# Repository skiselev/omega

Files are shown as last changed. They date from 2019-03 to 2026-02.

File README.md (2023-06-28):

# Omega
Omega Home Computer

[Lea este documento en español](README_es.md)

## Introduction
This project is an open source implementation of an MSX2 compatible computer. The project is built using a combination of 1980's era components - Z80 CPU, V9958 VDP, AY-3-8910/YM2149F PSG, 8255 PPI, 7400-series logic, and some newer components, such as 512 KiB SRAM and 512 KiB Flash ROM and a few simple programmable logic devices (ATF16V8B SPLDs).

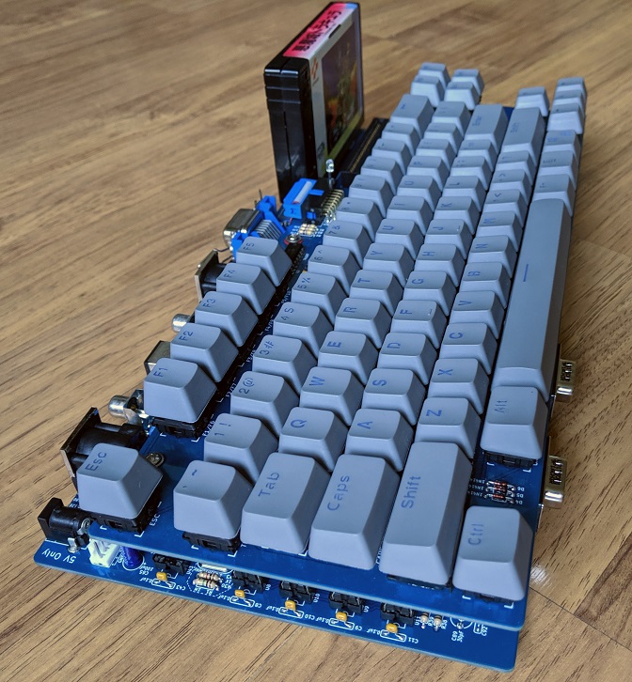
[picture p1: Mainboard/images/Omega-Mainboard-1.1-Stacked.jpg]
Omega System - Keyboard stacked on Main Board


## Status
* The project is completed, tested and works properly
* It is recommended to use the latest revision of the PCBs

## Documentation

[Keyboard](Keyboard.md)

[Main Board](Mainboard.md)

[Enclosure](Enclosure.md)

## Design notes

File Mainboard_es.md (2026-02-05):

# Omega Placa Base
Placa Base para el Omega Home Computer

[Read this document in English](Mainboard.md)

## Tabla de Contenido
* [Introducción](#introducción)
* [Especificaciones](#especificaciones)
* [Documentación del Hardware](#documentación-del-hardware)
  * [Esquema y diseño de la PCB](#esquema-y-diseño-de-la-pcb)
  * [Conectores](#conectores)
  * [Jumpers](#jumpers)
  * [Lista de componentes](#lista-de-componentes)
  * [Puertos de Entrada y Salida](#puertos-de-entrada-y-salida)
  * [Mapa de Slots](#mapa-de-slots)
* [Documentación del Firmware](#documentación-del-firmware)
  * [BIOS](#bios)
  * [Esquema de fusibles SPLD](#esquema-de-fusibles-spld)
* [Notas de la versión](#notas-de-la-versión)
  * [Cambios](#cambios)
  * [Problemas conocidos](#problemas-conocidos)

## Introducción
La Placa Base tiene implementada la funcionalidad del estándar MSX2*, tal como se describe en la siguiente sección de  [Especificaciones](#especificaciones). La Placa Base está diseñada para ser apilada bajo la placa del teclado para crear la típica forma de "Ordenador teclado" de los ordenadores domésticos de los 80.
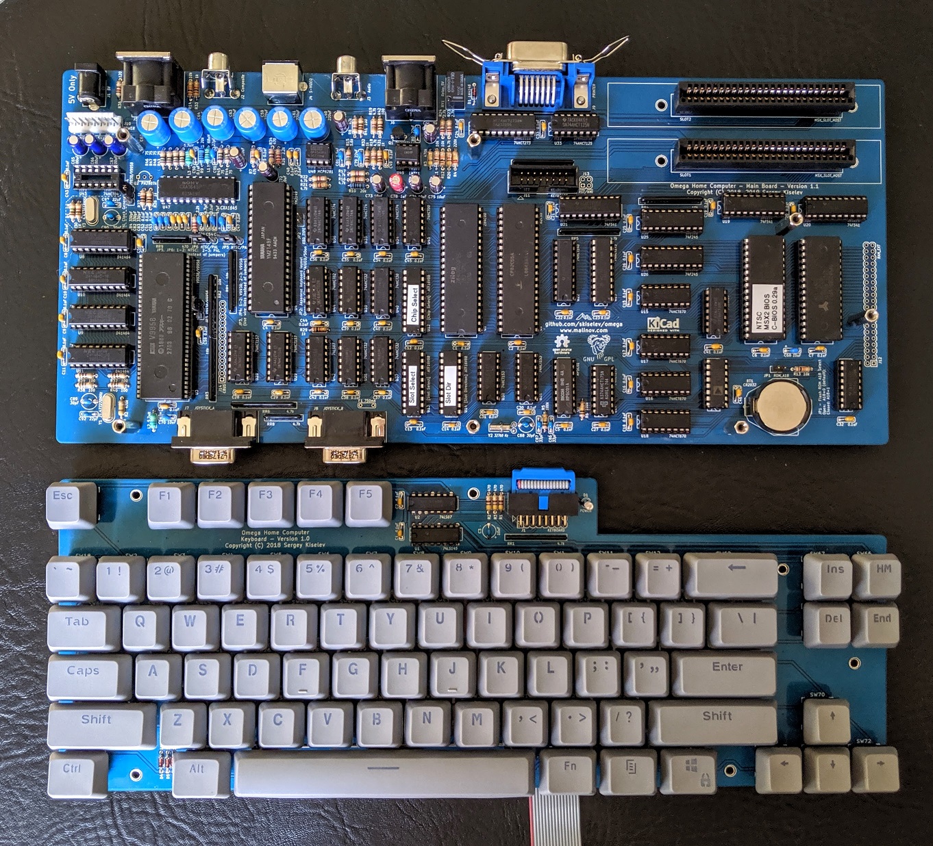
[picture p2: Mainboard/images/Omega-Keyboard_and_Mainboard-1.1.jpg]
Omega Mainboard connected to Keyboard
 

## Especificaciones
* Procesador: CPU Zilog Z80 (version CMOS - Z84C00) a 3.58 Mhz de reloj
* Memoria:
  * RAM: 512 KiB SRAM, ampliable a 4 MiB usando una placa hija opcional. Paginador de memoria compatible con MSX*. La RAM está mapeada en el slot 3-2
  * ROM: Flash ROM de 256 KiB o 512 KiB. La ROM está mapeada al slot 0 y los sub slots 3-0, 3-1 y 3-3.
* Video: VDP Yamaha V9958 o Yamaha V9938 
  * 128 KiB Video RAM
  * Salidas de video compuesto, S-Video, y RGB
* Audio: PSG Yamaha YM2149 o el AY-3-8910 de General Instruments.
* Dos slots para cartucho compatibles con MSX* 
* Teclado, Joysticks, e Interfaces para la Impresora y el reproductor de Cassette
* RTC: Ricoh RP5C01
* Supervisor del Microprocesador:
  * Generación de Reset
  * Battería de respaldo RTC
* BIOS: [C-BIOS](http://cbios.sourceforge.net/). Compatible con BIOS de ordenadores originales MSX2* con organización de slots y especificaciones de hardware similares como por ejemplo [Sanyo* PHC-23J](https://www.msx.org/wiki/Sanyo_PHC-23J)

## Documentación del Hardware

### Esquema y diseño de la PCB

[Esquematico - Version 1.5](Mainboard/KiCad/Omega-Mainboard-Schematic-1.5.pdf)

[Diseño de la PCB - Version 1.5](Mainboard/KiCad/Omega-Mainboard-Board-1.5.pdf)

### Conectores

#### J1 - Power (5V)
Conecta una fuente de alimentación regulada a +5V a este conector.

Nota: Los componentes de la placa usan solo voltajes de 5V. Algunos cartuchos pueden necesitar 12V/-12V adicionales. El conector J10 debe usarse en este caso

Pin | Descripción     
--- | ---------------
Pin (contacto interno) | Power: 5V (terminal positivo)
Tambor / Pantalla      |	Power: GND (terminal negativo)

#### J2 - Video Compuesto

Pin | Descripción     
--- | ---------------
Pin (contacto interno)| Salida: Video Compuesto
Anillo / Pantalla     |	Power: GND

#### J3 - Audio

Pin | Descripción     
--- | ---------------
Tip (contacto interno)| Salida: Audio (nivel de línea)
Anillo / Pantalla     |	Power: GND

#### J4 - S-Video

Pin | Descripción     
--- | ---------------
1, 2 | Power: GND
3    |	Salida: Luminancia (intensidad)
4    | Salida: Chrominancia (color)

#### J5 - RGB Conector
Pin | Descripción     
--- | ---------------
1   | Power: GND
2   |	Salida: Audio (nivel de línea)
3   |	Salida: AV (4.55V)
4   |	Salida: Video Compuesto
5   |	Salida: YS (3 V)
6   |	Salida: Rojo
7   | Salida: Verde
8   | Salida: Azul

#### J6 - Cassette Conector
Pin | Descripción     
--- | ---------------
1, 2, 3, 8   | Power: GND
4   |	Salida: Salida de audio hacia el grabador de cassette (nivel de microfono)
5   |	Entrada: Entrada de audio desde el grabador de cassette (nivel de línea)
6   |	Salida: Relé - Control de Motor
7   | Salida: Relé - Control de Motor

#### J7, J8 - Conectores de Joystick
Pin | Descripción     
--- | ---------------
1   | Entrada: Avanzar (norte / arriba)
2   | Entrada: Retroceder (sur / abajo)
3   | Entrada: Izquierda (oeste)
4   | Entrada: Derecha (este)
5   | Power: 5V
6   | Entrada: Botón 1
7   | Entrada: Botón 2
8   | Salida: Selección de Joystick
9   | Power: GND (tierra)

#### J9 - Conector de Impresora
Pin | Descripción     
--- | ---------------
1   | Salida: /STROBE (pulso)
2   | Salida: D0
3   | Salida: D1
4   | Salida: D2
5   | Salida: D3
6   | Salida: D4
7   | Salida: D5
8   | Salida: D6
9   | Salida: D7
10  | No conectado
11  | Entrada: BUSY (ocupado)
12  | No conectado
13  | No conectado
14  | Power: GND (tierra)

#### J10 - Power (5V, 12V, -12V)
Conecta una fuente de alimentación regulada 5V/12V/-12V a este conector.

Pin | Descripción     
--- | ---------------
1, 2, 3 | Power: GND
4, 5, 6 |	Power: 5V
7   |	Power: 12V
8   |	Power: -12V

#### J11 - Interfaz de Teclado 
Pin | Descripción     | Pin | Descripción
--- | --------------- | --- | ----------------
1   | Entrada: Columna 0 | 2   | Power: 5V
3   |	Entrada: Columna 1 | 4   | Salida: fila A
5   |	Entrada: Columna 2 | 6   | Salida: fila B
7   |	Entrada: Columna 3 | 8   | Salida: fila C
9   |	Entrada: Columna 4 | 10  | Salida: fila D
11  |	Entrada: Columna 5 | 12  | Salida: Bloq May LED
13  | Entrada: Columna 6 | 14  | Salida: Kana/Code LED
15  | Entrada: Columna 7 | 16  | Power: GND

#### J12 - Extensor SRAM
Pin | Descripción      | Pin | Descripción
--- | ---------------- | --- | ----------------
1   | Power: 5V        | 2   | Power: 5V
3   |	Salida: /RAM2_CS | 4   | Salida: /RAM1_CS
5   |	Salida: /RAM4_CS | 6   | Salida: /RAM3_CS
7   |	Salida: /RAM6_CS | 8   | Salida: /RAM5_CS
9   |	Salida: RAM_A18  | 10  | Salida: /RAM7_CS
11  |	Salida: RAM_A16  | 12  | Salida: RAM_A15 
13  | Salida: RAM_A14  | 14  | Salida: RAM_A17 
15  | Salida: A12      | 16  | Salida: /WR
17  | Salida: A7       | 18  | Salida: A13
19  | Salida: A6       | 20  | Salida: A8
21  | Salida: A5       | 22  | Salida: A9
23  | Salida: A4       | 24  | Salida: A11
25  | Salida: A3       | 26  | Salida: /RD
27  | Salida: A2       | 28  | Salida: A10
29  | Salida: A1       | 30  | Bi-direccional: MD7
31  | Salida: A0       | 32  | Bi-direccional: MD6
33  | Bi-direccional: MD0 | 34  | Bi-direccional: MD5
35  | Bi-direccional: MD1 | 36  | Bi-direccional: MD4
37  | Bi-direccional: MD2 | 38  | Bi-direccional: MD3
39  | Power: GND       | 40  | Power: GND

#### J13 - Conector /RST and /NMI
Pin | Descripción     | Pin | Descripción
--- | --------------  | --- | -----------
1   | In/Out: /RESET  | 2   | Power: GND
3   | Entrada: /NMI   | 4   | Power: GND

#### J14 - Bus de color VDP 
Pin | Descripción
--- | -----------
1   | Power: 5V
2   | Salida: /DHCLK
3   | Salida: /DLCLK
4   | Salida: CBDR
5   | In/Out: CB7
6   | In/Out: CB6
7   | In/Out: CB5
8   | In/Out: CB4
9   | In/Out: CB3
10  | In/Out: CB2
11  | In/Out: CB1
12  | In/Out: CB0
13  | Power: GND

### Jumpers

#### JP1 - ROM_A18
JP1 selecciona la seccion de 256 KiB (mitad inferior o mitad superiro) de la memoria Flash ROM que se mapea como ROM del sistema o slot.

Jumper Position	| Descripción
--------------- | -----------
Abierto*        | selecciona las direcciones 0x00000 - 0x3FFFF del chip ROM
Cerrado         | selecciona las direcciones 0x40000 - 0x7FFFF del chip ROM

#### JP2 - KBD_TYPE
JP2 selecciona la configuración de teclado japonés

Jumper Position | Descripción
--------------- | -----------
Abierto*        | configuración JIS
Cerrado         | configuración ANSI/AIUEO/50on

#### JP3, JP4 - V9938/V9958
JP3 y JP4 seleccionan el tipo de VDP a usar. JP3 conecta el Pin 21 del VDP, bien con una resistencia de 470 ohm (pull-up) (V9938, Salida de video compuesto deshabilitada), o bien a 5V (V9958, alimentación de DAC). JP4 selecciona si la salida CSYNC del VDP va directamente al codificador RGB (V9958) o a un circuito convertidor de nivel (V9938).

*Aviso: Un ajuste erroneo del JP3 dañará el VDP*

Posición del Jumper | Descripción
------------------- | -----------
1-2                 | V9938 VDP
2-3                 | V9958 VDP

#### JP5, JP6 - NTSC/PAL
Los Jumpers JP5 y JP6 seleccionan el sistema codificacior de color para la salida de Video. Para ser más específicos, el JP5 configura el codificador RGB y el JP6 selecciona la frecuencia sub-portadora de color.

*Nota: Algunos componentes se usan solamente para generar la frecuencia sub-portadora del sistema PAL y pueden ser omitidos si se usa el codificador NTSC. Mira la Lista de componentes para más información*

Posición del Jumper| Descripción
------------------ | -----------
1-2                | NTSC
2-3                | PAL

### Lista de Componentes

[Proyecto de Placa Base para Omega en Mouser.com](https://www.mouser.com/ProjectManager/ProjectDetail.aspx?AccessID=11fd34d22c) - Puedes ver y encargar todos los componentes exceptuando la PCB, El Yamaha VDP V9958, el Ricoh RTC RP5C01, La DRAM NEC D41464, el Codificador RGB Sony CXA1645P y la pila CR2032.

Component type     | Reference | Description                                 | Quantity | Possible sources and notes
------------------ | --------- | ------------------------------------------- | -------- | --------------------------
PCB                |           | PCB Omega Placa Base - Version 1.1          | 1        | dirigirse a [RetroBrew Computers Board Inventory](https://retrobrewcomputers.org/doku.php?id=boardinventory) para instrucciones de pedido, o pedir al fabricante PCB de tu elección usando los Gerber proveidos o los ficheros de KiCad.
Circuito Integrado | U1        | Z80 CPU, CMOS, 40 pin DIP - Z84C00xxPEG     | 1        | Mouser [692-Z84C0010PEG](https://www.mouser.com/ProductDetail/692-Z84C0010PEG)
Circuito Integrado | U2        | 82C55 PPI, CMOS, 40 pin DIP - CP82C55AZ     | 1        | Mouser [968-CP82C55A-5Z](https://www.mouser.com/ProductDetail/968-CP82C55A-5Z)
Circuito Integrado | U3        | V9958 VDP, 64 pin DIP                       | 1        | eBay. Nota: V9938 VDP puede ser utilizada en su lugar
Circuito Integrado | U4        | YM2149 PSG, 40 pin DIP or AY-3-8910         | 1        | eBay
Circuito Integrado | U5        | RP5C01 RTC, 18 pin DIP                      | 1        | eBay
Circuito Integrado | U6        | 512 KiB Flash ROM, 32 pin DIP - SST39SF040  | 1        | Mouser [804-39SF0407CPHE](https://www.mouser.com/ProductDetail/804-39SF0407CPHE)
Circuito Integrado | U7        | 512 KiB SRAM, 32 pin DIP - AS6C4008         | 1        | Mouser [913-AS6C4008-55PCN](https://www.mouser.com/ProductDetail/913-AS6C4008-55PCN)
Circuito Integrado | U8 - U11  | D41464, 64K x 4 DRAM, 18 pin DIP            | 4        | eBay
Circuito Integrado | U12 - U14 | Simple Programmable Logic Device - ATF16V8B | 3        | Mouser [556-AF16V8B15PU](https://www.mouser.com/ProductDetail/556-AF16V8B15PU)
Circuito Integrado | U15 - U18 | 4-by-4 Register File - 74HC670, 16 pin DIP  | 4        | Mouser [595-CD74HC670E](https://www.mouser.com/ProductDetail/595-CD74HC670E)
Circuito Integrado | U19 - U21 | 74F541, 20 pin DIP                          | 3        | Mouser [595-SN74F541N](https://www.mouser.com/ProductDetail/595-SN74F541N)
Circuito Integrado | U22       | 74HCT540, 20 pin DIP                        | 1        | Mouser [595-SN74HCT540N](https://www.mouser.com/ProductDetail/595-SN74HCT540N)
Circuito Integrado | U23, U24  | 74HCT273, 20 pin DIP                        | 2        | Mouser [595-SN74HCT273N](https://www.mouser.com/ProductDetail/595-SN74HCT273N). Nota U24 es opcional - soporte a puerto impresora.
Circuito Integrado | U25, U26  | 74F245, 20 pin DIP                          | 2        | Mouser [595-SN74F245N](https://www.mouser.com/ProductDetail/595-SN74F245N)
Circuito Integrado | U27       | 74HCT175, 16 pin DIP                        | 1        | Mouser [595-CD74HCT175E](https://www.mouser.com/ProductDetail/595-CD74HCT175E)
Circuito Integrado | U28, U29  | 74HCT157, 16 pin DIP                        | 2        | Mouser [595-SN74HCT157N](https://www.mouser.com/ProductDetail/595-SN74HCT157N)
Circuito Integrado | U30, U31  | 74HCT153, 16 pin DIP                        | 2        | Mouser [595-CD74HCT153E](https://www.mouser.com/ProductDetail/595-CD74HCT153E)
Circuito Integrado | U32       | 74AHCT138, 16 pin DIP                       | 1        | Mouser [595-SN74AHCT138N](https://www.mouser.com/ProductDetail/595-SN74AHCT138N)
Circuito Integrado | U33       | 74AHCT125, 14 pin DIP                       | 1        | Mouser [595-SN74AHCT125N](https://www.mouser.com/ProductDetail/595-SN74AHCT125N). Nota U33 es opcional - soporte a puerto impresora.
Circuito Integrado | U34 - U36 | Dual Flip Flop - 74HCT74, 14 pin DIP        | 3        | Mouser [595-SN74HCT74N](https://www.mouser.com/ProductDetail/595-SN74HCT74N)
Circuito Integrado | U37 - U39 | 74AHCT32, 14 pin DIP                        | 3        | Mouser [595-SN74AHCT32N](https://www.mouser.com/ProductDetail/595-SN74AHCT32N)
Circuito Integrado | U40, U41  | 74HCT30, 14 pin DIP                         | 2        | Mouser [595-CD74HCT30E](https://www.mouser.com/ProductDetail/595-CD74HCT30E)
Circuito Integrado | U42       | 74LS07, 14 pin DIP                          | 1        | Mouser [595-SN74LS07N](https://www.mouser.com/ProductDetail/595-SN74LS07N)
Circuito Integrado | U43       | 74HCT04, 14 pin DIP                         | 1        | Mouser [595-SN74HCT04N](https://www.mouser.com/ProductDetail/595-SN74HCT04N)
Circuito Integrado | U44       | 74AHCT02, 14 pin DIP                        | 1        | Mouser [595-SN74AHCT02N](https://www.mouser.com/ProductDetail/595-SN74AHCT02N)
Circuito Integrado | U45       | 74HCT00, 14 pin DIP                         | 1        | Mouser [595-SN74HCT00N](https://www.mouser.com/ProductDetail/595-SN74HCT00N)
Circuito Integrado | U46       | Microprocessor Supervisory Circuit - ADM691A | 1        | Mouser [584-ADM691AANZ](https://www.mouser.com/ProductDetail/584-ADM691AANZ); Alternativas válidas: MAX691, LTC691, ADM691
Circuito Integrado | U47       | Sony CXA1645P RGB Encoder, 24 pin DIP-400   | 1        | eBay
Circuito Integrado | U48       | MCP6281-E/P Operational Amplifier, 8 pin DIP | 1       | Mouser [579-MCP6281-E-P](https://www.mouser.com/ProductDetail/579-MCP6281-E-P)
Circuito Integrado | U49       | LM311N, Voltage Comparator, 8 pin DIP       | 1        | Mouser [926-LM311N-NOPB](https://www.mouser.com/ProductDetail/926-LM311N-NOPB). Nota U49 es opcional - soporte grabador cassette.
Condensador        | C1 - C58  | 0.1 uF, MLCC, 5 mm Pitch                    | 58       | Mouser [594-K104K15X7RF53H5](https://www.mouser.com/ProductDetail/594-K104K15X7RF53H5)
Condensador        | C59 - C64 | 220 uF, Electrolitico                       | 6        | Mouser [647-UBW1E221MPD](https://www.mouser.com/ProductDetail/647-UBW1E221MPD). Nota C62 - C64 opcional - soporte salida RGB
Condensador        | C65 - C67 | 100 uF, 16V, Polimero organico de aluminio  | 3        | Mouser [80-A750EK107M1CAAE18](https://www.mouser.com/ProductDetail/80-A750EK107M1CAAE18)
Condensador        | C68 - C70 | 10 uF, MLCC, 5 mm Pitch                     | 3        | Mouser [810-FG28X5R1E106MR00](https://www.mouser.com/ProductDetail/810-FG28X5R1E106MR00). Nota C71 opcional - soporte grabador cassette.
Condensador        | C71 - C77 | 10 uF, Electrolytic                         | 7        | Mouser [667-EEU-FR1H100](https://www.mouser.com/ProductDetail/667-EEU-FR1H100). Nota C71 opcional - soporte grabador cassette.
Condensador        | C78       | 1 uF, Electrolytic                          | 1        | Mouser [710-860020672005](https://www.mouser.com/ProductDetail/710-860020672005). Nota C78 opcional - soporte grabador cassette.
Condensador        | C79, C80  | 22 nF, MLCC, 5 mm Pitch                     | 2        | Mouser [810-FG28X7R1H223KNT0](https://www.mouser.com/ProductDetail/810-FG28X7R1H223KNT0). Nota C79, C80 opcional - soporte grabador cassette.
Condensador        | C81       | 1.5 nF, MLCC, 5 mm Pitch                    | 1        | Mouser [810-FG28C0G1H152JNT0](https://www.mouser.com/ProductDetail/810-FG28C0G1H152JNT0)
Condensador        | C82 - C84 | 330 pF, MLCC, 5 mm Pitch                    | 3        | Mouser [810-FG28C0G1H331JNT0](https://www.mouser.com/ProductDetail/810-FG28C0G1H331JNT0)
Condensador        | C85       | 47 pF, MLCC, 5 mm Pitch                     | 1        | Mouser [810-FG28C0G1H470JNT0](https://www.mouser.com/ProductDetail/810-FG28C0G1H470JNT0)
Condensador        | C86, C87  | 33 pF, MLCC, 5 mm Pitch                     | 2        | Mouser [810-FG28C0G1H330JNT0](https://www.mouser.com/ProductDetail/810-FG28C0G1H330JNT0)
Condensador        | C88 - C90 | 30 pF, Trim Capactiors, 5 mm Pitch          | 3        | DigiKey [2447-GKG30015-ND](https://www.digikey.es/es/products/detail/ew-electronics/GKG30015/11689271). Nota: Puede ser reemplazado por Mouser [810-FG28C0G2A270JNT0](https://www.mouser.com/ProductDetail/810-FG28C0G2A270JNT0) si no es necesario ajustar la frecuencia portadora de color.
Condensador        | C91       | 27 pF, MLCC, 5 mm Pitch                     | 1        | Mouser [810-FG28C0G2A270JNT0](https://www.mouser.com/ProductDetail/810-FG28C0G2A270JNT0). Nota C91 debe ser de 18 pF para soporte PAL.
Condensador        | C92, C93  | 22 pF, MLCC, 5 mm Pitch                     | 2        | Mouser [810-FG28C0G1H220JNT0](https://www.mouser.com/ProductDetail/810-FG28C0G1H220JNT0)
Condensador        | C94       | 4.7 pF, MLCC, 5 mm Pitch                    | 1        | Mouser [810-FG28C0G1H4R7CNT0](https://www.mouser.com/ProductDetail/810-FG28C0G1H4R7CNT0)
Matriz Resistencias| RR1 - RR4 | 10 kohm, en bus, 10 pin SIP                 | 4        | Mouser [652-4610X-1LF-10K](https://www.mouser.com/ProductDetail/652-4610X-1LF-10K) o Mouser [652-4610X-AP1-103LF](https://www.mouser.com/ProductDetail/652-4610X-AP1-103LF)
Matriz Resistencias| RR5 - RR7  | 4.7 kohm, en bus, 10 pin SIP               | 3        | Mouser [652-4610X-1LF-4.7K](https://www.mouser.com/ProductDetail/652-4610X-1LF-4.7K) o Mouser [652-4610X-AP1-472LF](https://www.mouser.com/ProductDetail/652-4610X-AP1-472LF)
Matriz Resistencias| RR8       | 4.7 kohm, en bus, 6 pin SIP                 | 1        | Mouser [652-4606X-1LF-4.7K](https://www.mouser.com/ProductDetail/652-4606X-1LF-4.7K) o Mouser [652-4606X-AP1-472LF](https://www.mouser.com/ProductDetail/652-4606X-AP1-472LF)
Matriz Resistencias| RR9       | 470 ohm, en bus, 6 pin SIP                  | 1        | Mouser [652-4606X-1LF-470](https://www.mouser.com/ProductDetail/652-4606X-1LF-470) o Mouser [652-4606X-AP1-471LF](https://www.mouser.com/ProductDetail/652-4606X-AP1-471LF)
Resistencia        | R1        | 1 Mohm, axial                               | 1        | Mouser [603-MFR-25FBF52-1M](https://www.mouser.com/ProductDetail/603-MFR-25FBF52-1M). Nota R1 is opcional - soporte PAL.
Resistencia        | R2, R3    | 470 kohm, axial                             | 2        | Mouser [603-MFR-25FBF52-470K](https://www.mouser.com/ProductDetail/603-MFR-25FBF52-470K)
Resistencia        | R4        | 220 kohm, axial                             | 1        | Mouser [603-MFR-25FBF52-220K](https://www.mouser.com/ProductDetail/603-MFR-25FBF52-220K)
Resistencia        | R5, R6    | 100 kohm, axial                             | 2        | Mouser [603-MFR-25FBF52-100K](https://www.mouser.com/ProductDetail/603-MFR-25FBF52-100K)
Resistencia        | R7, R8    | 47 kohm, axial                              | 2        | Mouser [603-MFR-25FBF52-47K](https://www.mouser.com/ProductDetail/603-MFR-25FBF52-47K)
Resistencia        | R9, R10   | 20 kohm, 1% tolerancia, axial               | 2        | Mouser [603-MFR-25FBF52-20K](https://www.mouser.com/ProductDetail/603-MFR-25FBF52-20K). Nota R9 debe ser 16 kohm, 1% para soporte PAL.
Resistencia        | R11 - R14 | 10 kohm, axial                              | 4        | Mouser [603-MFR-25FBF52-10K](https://www.mouser.com/ProductDetail/603-MFR-25FBF52-10K). Nota R11, R12 son opcionales - soporte grabador cassette.  Nota R14 es opcional - soporte salida RGB.
Resistencia        | R15       | 5.6 kohm, axial                             | 1        | Mouser [603-MFR-25FBF52-5K6](https://www.mouser.com/ProductDetail/603-MFR-25FBF52-5K6)
Resistencia        | R16 - R22 | 4.7 kohm, axial                             | 7        | Mouser [603-MFR-25FBF52-4K7](https://www.mouser.com/ProductDetail/603-MFR-25FBF52-4K7). Note R18 - R20 son opcionales - soporte grabador cassette.
Resistencia        | R23, R24  | 2.7 kohm, axial                             | 2        | Mouser [603-MFR-25FBF52-2K7](https://www.mouser.com/ProductDetail/603-MFR-25FBF52-2K7). Note R23, R24 son opcionales - soporte grabador cassette.
Resistencia        | R25, R26  | 2.2 kohm, axial                             | 2        | Mouser [603-MFR-25FBF52-2K2](https://www.mouser.com/ProductDetail/603-MFR-25FBF52-2K2)
Resistencia        | R27 - R33 | 1 kohm, axial                               | 7        | Mouser [603-MFR-25FBF52-1K](https://www.mouser.com/ProductDetail/603-MFR-25FBF52-1K). Nota R31, R32 son opcionales - soporte grabador cassette. Nota R33 es opcional - soporte salida RGB.
Resistencia        | R34       | 470 ohm, axial                              | 1        | Mouser [603-MFR-25FBF52-470R](https://www.mouser.com/ProductDetail/603-MFR-25FBF52-470R) 
Resistencia        | R35       | 180 ohm, axial                              | 1        | Mouser [603-MFR-25FBF52-180R](https://www.mouser.com/ProductDetail/603-MFR-25FBF52-180R). Nota R35 es opcional - soporte salida RGB.
Resistencia        | R36       | 120 ohm, axial                              | 1        | Mouser [603-MFR-25FBF52-120R](https://www.mouser.com/ProductDetail/603-MFR-25FBF52-120R). Nota R36 es opcional - soporte salida RGB.
Resistencia        | R37 - R42 | 100 ohm, axial                              | 6        | Mouser [603-MFR-25FBF52-100R](https://www.mouser.com/ProductDetail/603-MFR-25FBF52-100R). Nota R42 es opcional - soporte grabador cassette.
Resistencia        | R43 - R48 | 75 ohm, axial                               | 6        | Mouser [603-MFR-25FBF52-75R](https://www.mouser.com/ProductDetail/603-MFR-25FBF52-75R). Nota R46 - R48 opcional - soporte salida RGB.
Rele               | RY1       | 5V SPDT rele                                | 1        | Mouser [653-G5V-1-DC5](https://www.mouser.com/ProductDetail/653-G5V-1-DC5) o Mouser [653-G5V-1-T90-DC5](https://www.mouser.com/ProductDetail/653-G5V-1-T90-DC5)
Inductor           | L1        | 68 uH, axial                                | 1        | Mouser [542-78F680-RC](https://www.mouser.com/ProductDetail/542-78F680-RC)
Inductor           | L2, L3    | 5.7 uH, axial                               | 2        | Mouser [542-78F5R6J-RC](https://www.mouser.com/ProductDetail/542-78F5R6J-RC)
Diodo              | D1        | 1N4148                                      | 1        | Mouser [512-1N4148TR](https://www.mouser.com/ProductDetail/512-1N4148TR). Nota D1 es opcional - soporte grabador cassette.
Transistor         | Q1, Q2    | PN2907A                                     | 2        | Mouser [512-PN2907ATF](https://www.mouser.com/ProductDetail/512-PN2907ATF). Nota Q1 es opcional - soporte grabador cassette.
Cristal            | Y1        | 21.477270 MHz                               | 1        | Mouser [695-HC49US-214-U](https://www.mouser.com/ProductDetail/695-HC49US-214-U)
Cristal            | Y2        | 32768 Hz                                    | 1        | Mouser [815-AB38T-32.768KHZ](https://www.mouser.com/ProductDetail/815-AB38T-32.768KHZ)
Cristal            | Y3        | 4.433618 MHz                                | 1        | Mouser [520-HCU443-20X](https://www.mouser.com/ProductDetail/520-HCU443-20X). Nota Y3 es opcional - soporte PAL.
Fusible            | F1        | 750 mA, radial, 5 mm pitch                  | 1        | Mouser [650-RUSBF075-2](https://www.mouser.com/ProductDetail/650-RUSBF075-2)
Conector           | J1        | DC Power Jack, 2mm                          | 1        | Mouser [806-KLDX-0202-A](https://www.mouser.com/ProductDetail/806-KLDX-0202-A)
Conector           | J2        | conector RCA Phono, Amarillo                | 1        | Mouser [490-RCJ-014](https://www.mouser.com/ProductDetail/490-RCJ-014)
Conector           | J2        | conector RCA Phono, Blanco                  | 1        | Mouser [490-RCJ-013](https://www.mouser.com/ProductDetail/490-RCJ-013)
Conector           | J4        | Mini DIN 4-pos, angulo recto, montaje PCB   | 1        | Mouser [490-MD-40SM](https://www.mouser.com/ProductDetail/490-MD-40SM)
Conector           | J5, J6    | DIN 8-pos, angulo recto, montaje PCB        | 2        | Mouser [490-SDF-80J](https://www.mouser.com/ProductDetail/490-SDF-80J). Nota J5 es opcional - soporte RGB; J6 es opcional - soporte grabador cassette.
Conector           | J7, J8    | Sub-D DE9M, angulo recto, montaje PCB       | 2        | Mouser [523-L717SDE09P1ACH3R](https://www.mouser.com/ProductDetail/523-L717SDE09P1ACH3R)
Conector           | J9        | Micro Ribbon 14-pos, hembra, ang. recto, montaje PCB | 1        | Mouser [636-112-014-213R001](https://www.mouser.com/ProductDetail/636-112-014-213R001). Nota J9 es opcional - soporte puerto impresora.
Conector           | J10       | 8 pin conector bloqueo anclaje              | 1        | Mouser [571-6404568](https://www.mouser.com/ProductDetail/571-6404568)
Conector           | J11       | 2x8 pin header, shrouded                    | 1        | Mouser [710-61201621621](https://www.mouser.com/ProductDetail/710-61201621621)
Conector           | J12       | 2x20 pin zocalo                             | 1        | Mouser [517-929852-01-20-RB](https://www.mouser.com/ProductDetail/517-929852-01-20-RB)
Conector           | J13       | 2x2 pin header                              | 1        | Nota: Opcional /RESET y /NMI header
Conector           | J14       | 1x13 pin header                             | 1        | Note: Opcional conector Bus Color
Conector           | SLOT1, SLOT2 | conector 50 pin borde de tarjeta         | 2        | Mouser [571-5530843-5](https://www.mouser.com/ProductDetail/571-5530843-5)
Jumper             | JP1, JP2  | 2 pin header                                | 2        | Mouser [649-78229-102HLF](https://www.mouser.com/ProductDetail/649-78229-102HLF)
Jumper             | JP3 - JP6 | Wire link                                   | 4        | conexión por cable (puente)
Zocalo Bateria     | BT1       | Zocalo Bateria CR2032                       | 1        | Mouser [122-2420-GR](https://www.mouser.com/ProductDetail/122-2420-GR)
Bateria            | BT1       | CR2032 Batteria                             | 1        | Mouser [614-CR2032-200](https://www.mouser.com/ProductDetail/614-CR2032-200), [658-CR2032](https://www.mouser.com/ProductDetail/658-CR2032). Nota: No incluido en el projecto de Mouser Project debido a restricciones de envío.
Zocalo CI          | U1, U2, U4 | 40 pin DIP                                 | 3        | Mouser [517-4840-6000-CP](https://www.mouser.com/ProductDetail/517-4840-6000-CP)
Zocalo CI          | U3        | 64 pin DIP                                  | 1        | eBay
Zocalo CI          | U3        | 64 pin DIP (alternativa)                    | 1        | DigiKey [117-87-764-41-005101](https://www.digikey.es/es/products/detail/preci-dip/117-87-764-41-005101/3757318)
Zocalo CI          | U6, U7    | 32 pin DIP                                  | 2        | Mouser [517-4832-6000-CP](https://www.mouser.com/ProductDetail/517-4832-6000-CP)
Zocalo CI          | U47       | 24 pin DIP, 400 mil spacing                 | 1        | Mouser [517-4824-6000-CP](https://www.mouser.com/ProductDetail/517-4824-6000-CP) or [517-4824-3000-CP](https://www.mouser.com/ProductDetail/517-4824-3000-CP). Nota: Cortar el zocalo por la mitad. Si se usa un zócalo de tamaño 0.600", recortar el sobrante. Como alternativa soldar U47 (CXA1645P) sin zócalo.
Zocalo CI          | U47       | 24 pin DIP, 400 mil spacing (alternativa)   | 1        | DigiKey [110-93-424-41-001000](https://www.digikey.es/es/products/detail/mill-max-manufacturing-corp/110-93-424-41-001000/81797)
Zocalo CI          | U12 - U14, U19 - U26 | 20 pin DIP                       | 11       | Mouser [517-4820-3000-CP](https://www.mouser.com/ProductDetail/517-4820-3000-CP)
Zocalo CI          | U5, U8 - U11 | 18 pin DIP                               | 5        | Mouser [517-4818-3000-CP](https://www.mouser.com/ProductDetail/517-4818-3000-CP)
Zocalo CI          | U15 - U18, U27 - U32, U46 | 16 pin DIP                  | 11       | Mouser [517-4816-3000-CP](https://www.mouser.com/ProductDetail/517-4816-3000-CP)
Zocalo CI          | U33 - U45 | 14 pin DIP                                  | 13       | Mouser [517-4814-3000-CP](https://www.mouser.com/ProductDetail/517-4814-3000-CP)
Zocalo CI          | U48, U49  | 8 pin DIP                                   | 2        | Mouser [517-4808-3000-CP](https://www.mouser.com/ProductDetail/517-4808-3000-CP)

### Opciones de Configuración y Notas sobre la sustitución de Componentes

#### Soporte del Estándar de Video NTSC
La Placa Base del Omega puede ser configurada para funcionar tanto con el estándar de video NTSC (60 Hz) como con PAL (50 Hz). Para hacer funcionar el estándar NTSC la placa debe ser configurada como sigue: 

* No inserte los siguientes componentes (sólo son necesarios para la configuración PAL)
  * Oscilador de Cristal de Cuarzo: Y3
  * Condensadores: C43, C90, C93
  * Resistencias: R1, R30 
  * Circuito Integrado: U43
  * Nota: C43 y U43 también se usan para el convertidor de nivel CSYNC del VDP V9938. Deberan ser instalados en caso de utilizar este.
* Suelde un cable que una JP5 y JP6 en la posición 1-2 para fijar la configuración en NTSC estándar.

#### Soporte del Estándar de Video PAL
Para utilizar el estándar PAL la configuración debe ser como sigue:
* Inserte los siguientes componentes:
  * Oscilador de Cristal de Cuarzo: Y3
  * Condensadores: C43, C90, C93
  * Resistencias: R1, R30
  * Circuito Integrado: U43
* Reemplaze los siguientes componentes:
  * R9 use una resistencia de 16 kohm (en lugar de 20 kohm)
  * C91 use un condensador de 18 pF (en lugar de 27 pF)
* Suelde un cable que una JP5 y JP6 en la posición 2-3 para fijar la configuración en PAL estándar.

### Soporte para VDP V9958
La Placa Base del Omega puede ser configurada para funcionar tanto con el VDP V9958 (recomendado) como con el  V9938. Para hacerlo funcionar con el V9958 la configuración la siguiente: 
* No instale los siguientes componentes:
  * Transistor: Q2
  * Condensador: C43
  * Circuito Integrado: U43
  * Nota: C43 y U43 también se usan para el generador de reloj PAL (clock). Deberá instalarlo si pretende utilizar el estándar de video PAL.
* Suelde un cable que una JP3 y JP4 en la posición 2-3 para el VDP V9958.

### Soporte para VDP V9938
Para hacerlo funcionar con el VDP V9938 la configuración debe ser de la siguiente manera: 
* Inserte los siguientes componentes:
  * Transistor: Q2
  * Condensador: C43
  * Circuito Integrado: U43
* Suelde un cable que una JP3 y JP4 en la posición 1-2 para VDP V9958
* *Aviso: Una configuración erronea del JP3 dañará el VDP*
  
### Puertos de entrada y salida

* 0x90 - 0x91 (alias 0x92 - 0x93) - Puerto de Impresora
  * 0x90: Escritura: Pulso (Strobe) (Bit 0)
  * 0x90: Lectura: Ocupado (Busy) (Bit 1)
  * 0x91: Escritura: Dato
* 0x98 - 0x9B - V9938 Video Display Processor (VDP)
  * 0x98: Lectura/Escritura: Dato de VRAM
  * 0x99: Escritura: Selecctor de registro/Dirección VRAM
  * 0x99: Lectura: Registro de estado
  * 0x9A: Acceso paleta
  * 0x9B: Registro de Acceso Indirecto
* 0xA0 - 0xA2 - YM2149 Generador de sonido programable (PSG)
  * 0xA0: Escritura: Selector de registro
  * 0xA1: Escritura: Valor del registro (dato)
  * 0xA2: Lectura: Valor del registro (dato)
* 0xA8 - 0xAB - 8255 Interfaz parallelo programable (PPI)
  * 0xA8: i8255: Puerto A - Registro de selección de slot primario
  * 0xA9: i8255: Puerto B - Registro de entrada, fila de la matriz de teclado
  * 0xAA: i8255: Puerto C - Registro de salida, columna de la matriz de teclado e interfaz de cassette
  * 0xAB: i8255: Registro de commandos
* 0xB4 - 0xB5 (alias 0xB6 - 0xB7) - RP5C01 Reloj en tiempo real (RTC)
  * 0xB4: RTC: Escritura: Selector de registro
  * 0xB5: RTC: Lectura/Escritura: dato de RTC
* 0xFC - 0xFF - Selector de pagina de memoria
  * 0xFC: Lectura/Escritura: Pagina 0
  * 0xFD: Lectura/Escritura: Pagina 1
  * 0xFE: Lectura/Escritura: Pagina 2
  * 0xFF: Lectura/Escritura: Pagina 3
* 0xFFFF (Memory I/O, slot 3) - Registro selector de sub slot

### Mapa de Slots
* Slot 0
  * 0x0000 - 0x7FFF (32 KiB): ROM principal, mapeada a la ROM 0x00000 - 0x07FFF
  * 0x8000 - 0xBFFF (16 KiB): ROM Logo, mapeada a la ROM 0x08000 - 0x0BFFF
  * 0xC000 - 0xFFFF (16 KiB): Sin uso
* Slot 1: Slot de cartucho 1
* Slot 2: Slot de cartucho 2
* Slot 3: Slot expandido
* Slot 3, Sub slot 0
  * 0x0000 - 0x3FFF (16 KiB): Sub ROM, mapeado a la ROM 0x10000 - 0x13FFF
* Slot 3, Sub slot 1
  * 0x0000 - 0xFFFF (64 KiB): ROM de usuario #1, mapeada a la ROM 0x20000 - 0x2FFFF
* Slot 3, Sub slot 2
  * 0x0000 - 0xFFFF (64 KiB): RAM principal (mapeador de memoria)
* Slot 3, Sub slot 3
  * 0x0000 - 0xFFFF (64 KiB): ROM de usuario #2, mapeada a la ROM 0x30000 - 0x3FFFF

## Documentación del Firmware

### BIOS

El Omega funciona con [C-BIOS](https://sourceforge.net/projects/cbios/) - una BIOS open source para ordenadores MSX.
También puede funcionar con BIOS MSX2* originales de ordenadores con organización de slot y especificaciones hardware similares como por ejemplo el [Sanyo* PHC-23J](https://www.msx.org/wiki/Sanyo_PHC-23J) y el [Philips* NMS 8250](https://www.msx.org/wiki/Philips_NMS_8250). 

### Esquema de fusibles SPLD
El Omega usa tres SPLDs ATF16V8/GAL16V8 (U12 - U14) para decodificación de direcciones y otras lógicas varias. Los esquemas de fusibles SPLD (ficheros JED) están disponibles en la carpeta [Mainboard/SPLD](Mainboard/SPLD) de este repositorio. Los SPLDs son implementados usando tecnología Flash/EEPROM y pueden ser programados con los programadores de EEPROM disponibles habitualmente tales como el MiniPro TL866.
Los ficheros con el código fuente (PLD) también están disponibles en la carpeta mencionada anteriormente. Si fuese necesario pueden ser modificados para, por ejemplo, cambiar el mapeo de slots. Usa [GALasm](https://github.com/daveho/GALasm) para compilar los ficheros PLD y obtner sus esquemas de fusibles JED.

## Notas de la versión

### Cambios
* Versión 1.2
  * Solucionados los problemas conocidos de la versión 1.1
* Versión 1.1
  * Solucionados los problemas conocidos de la versión 1.0
  * Uso de conectores DIN-8 con patillaje estándar del MSX/MSX2 para salida RGB y el interfaz de Cassette
  * Movidas las resistencias pull-ups del teclado hacía la Placa Base.
  * Añadidos filtros LC para el codificador RGB y VDP
  * Añadido conector para RESET / NMI
  * Conectados a GND los pines 44 y 46 de los slots
  * Añadido un fusible para los puertos de joystick
  * Soporte para V9938/V9958: Añadido un conmutador (JP4) para seleccionar entre: el elevador de nivel en CSYNC a TTL (para V9938) o conectar directamente CSYNC (para V9958)
  * Añadido un conector de cabecera para Bus de Color
  * Uso del supervisor de microprocesador ADM691A

* Version 1.0
  * Versión inicial 

## Problemas conocidos
* Version 1.1
  * Serigrafía superior: R30 debería ser 1k (minúsculas 'k')
  * Serigrafía superior: L2 y L3 deberían ser 5.6uH

* Version 1.0
  * Serigrafía superior: Referencias R8 y R36 están intercambiadas. Los valores están correctamente indicados en la serigrafía.
  * Serigrafía superior: Los valores de C48 y C82 están intercambiados. C48 debería ser 0.1 uF, y C82 debería ser 1.5nF.
  * Serigrafía superior: La línea de puntos que define el generador de reloj PAL debería incluir también U43 y C43.
  * Serigrafía superior: "M" logo and the project URL are missing.
  * Esquemático: El patillaje para el integrado 74AHCT32 IC (U37 - U39) está incorrecto.
  * Esquemático: Las señales /RD y /WR en el sub-slot de selección de registros están intercambiadas (U38C, U32D).
  * PCB: Conector de teclado (J11) interfiere  con el pestillo del puerto de impresora (U24). Usar un conector de cabecera recto en lugar de uno en ángulo recto.
  * Esquemático: Se requiere un pull-up en /INT Salida (pin 25) del V9938 VDP,porque es una salida colector abierto.
  * PCB: Los slots para cartucho tienen que ser rotados 180 grados. El Pin 1 del slot de cartuchos debe estar en la posición de arriba a la izquierda.
  * Esquemático: El C.I. CXA1645 necesita nivel TTL para SYNCIN, mientras que el V9938 suministra 2.4 V - 4.8 V al CSYNC. Un elevador de nivel es necesario.
  * Esquemático: PSG el divisor de reloj 74HCT74 U35A Salida /Q (pin 6) debe ser conectado con la entrada D (pin 2), y la señal CLK debe ser conectada a la entrada CLK (pin 3).
  * Esquemático: la entrada + (pin 3) de un op amp de filtro paso bajo para audio se debe conectar a VCC/2.
  * Esquemático: /VDP_WAIT tiene dos conexiones pull-up en RR2 y en RR5. Sólo debería estar conectado a RR2.
  * Esquemático: El SW1 deberia estar conectado a GND, El SW2 debería dejar no conectado.
  * Esquemático: "Izquierda" y "derecha" en los Joystick están invertidas.
  * Esquemático: El V9938 requiere una tolerancia en su alimentación del 5%. Reemplazar ADM693 por ADM691

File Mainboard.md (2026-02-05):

# Omega Main Board
Main Board for Omega Home Computer

[Lea este documento en español](Mainboard_es.md)

## Table of Content
* [Introduction](#introduction)
* [Specifications](#specifications)
* [Hardware Documentation](#hardware-documentation)
  * [Schematic and PCB Layout](#schematic-and-pcb-layout)
  * [Connectors](#connectors)
  * [Jumpers](#jumpers)
  * [Bill of Materials](#bill-of-materials)
  * [Input / Output Ports](#input--output-ports)
  * [Slot Map](#slot-map)
* [Firmware Documentation](#firmware-documentation)
  * [BIOS](#bios)
  * [SPLD Fuse Maps](#spld-fuse-maps)
* [Release Notes](#release-notes)
  * [Changes](#changes)
  * [Known Issues](#known-issues)

## Introduction
The main board implements standard MSX2* functionality, as described in the [Specifications](#specifications) section below. The main board is designed to be stacked under the keyboard PCB, thus creating a "keyboard computer" form factor typical for 1980's home computers.
Omega Mainboard connected to Keyboard

## Specifications
* Processor: Zilog Z80 CPU (CMOS version - Z84C00) running at 3.58 MHz
* Memory:
  * RAM: 512 KiB SRAM, expandable to 4 MiB using an optional daugherboard. MSX* compatible memory pager. The RAM is mapped to slot 3-2
  * ROM: 256 KiB or 512 KiB Flash ROM. The ROM is mapped to the slot 0 and sub slots 3-0, 3-1, and 3-3
* Video: Yamaha V9958 or Yamaha V9938 VDP
  * 128 KiB Video RAM
  * Composite, S-Video, and RGB video outputs
* Audio: Yamaha YM2149 or General Instrument AY-3-8910 PSG
* Two MSX* compatible cartridge slots
* Keyboard, joysticks, printer and cassette recorder interfaces
* RTC: Ricoh RP5C01
* Microprocessor Supervisor:
  * Reset generation
  * RTC battery backup
* BIOS: [C-BIOS](http://cbios.sourceforge.net/). Compatible with BIOSes from the original MSX2* computers with a similar slot organization and hardware specifications, for example [Sanyo* PHC-23J](https://www.msx.org/wiki/Sanyo_PHC-23J)

## Hardware Documentation

### Schematic and PCB Layout

[Schematic - Version 1.5](Mainboard/KiCad/Omega-Mainboard-Schematic-1.5.pdf)

[PCB Layout - Version 1.5](Mainboard/KiCad/Omega-Mainboard-Board-1.5.pdf)

### Connectors

#### J1 - Power (5V)
Connect regulated +5V power supply to this connector.

Note: On-board components use only 5V supply voltage. Some cartridges might also need 12V/-12V supply voltage. J10 connector should be used in this case.

Pin | Description     
--- | ---------------
Tip (the inner contact) | Power: 5V (positive terminal)
Barrel / Sleeve         |	Power: GND (negative terminal)

#### J2 - Composite Video

Pin | Description     
--- | ---------------
Tip (the inner contact) | Output: Composite Video
Ring / Sleeve         |	Power: GND

#### J3 - Audio

Pin | Description     
--- | ---------------
Tip (the inner contact) | Output: Audio (line level)
Ring / Sleeve         |	Power: GND

#### J4 - S-Video

Pin | Description     
--- | ---------------
1, 2 | Power: GND
3    |	Output: Luminance (intensity)
4    | Output: Chrominance (color)

#### J5 - RGB Connector
Pin | Description     
--- | ---------------
1   | Power: GND
2   |	Output: Audio (line level)
3   |	Output: AV (4.55V)
4   |	Output: Composite Video
5   |	Output: YS (3 V)
6   |	Output: Red
7   | Output: Green
8   | Output: Blue

#### J6 - Cassette Connector
Pin | Description     
--- | ---------------
1, 2, 3, 8   | Power: GND
4   |	Output: Sound output to cassette recorder (microphone level)
5   |	Input: Sound input from cassette recorder (line level)
6   |	Output: Relay - Motor control
7   | Output: Relay - Motor control

#### J7, J8 - Joystick Connectors
Pin | Description     
--- | ---------------
1   | Input: Forward (north / up)
2   | Input: Backward (south / down)
3   | Input: Left (west)
4   | Input: Right (east)
5   | Power: 5V
6   | Input: Trigger 1
7   | Input: Trigger 2
8   | Output: Joystick select
9   | Power: GND

#### J9 - Printer Connector
Pin | Description     
--- | ---------------
1   | Output: /STROBE
2   | Output: D0
3   | Output: D1
4   | Output: D2
5   | Output: D3
6   | Output: D4
7   | Output: D5
8   | Output: D6
9   | Output: D7
10  | No connection
11  | Input: Busy
12  | No connection
13  | No connection
14  | Power: GND

#### J10 - Power (5V, 12V, -12V)
Connect regulated 5V/12V/-12V power supply to this connector.

Pin | Description     
--- | ---------------
1, 2, 3 | Power: GND
4, 5, 6 |	Power: 5V
7   |	Power: 12V
8   |	Power: -12V

#### J11 - Keyboard Interface
Pin | Description     | Pin | Description
--- | --------------- | --- | ----------------
1   | Input: Column 0 | 2   | Power: 5V
3   |	Input: Column 1 | 4   | Output: Row A
5   |	Input: Column 2 | 6   | Output: Row B
7   |	Input: Column 3 | 8   | Output: Row C
9   |	Input: Column 4 | 10  | Output: Row D
11  |	Input: Column 5 | 12  | Output: Caps Lock LED
13  | Input: Column 6 | 14  | Output: Kana LED
15  | Input: Column 7 | 16  | Power: GND

#### J12 - SRAM Extension
Pin | Description      | Pin | Description
--- | ---------------- | --- | ----------------
1   | Power: 5V        | 2   | Power: 5V
3   |	Output: /RAM2_CS | 4   | Output: /RAM1_CS
5   |	Output: /RAM4_CS | 6   | Output: /RAM3_CS
7   |	Output: /RAM6_CS | 8   | Output: /RAM5_CS
9   |	Output: RAM_A18  | 10  | Output: /RAM7_CS
11  |	Output: RAM_A16  | 12  | Output: RAM_A15 
13  | Output: RAM_A14  | 14  | Output: RAM_A17 
15  | Output: A12      | 16  | Output: /WR
17  | Output: A7       | 18  | Output: A13
19  | Output: A6       | 20  | Output: A8
21  | Output: A5       | 22  | Output: A9
23  | Output: A4       | 24  | Output: A11
25  | Output: A3       | 26  | Output: /RD
27  | Output: A2       | 28  | Output: A10
29  | Output: A1       | 30  | Bi-directional: MD7
31  | Output: A0       | 32  | Bi-directional: MD6
33  | Bi-directional: MD0 | 34  | Bi-directional: MD5
35  | Bi-directional: MD1 | 36  | Bi-directional: MD4
37  | Bi-directional: MD2 | 38  | Bi-directional: MD3
39  | Power: GND       | 40  | Power: GND

#### J13 - /RST and /NMI Header
Pin | Description    | Pin | Description
--- | -------------- | --- | -----------
1   | In/Out: /RESET | 2   | Power: GND
3   | Input: /NMI    | 4   | Power: GND

#### J14 - VDP Color Bus
Pin | Description
--- | -----------
1   | Power: 5V
2   | Output: /DHCLK
3   | Output: /DLCLK
4   | Output: CBDR
5   | In/Out: CB7
6   | In/Out: CB6
7   | In/Out: CB5
8   | In/Out: CB4
9   | In/Out: CB3
10  | In/Out: CB2
11  | In/Out: CB1
12  | In/Out: CB0
13  | Power: GND

### Jumpers

#### JP1 - ROM_A18
JP1 selects whether bottom 256 KiB or top 256 KiB of 512 KiB Flash ROM are mapped to the system memory / slots.

Jumper Position	| Description
--------------- | -----------
Open*           | Use Flash ROM addresses 0x00000 - 0x3FFFF
Closed          | Use Flash ROM addresses 0x40000 - 0x7FFFF

#### JP2 - KBD_TYPE
JP2 selects the layout for Japanese keyboards

Jumper Position | Description
--------------- | -----------
Open*           | JIS layout
Closed          | ANSI/AIUEO/50on layout

#### JP3, JP4 - V9938/V9958
JP3 and JP4 select VDP type used. JP3 connects VDP pin 21 either to 470 ohm pull-up (V9938, unused composite video output), or to 5V power supply (V9958, DAC power supply). JP4 selects whether VDP CSYNC output goes directly to RGB encoder (V9958) or to a level shifer circuit (V9938).

*Warning: Incorrect setting of JP3 will damage VDP*

Jumper Position | Description
--------------- | -----------
1-2             | V9938 VDP
2-3             | V9958 VDP

#### JP5, JP6 - NTSC/PAL
JP5 and JP6 selects the color encoding system for the video output. More specifically, JP5 configures the RGB encoder and JP6 selects the color subcarrier frequency.

*Note: Some components used only for PAL color subcarrier frequency generation, and can be omitted if NTSC color encoding is used. Refer to Bill of Materials section for more information*

Jumper Position | Description
--------------- | -----------
1-2             | NTSC
2-3             | PAL

### Bill of Materials

[Omega Mainboard project on Mouser.com](https://www.mouser.com/ProjectManager/ProjectDetail.aspx?AccessID=11fd34d22c) - View and order all components except of the PCB, Yamaha V9958 VDP, Yamaha YM2149 PSG, Ricoh RP5C01 RTC, NEC D41464 DRAM, Sony CXA1645P RGB Encoder, and CR2032 battery.

Component type     | Reference | Description                                 | Quantity | Possible sources and notes
------------------ | --------- | ------------------------------------------- | -------- | --------------------------
PCB                |           | Omega Mainboard PCB - Version 1.1           | 1        | Refer to the [RetroBrew Computers Board Inventory](https://retrobrewcomputers.org/doku.php?id=boardinventory) page for ordering information, or order from a PCB manufacturer of your choice using provided Gerber or KiCad files
Integrated Circuit | U1        | Z80 CPU, CMOS, 40 pin DIP - Z84C00xxPEG     | 1        | Mouser [692-Z84C0010PEG](https://www.mouser.com/ProductDetail/692-Z84C0010PEG)
Integrated Circuit | U2        | 82C55 PPI, CMOS, 40 pin DIP - CP82C55AZ     | 1        | Mouser [968-CP82C55A-5Z](https://www.mouser.com/ProductDetail/968-CP82C55A-5Z)
Integrated Circuit | U3        | V9958 VDP, 64 pin DIP                       | 1        | eBay. Note: V9938 VDP can be used instead
Integrated Circuit | U4        | YM2149 PSG, 40 pin DIP or AY-3-8910         | 1        | eBay
Integrated Circuit | U5        | RP5C01 RTC, 18 pin DIP                      | 1        | eBay
Integrated Circuit | U6        | 512 KiB Flash ROM, 32 pin DIP - SST39SF040  | 1        | Mouser [804-39SF0407CPHE](https://www.mouser.com/ProductDetail/804-39SF0407CPHE)
Integrated Circuit | U7        | 512 KiB SRAM, 32 pin DIP - AS6C4008         | 1        | Mouser [913-AS6C4008-55PCN](https://www.mouser.com/ProductDetail/913-AS6C4008-55PCN)
Integrated Circuit | U8 - U11  | D41464, 64K x 4 DRAM, 18 pin DIP            | 4        | eBay
Integrated Circuit | U12 - U14 | Simple Programmable Logic Device - ATF16V8B | 3        | Mouser [556-AF16V8B15PU](https://www.mouser.com/ProductDetail/556-AF16V8B15PU)
Integrated Circuit | U15 - U18 | 4-by-4 Register File - 74HC670, 16 pin DIP  | 4        | Mouser [595-CD74HC670E](https://www.mouser.com/ProductDetail/595-CD74HC670E)
Integrated Circuit | U19 - U21 | 74F541, 20 pin DIP                          | 3        | Mouser [595-SN74F541N](https://www.mouser.com/ProductDetail/595-SN74F541N)
Integrated Circuit | U22       | 74HCT540, 20 pin DIP                        | 1        | Mouser [595-SN74HCT540N](https://www.mouser.com/ProductDetail/595-SN74HCT540N)
Integrated Circuit | U23, U24  | 74HCT273, 20 pin DIP                        | 2        | Mouser [595-SN74HCT273N](https://www.mouser.com/ProductDetail/595-SN74HCT273N). Note U24 is optional - printer port support.
Integrated Circuit | U25, U26  | 74F245, 20 pin DIP                          | 2        | Mouser [595-SN74F245N](https://www.mouser.com/ProductDetail/595-SN74F245N)
Integrated Circuit | U27       | 74HCT175, 16 pin DIP                        | 1        | Mouser [595-CD74HCT175E](https://www.mouser.com/ProductDetail/595-CD74HCT175E)
Integrated Circuit | U28, U29  | 74HCT157, 16 pin DIP                        | 2        | Mouser [595-SN74HCT157N](https://www.mouser.com/ProductDetail/595-SN74HCT157N)
Integrated Circuit | U30, U31  | 74HCT153, 16 pin DIP                        | 2        | Mouser [595-CD74HCT153E](https://www.mouser.com/ProductDetail/595-CD74HCT153E)
Integrated Circuit | U32       | 74AHCT138, 16 pin DIP                       | 1        | Mouser [595-SN74AHCT138N](https://www.mouser.com/ProductDetail/595-SN74AHCT138N)
Integrated Circuit | U33       | 74AHCT125, 14 pin DIP                       | 1        | Mouser [595-SN74AHCT125N](https://www.mouser.com/ProductDetail/595-SN74AHCT125N). Note U33 is optional - printer port support.
Integrated Circuit | U34 - U36 | Dual Flip Flop - 74HCT74, 14 pin DIP        | 3        | Mouser [595-SN74HCT74N](https://www.mouser.com/ProductDetail/595-SN74HCT74N)
Integrated Circuit | U37 - U39 | 74AHCT32, 14 pin DIP                        | 3        | Mouser [595-SN74AHCT32N](https://www.mouser.com/ProductDetail/595-SN74AHCT32N)
Integrated Circuit | U40, U41  | 74HCT30, 14 pin DIP                         | 2        | Mouser [595-CD74HCT30E](https://www.mouser.com/ProductDetail/595-CD74HCT30E)
Integrated Circuit | U42       | 74LS07, 14 pin DIP                          | 1        | Mouser [595-SN74LS07N](https://www.mouser.com/ProductDetail/595-SN74LS07N)
Integrated Circuit | U43       | 74HCT04, 14 pin DIP                         | 1        | Mouser [595-SN74HCT04N](https://www.mouser.com/ProductDetail/595-SN74HCT04N)
Integrated Circuit | U44       | 74AHCT02, 14 pin DIP                        | 1        | Mouser [595-SN74AHCT02N](https://www.mouser.com/ProductDetail/595-SN74AHCT02N)
Integrated Circuit | U45       | 74HCT00, 14 pin DIP                         | 1        | Mouser [595-SN74HCT00N](https://www.mouser.com/ProductDetail/595-SN74HCT00N)
Integrated Circuit | U46       | Microprocessor Supervisory Circuit - ADM691A | 1        | Mouser [584-ADM691AANZ](https://www.mouser.com/ProductDetail/584-ADM691AANZ); Possible alternatives: MAX691, LTC691, ADM691
Integrated Circuit | U47       | Sony CXA1645P RGB Encoder, 24 pin DIP-400   | 1        | eBay
Integrated Circuit | U48       | MCP6281-E/P Operational Amplifier, 8 pin DIP | 1       | Mouser [579-MCP6281-E-P](https://www.mouser.com/ProductDetail/579-MCP6281-E-P)
Integrated Circuit | U49       | LM311N, Voltage Comparator, 8 pin DIP       | 1        | Mouser [926-LM311N-NOPB](https://www.mouser.com/ProductDetail/926-LM311N-NOPB). Note U49 is optional - cassette recorder support.
Capacitor          | C1 - C58  | 0.1 uF, MLCC, 5 mm Pitch                    | 58       | Mouser [594-K104K15X7RF53H5](https://www.mouser.com/ProductDetail/594-K104K15X7RF53H5)
Capacitor          | C59 - C64 | 220 uF, Electrolytic                        | 6        | Mouser [647-UBW1E221MPD](https://www.mouser.com/ProductDetail/647-UBW1E221MPD). Note C62 - C64 optional - RGB output support
Capacitor          | C65 - C67 | 100 uF, 16V, Aluminum Organic Polymer       | 3        | Mouser [80-A750EK107M1CAAE18](https://www.mouser.com/ProductDetail/80-A750EK107M1CAAE18)
Capacitor          | C68 - C70 | 10 uF, MLCC, 5 mm Pitch                     | 3        | Mouser [810-FG28X5R1E106MR00](https://www.mouser.com/ProductDetail/810-FG28X5R1E106MR00). Note C71 optional - cassette recorder support.
Capacitor          | C71 - C77 | 10 uF, Electrolytic                         | 7        | Mouser [667-EEU-FR1H100](https://www.mouser.com/ProductDetail/667-EEU-FR1H100). Note C71 optional - cassette recorder support.
Capacitor          | C78       | 1 uF, Electrolytic                          | 1        | Mouser [710-860020672005](https://www.mouser.com/ProductDetail/710-860020672005). Note C78 optional - cassette recorder support.
Capacitor          | C79, C80  | 22 nF, MLCC, 5 mm Pitch                     | 2        | Mouser [810-FG28X7R1H223KNT0](https://www.mouser.com/ProductDetail/810-FG28X7R1H223KNT0). Note C79, C80 optional - cassette recorder support.
Capacitor          | C81       | 1.5 nF, MLCC, 5 mm Pitch                    | 1        | Mouser [810-FG28C0G1H152JNT0](https://www.mouser.com/ProductDetail/810-FG28C0G1H152JNT0)
Capacitor          | C82 - C84 | 330 pF, MLCC, 5 mm Pitch                    | 3        | Mouser [810-FG28C0G1H331JNT0](https://www.mouser.com/ProductDetail/810-FG28C0G1H331JNT0)
Capacitor          | C85       | 47 pF, MLCC, 5 mm Pitch                     | 1        | Mouser [810-FG28C0G1H470JNT0](https://www.mouser.com/ProductDetail/810-FG28C0G1H470JNT0)
Capacitor          | C86, C87  | 33 pF, MLCC, 5 mm Pitch                     | 2        | Mouser [810-FG28C0G1H330JNT0](https://www.mouser.com/ProductDetail/810-FG28C0G1H330JNT0)
Capacitor          | C88 - C90 | 30 pF, Trim Capactiors, 5 mm Pitch          | 3        | DigiKey [2447-GKG30015-ND](https://www.digikey.com/en/products/detail/ew-electronics/GKG30015/11689271). Note: Can be replaced with Mouser [810-FG28C0G2A270JNT0](https://www.mouser.com/ProductDetail/810-FG28C0G2A270JNT0) if color subcarrier frequency tunning is not required. 
Capacitor          | C91       | 27 pF, MLCC, 5 mm Pitch                     | 1        | Mouser [810-FG28C0G2A270JNT0](https://www.mouser.com/ProductDetail/810-FG28C0G2A270JNT0). Note C91 should be 18 pF for PAL support.
Capacitor          | C92, C93  | 22 pF, MLCC, 5 mm Pitch                     | 2        | Mouser [810-FG28C0G1H220JNT0](https://www.mouser.com/ProductDetail/810-FG28C0G1H220JNT0)
Capacitor          | C94       | 4.7 pF, MLCC, 5 mm Pitch                    | 1        | Mouser [810-FG28C0G1H4R7CNT0](https://www.mouser.com/ProductDetail/810-FG28C0G1H4R7CNT0)
Resistor Array     | RR1 - RR4 | 10 kohm, bussed, 10 pin SIP                 | 4        | Mouser [652-4610X-1LF-10K](https://www.mouser.com/ProductDetail/652-4610X-1LF-10K) or Mouser [652-4610X-AP1-103LF](https://www.mouser.com/ProductDetail/652-4610X-AP1-103LF)
Resistor Array     | RR5 - RR7 | 4.7 kohm, bussed, 10 pin SIP                | 3        | Mouser [652-4610X-1LF-4.7K](https://www.mouser.com/ProductDetail/652-4610X-1LF-4.7K) or Mouser [652-4610X-AP1-472LF](https://www.mouser.com/ProductDetail/652-4610X-AP1-472LF)
Resistor Array     | RR8, RR10 | 4.7 kohm, bussed, 6 pin SIP                 | 1 (2)    | Mouser [652-4606X-1LF-4.7K](https://www.mouser.com/ProductDetail/652-4606X-1LF-4.7K) or Mouser [652-4606X-AP1-472LF](https://www.mouser.com/ProductDetail/652-4606X-AP1-472LF). Note RR10 is optional - Memory pager size workaround.
Resistor Array     | RR9       | 470 ohm, bussed, 6 pin SIP                  | 1        | Mouser [652-4606X-1LF-470](https://www.mouser.com/ProductDetail/652-4606X-1LF-470) or Mouser [652-4606X-AP1-471LF](https://www.mouser.com/ProductDetail/652-4606X-AP1-471LF)
Resistor           | R1        | 1 Mohm, axial                               | 1        | Mouser [603-MFR-25FBF52-1M](https://www.mouser.com/ProductDetail/603-MFR-25FBF52-1M). Note R1 is optional - PAL support.
Resistor           | R2, R3    | 470 kohm, axial                             | 2        | Mouser [603-MFR-25FBF52-470K](https://www.mouser.com/ProductDetail/603-MFR-25FBF52-470K)
Resistor           | R4        | 220 kohm, axial                             | 1        | Mouser [603-MFR-25FBF52-220K](https://www.mouser.com/ProductDetail/603-MFR-25FBF52-220K)
Resistor           | R5, R6    | 100 kohm, axial                             | 2        | Mouser [603-MFR-25FBF52-100K](https://www.mouser.com/ProductDetail/603-MFR-25FBF52-100K)
Resistor           | R7, R8    | 47 kohm, axial                              | 2        | Mouser [603-MFR-25FBF52-47K](https://www.mouser.com/ProductDetail/603-MFR-25FBF52-47K)
Resistor           | R9, R10   | 20 kohm, 1% tolerance, axial                | 2        | Mouser [603-MFR-25FBF52-20K](https://www.mouser.com/ProductDetail/603-MFR-25FBF52-20K). Note R9 should be 16 kohm, 1% for PAL support.
Resistor           | R11 - R14 | 10 kohm, axial                              | 4        | Mouser [603-MFR-25FBF52-10K](https://www.mouser.com/ProductDetail/603-MFR-25FBF52-10K). Note R11, R12 are optional - cassette recorder support.  Note R14 is optional - RGB output support.
Resistor           | R15       | 5.6 kohm, axial                             | 1        | Mouser [603-MFR-25FBF52-5K6](https://www.mouser.com/ProductDetail/603-MFR-25FBF52-5K6)
Resistor           | R16 - R22 | 4.7 kohm, axial                             | 7        | Mouser [603-MFR-25FBF52-4K7](https://www.mouser.com/ProductDetail/603-MFR-25FBF52-4K7). Note R18 - R20 are optional - cassette recorder support.
Resistor           | R23, R24  | 2.7 kohm, axial                             | 2        | Mouser [603-MFR-25FBF52-2K7](https://www.mouser.com/ProductDetail/603-MFR-25FBF52-2K7). Note R23, R24 are optional - cassette recorder support.
Resistor           | R25, R26  | 2.2 kohm, axial                             | 2        | Mouser [603-MFR-25FBF52-2K2](https://www.mouser.com/ProductDetail/603-MFR-25FBF52-2K2)
Resistor           | R27 - R33 | 1 kohm, axial                               | 7        | Mouser [603-MFR-25FBF52-1K](https://www.mouser.com/ProductDetail/603-MFR-25FBF52-1K). Note R31, R32 are optional - cassette recorder support. Note R33 is optional - RGB output support.
Resistor           | R34       | 470 ohm, axial                              | 1        | Mouser [603-MFR-25FBF52-470R](https://www.mouser.com/ProductDetail/603-MFR-25FBF52-470R) 
Resistor           | R35       | 180 ohm, axial                              | 1        | Mouser [603-MFR-25FBF52-180R](https://www.mouser.com/ProductDetail/603-MFR-25FBF52-180R). Note R35 is optional - RGB output support.
Resistor           | R36       | 120 ohm, axial                              | 1        | Mouser [603-MFR-25FBF52-120R](https://www.mouser.com/ProductDetail/603-MFR-25FBF52-120R). Note R36 is optional - RGB output support.
Resistor           | R37 - R42 | 100 ohm, axial                              | 6        | Mouser [603-MFR-25FBF52-100R](https://www.mouser.com/ProductDetail/603-MFR-25FBF52-100R). Note R42 is optional - cassette recorder support.
Resistor           | R43 - R48 | 75 ohm, axial                               | 6        | Mouser [603-MFR-25FBF52-75R](https://www.mouser.com/ProductDetail/603-MFR-25FBF52-75R). Note R46 - R48 are optional - RGB output support.
Relay              | RY1       | 5V SPDT relay                               | 1        | Mouser [653-G5V-1-DC5](https://www.mouser.com/ProductDetail/653-G5V-1-DC5) or Mouser [653-G5V-1-T90-DC5](https://www.mouser.com/ProductDetail/653-G5V-1-T90-DC5)
Inductor           | L1        | 68 uH, axial                                | 1        | Mouser [542-78F680-RC](https://www.mouser.com/ProductDetail/542-78F680-RC)
Inductor           | L2, L3    | 5.6 uH, axial                               | 2        | Mouser [542-78F5R6J-RC](https://www.mouser.com/ProductDetail/542-78F5R6J-RC)
Diode              | D1        | 1N4148                                      | 1        | Mouser [512-1N4148TR](https://www.mouser.com/ProductDetail/512-1N4148TR). Note D1 is optional - cassette recorder support.
Transistor         | Q1, Q2    | PN2907A                                     | 2        | Mouser [512-PN2907ATF](https://www.mouser.com/ProductDetail/512-PN2907ATF). Note Q1 is optional - cassette recorder support; Q2 is required for V9938 VDP only
Crystal            | Y1        | 21.477270 MHz                               | 1        | Mouser [695-HC49US-214-U](https://www.mouser.com/ProductDetail/695-HC49US-214-U)
Crystal            | Y2        | 32768 Hz                                    | 1        | Mouser [815-AB38T-32.768KHZ](https://www.mouser.com/ProductDetail/815-AB38T-32.768KHZ)
Crystal            | Y3        | 4.433618 MHz                                | 1        | Mouser [520-HCU443-20X](https://www.mouser.com/ProductDetail/520-HCU443-20X). Note Y3 is optional - PAL support.
Polyfuse           | F1        | 750 mA, radial, 5 mm pitch                  | 1        | Mouser [650-RUSBF075-2](https://www.mouser.com/ProductDetail/650-RUSBF075-2)
Connector          | J1        | DC Power Jack, 2mm                          | 1        | Mouser [806-KLDX-0202-A](https://www.mouser.com/ProductDetail/806-KLDX-0202-A)
Connector          | J2        | RCA Phono connector, Yellow                 | 1        | Mouser [490-RCJ-014](https://www.mouser.com/ProductDetail/490-RCJ-014)
Connector          | J2        | RCA Phono connector, White                  | 1        | Mouser [490-RCJ-013](https://www.mouser.com/ProductDetail/490-RCJ-013)
Connector          | J4        | Mini DIN 4-pos, Right Angle, PCB mount      | 1        | Mouser [490-MD-40SM](https://www.mouser.com/ProductDetail/490-MD-40SM)
Connector          | J5, J6    | DIN 8-pos, Right Angle, PCB mount           | 2        | Mouser [490-SDF-80J](https://www.mouser.com/ProductDetail/490-SDF-80J). Note J5 is optional - RGB support; J6 is optional - cassette recorder support.
Connector          | J7, J8    | Sub-D DE9M, Right Angle, PCB mount          | 2        | Mouser [523-L717SDE09P1ACH3R](https://www.mouser.com/ProductDetail/523-L717SDE09P1ACH3R)
Connector          | J9        | Micro Ribbon 14-pos, Female, Right Angle, PCB mount | 1        | Mouser [636-112-014-213R001](https://www.mouser.com/ProductDetail/636-112-014-213R001). Note J9 is optional - printer port support.
Connector          | J10       | 8 pin friction lock connector               | 1        | Mouser [571-6404568](https://www.mouser.com/ProductDetail/571-6404568)
Connector          | J11       | 2x8 pin header, shrouded                    | 1        | Mouser [710-61201621621](https://www.mouser.com/ProductDetail/710-61201621621)
Connector          | J12       | 2x20 pin socket                             | 1        | Mouser [517-929852-01-20-RB](https://www.mouser.com/ProductDetail/517-929852-01-20-RB)
Connector          | J13       | 2x2 pin header                              | 1        | Note: Optional /RESET and /NMI header
Connector          | J14       | 1x13 pin header                             | 1        | Note: Optional Color Bus header
Connector          | SLOT1, SLOT2 | 50 pin card edge connector               | 2        | Mouser [571-5530843-5](https://www.mouser.com/ProductDetail/571-5530843-5)
Jumper             | JP1, JP2  | 2 pin header                                | 2        | Mouser [649-78229-102HLF](https://www.mouser.com/ProductDetail/649-78229-102HLF)
Jumper             | JP3 - JP6 | Wire link                                   | 4        | Wire link
Jumper             | JP7, JP8  | 2x3 pin header                              | 0 (2)    | Note JP7 and JP8 are optional - Memory pager size workaround.
Battery Holder     | BT1       | CR2032 Battery holder                       | 1        | Mouser [122-2420-GR](https://www.mouser.com/ProductDetail/122-2420-GR)
Battery            | BT1       | CR2032 Battery                              | 1        | Mouser [614-CR2032-200](https://www.mouser.com/ProductDetail/614-CR2032-200), [658-CR2032](https://www.mouser.com/ProductDetail/658-CR2032). Note: Not included in Mouser Project due to shipping restrictions.
IC Socket          | U1, U2, U4 | 40 pin DIP                                 | 3        | Mouser [517-4840-6000-CP](https://www.mouser.com/ProductDetail/517-4840-6000-CP)
IC Socket          | U3        | 64 pin DIP                                  | 1        | eBay
IC Socket          | U3        | 64 pin DIP (alternate)                      | 1        | DigiKey [117-87-764-41-005101](https://www.digikey.com/en/products/detail/preci-dip/117-87-764-41-005101/3757318)
IC Socket          | U3        | 64 pin DIP (pin strips, alternate)          | 4        | DigiKey [317-87-121-41-005101](https://www.digikey.com/en/products/detail/preci-dip/317-87-121-41-005101/3757383)
IC Socket          | U6, U7    | 32 pin DIP                                  | 2        | Mouser [517-4832-6000-CP](https://www.mouser.com/ProductDetail/517-4832-6000-CP)
IC Socket          | U47       | 24 pin DIP, 400 mil spacing                 | 1        | Mouser [517-4824-6000-CP](https://www.mouser.com/ProductDetail/517-4824-6000-CP) or [517-4824-3000-CP](https://www.mouser.com/ProductDetail/517-4824-3000-CP). Note: Cut the socket in the middle. If using a socket with 600 mil spacing, remove excess material. Alternatively, solder U47 (CXA1645P) without using a socket.
IC Socket          | U47       | 24 pin DIP, 400 mil spacing (alternate)     | 1        | DigiKey [110-93-424-41-001000](https://www.digikey.com/en/products/detail/mill-max-manufacturing-corp/110-93-424-41-001000/81797)
IC Socket          | U12 - U14, U19 - U26 | 20 pin DIP                       | 11       | Mouser [517-4820-3000-CP](https://www.mouser.com/ProductDetail/517-4820-3000-CP)
IC Socket          | U5, U8 - U11 | 18 pin DIP                               | 5        | Mouser [517-4818-3000-CP](https://www.mouser.com/ProductDetail/517-4818-3000-CP)
IC Socket          | U15 - U18, U27 - U32, U46 | 16 pin DIP                  | 11       | Mouser [517-4816-3000-CP](https://www.mouser.com/ProductDetail/517-4816-3000-CP)
IC Socket          | U33 - U45 | 14 pin DIP                                  | 13       | Mouser [517-4814-3000-CP](https://www.mouser.com/ProductDetail/517-4814-3000-CP)
IC Socket          | U48, U49  | 8 pin DIP                                   | 2        | Mouser [517-4808-3000-CP](https://www.mouser.com/ProductDetail/517-4808-3000-CP)

### Configuration Options and Component Replacement Notes

#### NTSC Video Standard Support
The Omega Main Board can be configured to support either NTSC (60 Hz) or PAL (50 Hz) video standard. To support NTSC standard the board should be configured as follows:
* Install a wire links JP5 and JP6 in 1-2 position for NTSC standard support
* **Do not install** the following components, they are required for PAL support only:
  * Crystal Oscillator: Y3
  * Capacitors: C90, C93
  * Resistors: R1, R30
* If using V9958 VDP also **do not install** the following components:
  * Capacitor: C43
  * Integrated Circuit: U43
* If using V9938 VDP **do install** the following components, they are used for V9938 VDP CSYNC level converter:
  * Capacitor: C43
  * Integrated Circuit: U43
  * Install a wire link instead of C93 to avoid floating inputs on U43

#### PAL Video Standard Support
To support PAL standard the board should be configured as follows:
* Install a wire links JP5 and JP6 in 2-3 position for PAL standard support
* Install the following components:
  * Crystal Oscillator: Y3
  * Capacitors: C43, C90, C93
  * Resistors: R1, R30
  * Integrated Circuits: U43
* Replace the following components:
  * R9 use 16 kohm resistor (instead of 20 kohm)
  * C91 use 18 pF capacitor (instead of 27 pF)

#### V9958 VDP Support
The Omega Main Board can be configured to support either V9958 VDP (recommended) or V9938 VDP. To support V9958 VDP the board should be configured as follows:
* Do not install the following components:
  * Transistor: Q2
  * Capacitor: C43
  * Integrated Circuit: U43
  * Note: C43 and U43 also used for PAL clock generation. They must be installed if PAL video standard support is desired
* Install a wire links JP3 and JP4 in 2-3 position for V9958 VDP

#### V9938 VDP Support
To support V9938 VDP the board should be configured as follows:
* Install the following components:
  * Transistor: Q2
  * Capacitor: C43
  * Integrated Circuit: U43
* Install a wire links JP3 and JP4 in 1-2 position for V9938 VDP.
* If using NTSC video standard install a wire link instead of C93 to avoid floating inputs on U43
* **Warning: Incorrect setting of JP3 will damage VDP**
  
### Input / Output Ports

* 0x90 - 0x91 (aliases 0x92 - 0x93) - Printer Port
  * 0x90: Write: Strobe (Bit 0)
  * 0x90: Read: Busy (Bit 1)
  * 0x91: Write: Data
* 0x98 - 0x9B - V9938 Video Display Processor (VDP)
  * 0x98: Read/Write: VRAM Data
  * 0x99: Write: Register Select / VRAM Address
  * 0x99: Read: Status Register
  * 0x9A: Palette access
  * 0x9B: Indirect register access
* 0xA0 - 0xA2 - YM2149 Programmable Sound Generator (PSG)
  * 0xA0: Write: Register Select
  * 0xA1: Write: Register Value
  * 0xA2: Read: Register Value
* 0xA8 - 0xAB - 8255 Programmable Parallel Interface (PPI)
  * 0xA8: i8255: Port A - Primary slot select register
  * 0xA9: i8255: Port B - Keyboard matrix row input register
  * 0xAA: i8255: Port C - Keyboard matrix column output and cassette interface output register
  * 0xAB: i8255: Command Register
* 0xB4 - 0xB5 (aliases 0xB6 - 0xB7) - RP5C01 Real Time Clock (RTC)
  * 0xB4: RTC: Write: Register select
  * 0xB5: RTC: Read/Write: RTC data
* 0xFC - 0xFF - Memory Page Select
  * 0xFC: Read/Write: Page 0
  * 0xFD: Read/Write: Page 1
  * 0xFE: Read/Write: Page 2
  * 0xFF: Read/Write: Page 3
* 0xFFFF (Memory I/O, slot 3) - Sub slot select register

### Slot Map
* Slot 0
  * 0x0000 - 0x7FFF (32 KiB): Main ROM, mapped to Flash ROM 0x00000 - 0x07FFF
  * 0x8000 - 0xBFFF (16 KiB): Logo ROM, mapped to Flash ROM 0x08000 - 0x0BFFF
  * 0xC000 - 0xFFFF (16 KiB): Unused
* Slot 1: Cartridge Slot 1
* Slot 2: Cartridge Slot 2
* Slot 3: Expanded slot
* Slot 3, Sub slot 0
  * 0x0000 - 0x3FFF (16 KiB): Sub ROM, mapped to Flash ROM 0x10000 - 0x13FFF
* Slot 3, Sub slot 1
  * 0x0000 - 0xFFFF (64 KiB): User ROM #1, mapped to Flash ROM 0x20000 - 0x2FFFF
* Slot 3, Sub slot 2
  * 0x0000 - 0xFFFF (64 KiB): Main RAM (memory mapper)
* Slot 3, Sub slot 3
  * 0x0000 - 0xFFFF (64 KiB): User ROM #2, mapped to Flash ROM 0x30000 - 0x3FFFF

## Firmware Documentation

### BIOS

Omega runs [C-BIOS](https://sourceforge.net/projects/cbios/) - an open source BIOS for MSX computers.
It can also run the original MSX2* BIOS from computers with a similar slot organization and hardware specifications, for example [Sanyo* PHC-23J](https://www.msx.org/wiki/Sanyo_PHC-23J) and [Philips* NMS 8250](https://www.msx.org/wiki/Philips_NMS_8250).

### SPLD Fuse Maps

Omega uses three ATF16V8/GAL16V8 SPLDs (U12 - U14) for address decode and various other logic. The SPLD fuse maps (JED files) are provided in [Mainboard/SPLD](Mainboard/SPLD) directory of this repository. The SPLDs are implemented using Flash/EEPROM technology and can be programmed by commonly available EPROM programmers, such as MiniPro TL866.
The source code (PLD) files are also provided in the directory mentioned above. If needed, they can be modified, for example to change the slot mapping. Use [GALasm](https://github.com/daveho/GALasm) to compile PLD files to JED fuse maps.

## Changes
* Version 1.5
  * Fix [issue #54](https://github.com/skiselev/omega/issues/56) where Joystick A Trigger 2 was swapped with Joystick B Trigger 1
* Version 1.4
  * Updates for a memory pager workaround:
    * Use 2-pin jumpers instead of 3-pin
    * Jumpers are connected by traces on the back side. To implement the workaround - cut the traces and install jumpers as needed
  * Note: This version uses the original CUI/TE DIN 8 connector footprint
* Version 1.3eu
  * Modifications implemented by Jordi Solis:
    * Workaround for memory pager issues - limit number of bits used by memory pager
    * Cutout on the back of the board to allow using right angle slot connectors
    * Use more common in the EU DIN 8 connector footprint
* Version 1.2
  * Fix the known issues of version 1.1
* Version 1.1
  * Fix the known issues of version 1.0
  * Use DIN-8 connectors with standard MSX/MSX2 pinout for RGB and Cassette interfaces
  * Move keyboard pull-ups to the motherboard
  * Add LC filters for VDP and RGB encoder
  * Add RESET / NMI header
  * Connect slots pins 44 and 46 to GND
  * Add polyfuse for joystick ports
  * V9938/V9958 support: Add a switch (JP4) to select between CSYNC to TTL level shifter for V9938 or connect CSYNC directly for V9958
  * Add Color Bus header
  * Use ADM691A mircoprocessor supervisor

* Version 1.0
  * Initial version

## Known Issues
* Version 1.4
  * Joystick A Trigger 2 is swapped with Joystick B Trigger 1. Workaround:
    * Disconnect (e.g., cut the traces) U4 pin 12 and U42 pin 13, and U4 pin 11 and U42 pin 11
    * Connect (e.g., solder wires) U4 pin 12 and U42 pin 11, and U4 pin 11 and U42 pin 13
* Version 1.2
  * Memory pager issues:
    * Some software that writes and reads back memory pager to determine the installed memory size does not work correctly. This is because Omega memory pager implements all 8 bits regardless of the installed memory size, so all 8 bit are read back.
    * Some software intentionally writes page numbers bigger than number of memory pages present in the system and expects the page number to "roll over". This doesn't happen on Omega becase it completely decodes all 8 bit of the page number
  * When using right angle slot connector, cartridge interferes with the back side of the board
* Version 1.1
  * Top silkscreen: R30 should be 1k (lower case 'k')
  * Top silkscreen: L2 and L3 should be 5.6uH

* Version 1.0
  * Top silkscreen: References R8 and R36 are swapped. The values are indicated correctly on the silkscreen.
  * Top silkscreen: The values of C48 and C82 are swapped. C48 should be 0.1 uF, and C82 should be 1.5nF.
  * Top silkscreen: Pal Clock Generator dotted line area should also include U43 and C43.
  * Top silkscreen: "M" logo and the project URL are missing.
  * Schematic: The pinout for 74AHCT32 IC (U37 - U39) is incorrect.
  * Schematic: The /RD and /WR signals in subslot register select (U38C, U32D) are swapped.
  * PCB: Keyboard connector (J11) interferes with printer port latch (U24). Use a straight pin header instead of a right angle one.
  * Schematic: A pull-up is needed on V9938 VDP /INT output (pin 25), as it is an open drain output.
  * PCB: MSX Cartrige Slots need to be rotated 180 degrees. Pin 1 of cartrige slot should be in top left position.
  * Schematic: CXA1645 needs TTL level SYNCIN, while V9938 provides 2.4 V - 4.8 V signal at CSYNC. A level shifter is needed.
  * Schematic: PSG clock divider 74HCT74 U35A /Q output (pin 6) should be connected to D input (pin 2), and CLK signal should be connected to CLK input (pin 3).
  * Schematic: Audio low pass filter op amp plus input (pin 3) should be connected to VCC/2.
  * Schematic: /VDP_WAIT has two pull-up connections to RR2 and to RR5. It should be connected only to RR2.
  * Schematic: SW1 should be connected to the ground, SW2 should be left not connected.
  * Schematic: Joystick "Left" and "Right" are reversed.
  * Schematic: V9939 requires 5% tolerance power supply. Replace ADM693 with ADM691

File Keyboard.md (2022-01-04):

# Omega Keyboard
Keyboard for the Omega Home Computer

[Lea este documento en español](Keyboard_es.md)

## Introduction
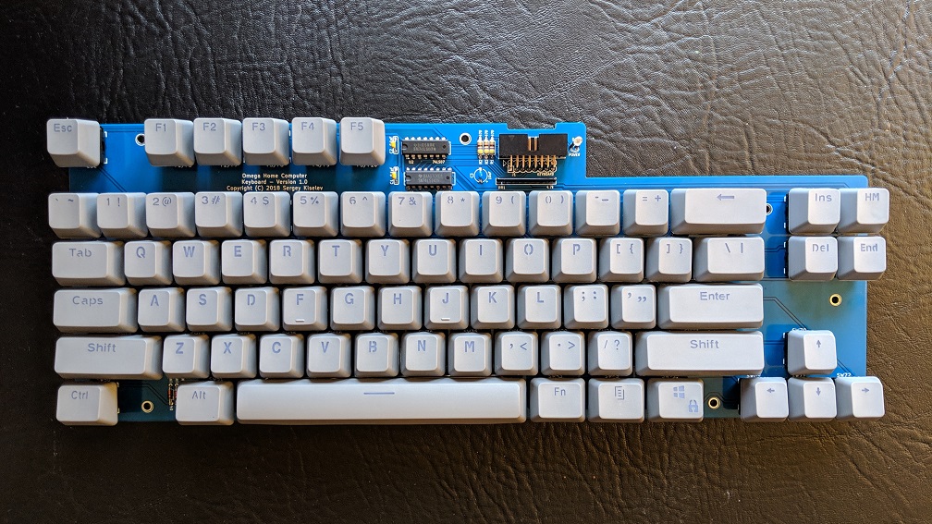
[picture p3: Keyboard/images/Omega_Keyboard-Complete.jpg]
Assembled Keyboard


## Hardware Documentation

### Schematic and PCB Layout

[Schematic - Version 1.1](Keyboard/KiCad/Omega-Keyboard-Schematic-1.1.pdf)

[PCB Layout - Version 1.1](Keyboard/KiCad/Omega-Keyboard-Board-1.1.pdf)

### Connectors

#### J1 - Keyboard Interface
Pin | Description      | Pin | Description
--- | ---------------- | --- | ----------------
1   | Output: Column 0 | 2   | Power: +5V
3   |	Output: Column 1 | 4   | Input: Row A
5   |	Output: Column 2 | 6   | Input: Row B
7   |	Output: Column 3 | 8   | Input: Row C
9   |	Output: Column 4 | 10  | Input: Row D
11  |	Output: Column 5 | 12  | Input: Caps Lock LED
13  | Output: Column 6 | 14  | Input: Kana LED
15  | Output: Column 7 | 16  | Power: GND

### Bill of Materials - Version 1.0

[Omega Keyboard project on Mouser.com](https://www.mouser.com/ProjectManager/ProjectDetail.aspx?AccessID=716135aec2) - View and order all components except of the keycaps set, and the PCB.

Component type     | Reference | Description                       | Quantity | Possible sources and notes
------------------ | --------- | --------------------------------- | -------- | --------------------------
PCB                |           | Omega Keyboard PCB - Version 1.0  | 1        | Refer to the [RetroBrew Computers Board Inventory](https://retrobrewcomputers.org/doku.php?id=boardinventory) page for ordering information, or order from a PCB manufacturer of your choice using provided Gerber or KiCad files
Integrated Circuit | U1        | 74LS145 Octal D-Type Latch        | 1        | Mouser [595-SN74LS145N](https://www.mouser.com/ProductDetail/595-SN74LS145N)
Integrated Circuit | U2        | 74LS07 Octal Bus Transceiver      | 1        | Mouser [595-SN74LS07N](https://www.mouser.com/ProductDetail/595-SN74LS07N)
LED                | D1        | 3 mm, green LED indicator         | 1        | Mouser [593-VAOL-3HDE4](https://www.mouser.com/ProductDetail/593-VAOL-3HDE4)
LED                | D2        | 3 mm, yellow LED indicator        | 1        | Mouser [593-VAOL-3HCE4](https://www.mouser.com/ProductDetail/593-VAOL-3HCE4)
LED                | D3        | 3 mm, red LED indicator           | 1        | Mouser [593-VAOL-3HAE4](https://www.mouser.com/ProductDetail/593-VAOL-3HAE4)
Diode              | D4-6      | 1N4148                            | 3        | Mouser [512-1N4148TR](https://www.mouser.com/ProductDetail/512-1N4148TR)
Keyboard Switch    | SW1-SW64, SW66-SW73 |  MX Cherry - Linear     | 72       | Mouser [540-MX1A-11NW](https://www.mouser.com/ProductDetail/540-MX1A-11NW)
Keyboard Switch    | SW65      |  MX Cherry - High Force Linear    | 1        | Mouser [540-MX1A-21NW](https://www.mouser.com/ProductDetail/540-MX1A-21NW)
Switch Leveling Kit | SW13, SW49, SW64, SW65, SW73 | Leveling kit for MX 1x2, 1x2.25, 1x2.75 | 5 | Mouser [540-G99-0742](https://www.mouser.com/ProductDetail/540-G99-0742)
Switch Leveling Kit | SW64 | Leveling kit for MX 1x8               | 1        | Mouser [540-G99-0226](https://www.mouser.com/ProductDetail/540-G99-0226) Note: Use one of 540-G99-0742 to build a through hole leveling kit for the spacebar
Keycaps            | SW1-SW73  | 104 Keycaps kit for Cherry MX Keyboard | 1   | Amazon, for example [this one](https://www.amazon.com/Aland-Doubleshot-Spacebar-Mechanical-Keyboard/dp/B07JVL16TD)
Connector          | J1 | 2x8 pin header, right angle, shrouded, 2.54 mm pitch | 1 | Mouser [710-61201621721](https://www.mouser.com/ProductDetail/710-61201621721) or use 2x8 pin female header to plug the keyboard directly to the mainboard using 15 mm standoffs between them: Mouser [200-ESQ10812LD](https://www.mouser.com/ProductDetail/200-ESQ10812LD)
Capacitor          | C1, C2    | 0.1 uF, MLCC, 5 mm lead spacing   | 2       | Mouser [594-K104K15X7RF53H5](https://www.mouser.com/ProductDetail/594-K104K15X7RF53H5)
Capacitor          | C3        | 10 uF, MLCC, 5 mm lead spacing    | 1       | Mouser [810-FG28X5R1E106MR00](https://www.mouser.com/ProductDetail/810-FG28X5R1E106MR00)
Resistor Array     | RN1       | 4.7 kohm, bussed, 6 pin SIP       | 1        | Mouser [264-4.7K-RC](https://www.mouser.com/ProductDetail/264-4.7K-RC)
Resistor           | R1 - R3    | 470 ohm, through hole            | 3        | Mouser [291-470-RC](https://www.mouser.com/ProductDetail/291-470-RC)

## Changes
* Version 1.1
  * Rename RR1 to RN1
  * Keep pull-ups only for buffered COLUMN outputs. Replace RN1 with 6-pin SIP resistor array
  * Update schematic to use newer KiCad libraries
  * Add project URL and logos to the silk screen
* Version 1.0
  * Initial version

## Known Issues
* Version 1.0
  * Pull-up resistors are not needed on the keyboard COLUMN outputs. They should be placed on the mainboard instead

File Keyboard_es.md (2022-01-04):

# Teclado del Omega
Teclado para el Ordenador Personal Omega

[Read this document in English](Keyboard.md)

## Introduccion
Assembled Keyboard

## Documentación del Hardware 

### Esquemático y Diseño de la PCB

[Schematic - Version 1.1](Keyboard/KiCad/Omega-Keyboard-Schematic-1.1.pdf)

[PCB Layout - Version 1.1](Keyboard/KiCad/Omega-Keyboard-Board-1.1.pdf)

### Conectores

#### J1 - Keyboard Interface
Pin | Description         | Pin | Descripción
--- | ------------------- | --- | ----------------
1   | Salida: Columna 0   | 2   | Power: +5V
3   | Salida: Columna 1   | 4   | Entrada: Fila A
5   | Salida: Columna 2   | 6   | Entrada: Fila B
7   | Salida: Columna 3   | 8   | Entrada: Fila C
9   | Salida: Columna 4   | 10  | Entrada: Fila D
11  | Salida: Columna 5   | 12  | Entrada: Caps Lock LED
13  | Salida: Columna 6   | 14  | Entrada: Kana LED
15  | Salida: Columna 7   | 16  | Power: GND

### Lista de Materiales - Versión 1.0

[Omega Keyboard project on Mouser.com](https://www.mouser.com/ProjectManager/ProjectDetail.aspx?AccessID=716135aec2) - View and order all components except of the keycaps set, and the PCB.

Component type     | Reference | Description                       | Quantity | Possible sources and notes
------------------ | --------- | --------------------------------- | -------- | --------------------------
PCB                |           | Omega Keyboard PCB - Version 1.0  | 1        | Refer to the [RetroBrew Computers Board Inventory](https://retrobrewcomputers.org/doku.php?id=boardinventory) page for ordering information, or order from a PCB manufacturer of your choice using provided Gerber or KiCad files
Integrated Circuit | U1        | 74LS145 Octal D-Type Latch        | 1        | Mouser [595-SN74LS145N](https://www.mouser.com/ProductDetail/595-SN74LS145N)
Integrated Circuit | U2        | 74LS07 Octal Bus Transceiver      | 1        | Mouser [595-SN74LS07N](https://www.mouser.com/ProductDetail/595-SN74LS07N)
LED                | D1        | 3 mm, green LED indicator         | 1        | Mouser [593-VAOL-3HDE4](https://www.mouser.com/ProductDetail/593-VAOL-3HDE4)
LED                | D2        | 3 mm, yellow LED indicator        | 1        | Mouser [593-VAOL-3HCE4](https://www.mouser.com/ProductDetail/593-VAOL-3HCE4)
LED                | D3        | 3 mm, red LED indicator           | 1        | Mouser [593-VAOL-3HAE4](https://www.mouser.com/ProductDetail/593-VAOL-3HAE4)
Diode              | D4-6      | 1N4148                            | 3        | Mouser [512-1N4148TR](https://www.mouser.com/ProductDetail/512-1N4148TR)
Keyboard Switch    | SW1-SW64, SW66-SW73 |  MX Cherry - Linear     | 72       | Mouser [540-MX1A-11NW](https://www.mouser.com/ProductDetail/540-MX1A-11NW)
Keyboard Switch    | SW65      |  MX Cherry - High Force Linear    | 1        | Mouser [540-MX1A-21NW](https://www.mouser.com/ProductDetail/540-MX1A-21NW)
Switch Leveling Kit | SW13, SW49, SW64, SW65, SW73 | Leveling kit for MX 1x2, 1x2.25, 1x2.75 | 5 | Mouser [540-G99-0742](https://www.mouser.com/ProductDetail/540-G99-0742)
Switch Leveling Kit | SW64 | Leveling kit for MX 1x8               | 1        | Mouser [540-G99-0226](https://www.mouser.com/ProductDetail/540-G99-0226) Note: Use one of 540-G99-0742 to build a through hole leveling kit for the spacebar
Keycaps            | SW1-SW73  | 104 Keycaps kit for Cherry MX Keyboard | 1   | Amazon, for example [this one](https://www.amazon.com/Aland-Doubleshot-Spacebar-Mechanical-Keyboard/dp/B07JVL16TD)
Connector          | J1 | 2x8 pin header, right angle, shrouded, 2.54 mm pitch | 1 | Mouser [710-61201621721](https://www.mouser.com/ProductDetail/710-61201621721)
Capacitor          | C1, C2    | 0.1 uF, MLCC, 5 mm lead spacing   | 2       | Mouser [594-K104K15X7RF53H5](https://www.mouser.com/ProductDetail/594-K104K15X7RF53H5)
Capacitor          | C3        | 10 uF, MLCC, 5 mm lead spacing    | 1       | Mouser [810-FG28X5R1E106MR00](https://www.mouser.com/ProductDetail/810-FG28X5R1E106MR00)
Resistor Array     | RN1       | 4.7 kohm, bussed, 6 pin SIP       | 1        | Mouser [264-4.7K-RC](https://www.mouser.com/ProductDetail/264-4.7K-RC)
Resistor           | R1 - R3    | 470 ohm, through hole            | 3        | Mouser [291-470-RC](https://www.mouser.com/ProductDetail/291-470-RC)

## Cambios
* Versión 1.1
  * Renombrar RR1 por RN1
  * Mantener las resistencias pull-ups sólo para las salidas buffer de COLUMNAS. Sustituir RN1 por un array de resistencias SIP de 6-pin
  * Actualizar el esquemático para usar librerías de KiCad más recientes
  * Añadir la URL del proyecto y los logos a la serigrafía
* Version 1.0
  * Versión Inicial

## Problemas Conocidos
* Version 1.0
  * Las resistencias Pull-up no son necesarias en las salidas COLUMNAS del teclado. En su lugar, debería ir en la Placa Base.

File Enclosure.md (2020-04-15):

# Omega Enclosure
Acrylic Enclosure for the Omega Home Computer

[Lea este documento en español](Enclosure_es.md)

## Introduction
This is a laser cut acrylic enclosure for the Omega Home Computer.
The design assumes that it will be laser cut from a 3 mm acrylic (or similar plastic) sheet.
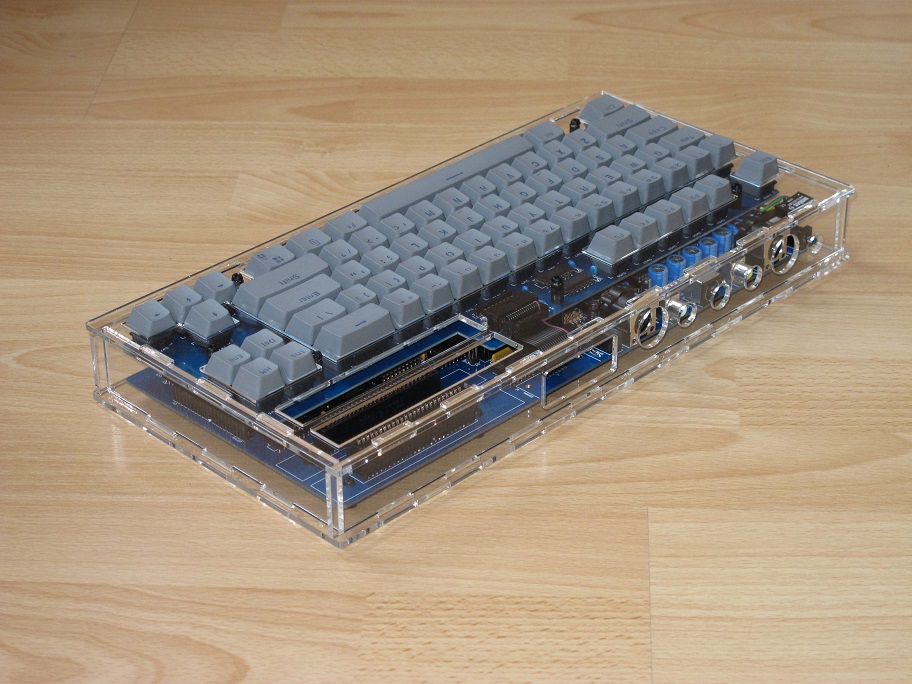
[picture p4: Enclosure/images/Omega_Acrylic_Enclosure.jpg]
Omega - Acrylic Enclosure


## Hardware Documentation

### Build Instructions

The enclosure is assembled in the following order:

1. Eleven M3 x 12 screws are placed through holes in the bottom panel
2. 3 mm washers are placed on these screws on the top side of the bottom panel
3. The main board PCB is placed on top of washers
4. Seven M3 x 15 mm standoffs are screwed on the top of the screws, excluding the holes next to the MSX cartridge slots
5. Four M3 hex nuts are used to secure the board next to the slots, optionally placing the slots guide 3D printed part
6. (Optional) Switch is connected to the header on the mainboard
7. The keyboard PCB is placed on top of standoffs. It is secured using one M3 hex nut under the space bar, and using six M3 x 10 mm standoffs elsewhere
8. Four side panels are placed through the cut outs in the bottom plate. (Optional) Switch is mounted on the back panel
9. The top panel is assembed on the standoffs using six M3 x 6 mm screws

### Bill of Materials - Version 1.0

Component type     | Reference | Description                       | Quantity | Possible sources and notes
------------------ | --------- | --------------------------------- | -------- | --------------------------
Standoff           |           | M3 x 10 mm, female, OD: 5 mm hex  | 6        | Mouser [534-24393](https://www.mouser.com/ProductDetail/534-24393)
Standoff           |           | M3 x 15 mm, male/female, OD: 5 mm hex  | 7   | Mouser [534-24315](https://www.mouser.com/ProductDetail/534-24315)
Screw              |           | M3 x 12 mm, Button Socket Cap     | 11       | Fastenal [MB2510012A20000](https://www.fastenal.com/products/details/MB2510012A20000)
Screw              |           | M3 x 6 mm, Button Socket Cap      | 6        | Fastenal [MB2510006A20000](https://www.fastenal.com/products/details/MB2510006A20000)
Nut                |           | M3 hex                            | 5        | Fastenal [MN2510000A20000](https://www.fastenal.com/products/details/MN2510000A20000)
Acrylic panel      |           | [Bottom plate](Enclosure/Omega-Eco1_User.dxf) | 1 | Laser cut from 3 mm acrylic
Acrylic panel      |           | [Top plate, side plates, washers](Enclosure/Omega-Eco2_User.dxf) | 1 | Laser cut from 3 mm acrylic
3D Printed Part    |           | [Slots guide](Enclosure/Omega-Slots_Guide.stl) | 1 | (Optional) 3D Print
Switch             |           | Toggle Switch                     | 1        | (Optional) Mouser [612-100-A1121](https://www.mouser.com/ProductDetail/612-100-A1121). This switch is mounted on the back panel, and it can be used to switch between two halves of the ROM, e.g. for switching between MSX2 BIOS and C-BIOS. Alternatively, a push button for a reset can be installed in that location.

## Release Notes

## Changes
* Version 1.0
  * Initial version

## Known Issues

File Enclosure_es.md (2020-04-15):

# Chasis del Omega
Caja de acrílico para el Omega Home Computer

[Read this document in English](Enclosure.md)

## Introducción
Esta es una caja de acrílico cortada con laser para el Omega Home Computer.
El diseño presupone que será cortado de una lámina de 3mm de acrílico (o plástico similar)
Omega - Acrylic Enclosure

## Documentación del Hardware

### Instrucciones de montaje

El chasis se ha de ensamblar en el siguiente orden:

1. Se insertan once tonrillos M3 x 12 en los agujeros del panel inferior (cara arriba)
2. Se colocan arandelas de 3 mm en dichos tornillos en la cara superior del panel inferior
3. Se inserta la placa base encima de las arandelas
4. Se enroscan siete separadores M3 x 15 mm por encima de esos tornillos, excluyendo los agujeros proximos a los slots de cartucho
5. Se usan cuatro tuercas M3 hexágonales para asegurar la placa en la zona de los slot, colocando opcionalmente las guias de slot impresas en 3D
6. (Opcional) Se conecta un interruptor al conector de pines en la placa base
7. Se coloca la placa del teclado encima de los separadores. Se asegura utilizando una tuerca M3 bajo la barra espaciadora, y seis separadores M3 x 10 mm en el resto
8. Se colocan cuatro paneles laterales a través de las ranuras en el panel inferior. (Opcional) Se monta el interruptor en el panel posterior
9. Se fija el panel superior sobre los separadores utilizando seis tornillos M3 x 6 mm

### Lista de componentes - Version 1.0

Tipo de componente | Referencia| Descripcion                       | Cantidad | Posible fuente y notas
------------------ | --------- | --------------------------------- | -------- | --------------------------
Separadores        |           | M3 x 10 mm, female, OD: 5 mm hex  | 6        | Mouser [534-24393](https://www.mouser.com/ProductDetail/534-24393)
Separadores        |           | M3 x 15 mm, male/female, OD: 5 mm hex  | 7   | Mouser [534-24315](https://www.mouser.com/ProductDetail/534-24315)
Tornillos          |           | M3 x 12 mm, Button Socket Cap     | 11       | Fastenal [MB2510012A20000](https://www.fastenal.com/products/details/MB2510012A20000)
Tornillos          |           | M3 x 6 mm, Button Socket Cap      | 6        | Fastenal [MB2510006A20000](https://www.fastenal.com/products/details/MB2510006A20000)
Tuercas            |           | M3 hex                            | 5        | Fastenal [MN2510000A20000](https://www.fastenal.com/products/details/MN2510000A20000)
Panel Acrílico     |           | [Panel inferior](Enclosure/Omega-Eco1_User.dxf) | 1 | corte laser de 3mm en acrilico
Panel Acrílico     |           | [Paneles superior, laterales, arandelas](Enclosure/Omega-Eco2_User.dxf) | 1 | corte laser de 3mm en acrilico
Pieza impresa 3D   |           | [Guia de slots](Enclosure/Omega-Slots_Guide.stl) | 1 | (Opcional) impreso en 3D
Interruptor        |           | Interruptor de palanca                | 1        | (Opcional) Mouser [612-100-A1121](https://www.mouser.com/ProductDetail/612-100-A1121). Se monta este interruptor en el panel posterior, que sirve para seleccionar la BIOS de entre los dos segmentos de la ROM, p.e. para cambiar entre BIOS MSX2 y C-BIOS. Opcionalmente, se puede montar un botón de reset en esa ubicación.

## Notas de la versión

### Cambios
* Version 1.0
  * Versión inicial

### Problemas conocidos

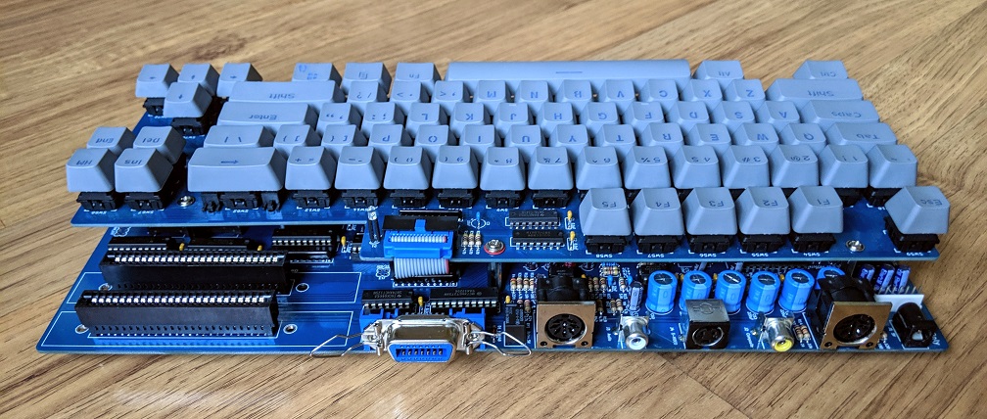
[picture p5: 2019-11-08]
Mainboard/images/Omega-Mainboard-1.1-Back.jpg

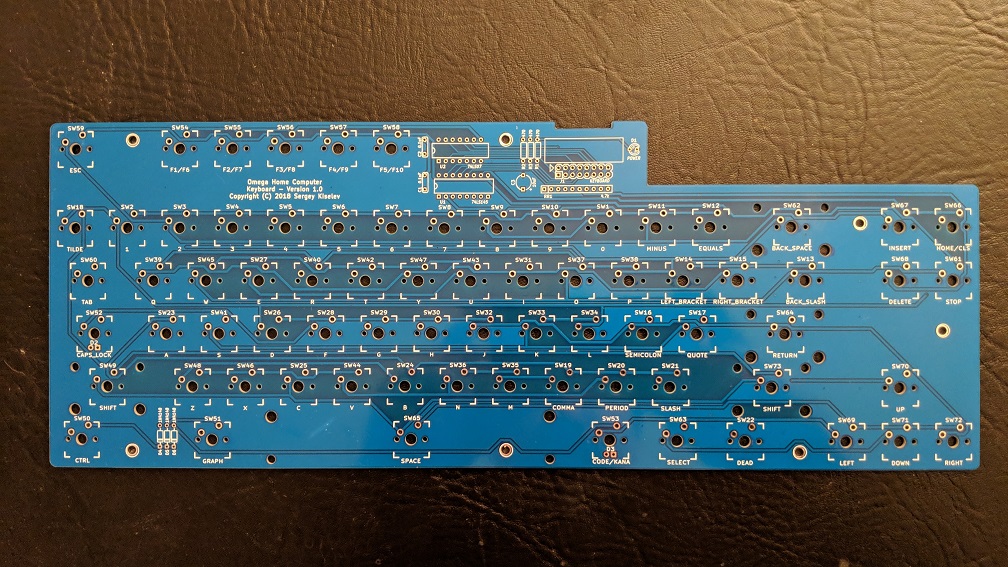
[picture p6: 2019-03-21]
Keyboard/images/Omega_Keyboard-PCB.jpg

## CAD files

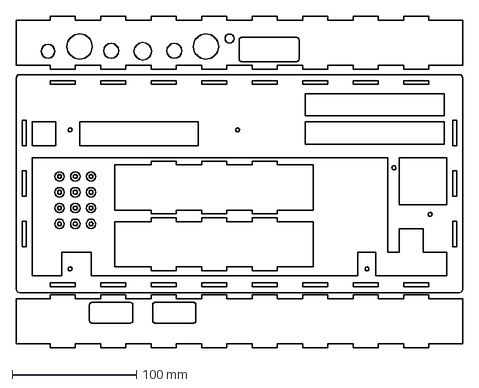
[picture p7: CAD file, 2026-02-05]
Enclosure/Omega-Eco2_User_5mm_Higher.dxf
358.8 x 266.8 mm

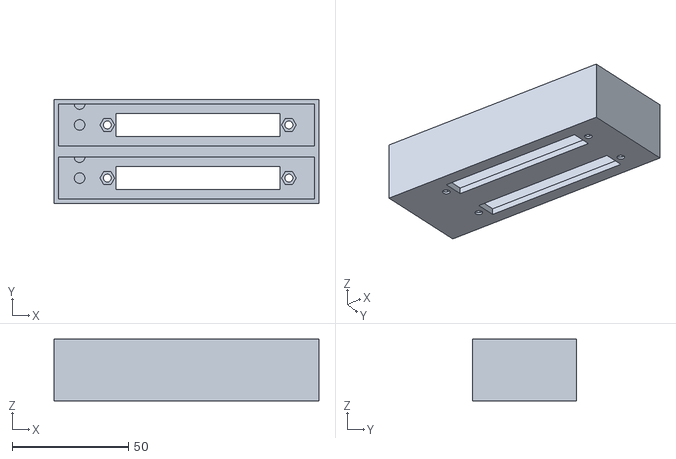
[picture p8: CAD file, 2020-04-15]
Enclosure/Omega-Slots_Guide.stl
114.0 x 44.9 x 26.6

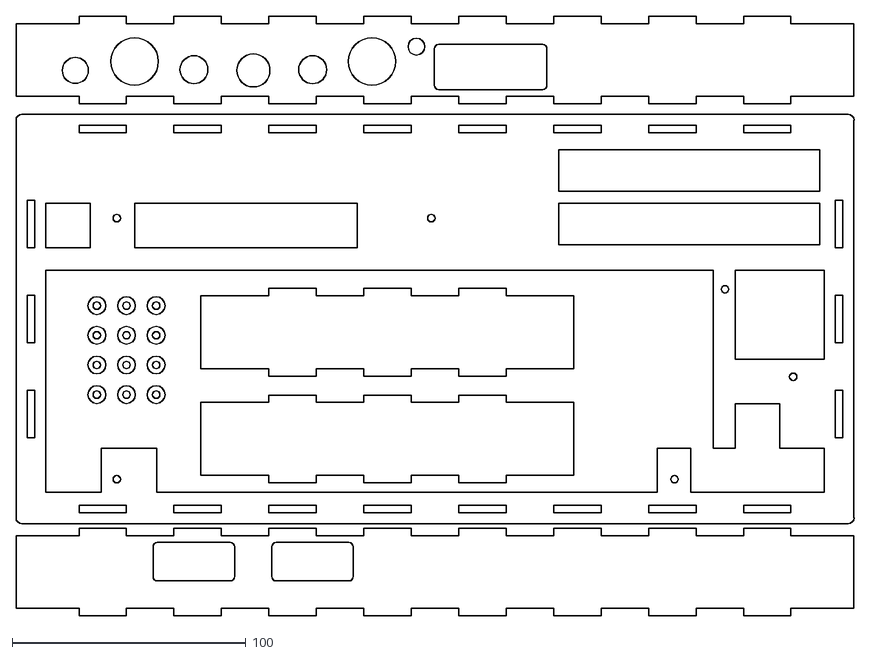
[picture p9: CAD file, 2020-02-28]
Enclosure/Omega-Eco2_User.dxf
358.8 x 256.8

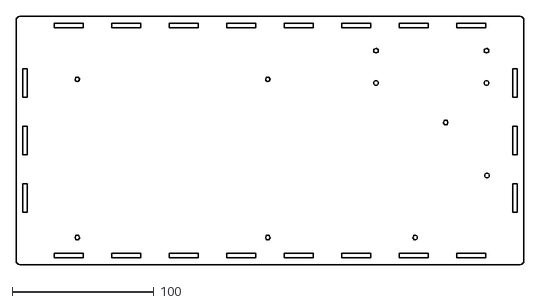
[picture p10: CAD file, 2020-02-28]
Enclosure/Omega-Eco1_User.dxf
358.8 x 175.3

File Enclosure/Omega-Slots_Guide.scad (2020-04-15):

$fn=32;
cartridge_length=109;
cartridge_width=17;
cartridge_spacing=22.86;
bottom_thickness=2.8;
nut_slot_depth=1.8;
connector_length=70.1;
connector_width=9.4;
connector_offset=5;
holes_distance=78.11;
holes_diameter=3.4; // 3 + 0.4
key_diameter=5-0.4; // 5 - 0.4
key_height=10; // 11 - 0.4
key_offset=46;
notch_diameter=5-0.4;
notch_height=10;
tolerance=0.5;
connector_tolerance=0.2;
thickness=2;
bounding_box_length=cartridge_length+tolerance*2+thickness*2;
bounding_box_width=cartridge_width+cartridge_spacing+tolerance*2+thickness*2;
bounding_box_height=15+1.6+10;
difference() {
    // outside shape
    cube([bounding_box_length,bounding_box_width,bounding_box_height]);
    union() {
        // lower slot - cartridge cutout
        translate([thickness,thickness,bottom_thickness]) {
            cube([cartridge_length+tolerance*2,cartridge_width+tolerance*2,bounding_box_height]);
        }
        // lower slot - connector cutout
        translate([thickness+tolerance+cartridge_length/2+5-connector_length/2-connector_tolerance,thickness+tolerance+cartridge_width/2-connector_width/2-connector_tolerance,0]) {
            cube([connector_length+connector_tolerance*2,connector_width+connector_tolerance*2,bottom_thickness]);
        }
        // lower slot - left hole
        translate([thickness+tolerance+cartridge_length/2+5-holes_distance/2,thickness+tolerance+cartridge_width/2,0]) {
            cylinder(d=holes_diameter,h=bottom_thickness);
            // nut slot
            translate([0,0,bottom_thickness-nut_slot_depth]) {
                cylinder(d=5.50*2/sqrt(3), $fn=6, h=nut_slot_depth);
            }
        }
        // lower slot - right hole
        translate([thickness+tolerance+cartridge_length/2+5+holes_distance/2,thickness+tolerance+cartridge_width/2,0]) {
            cylinder(d=holes_diameter,h=bottom_thickness);
            // nut slot
            translate([0,0,bottom_thickness-nut_slot_depth]) {
                cylinder(d=5.50*2/sqrt(3), $fn=6, h=nut_slot_depth);
            }
        }
        // upper slot - cartridge cutout
        translate([thickness,cartridge_spacing+thickness,bottom_thickness]) {
            cube([cartridge_length+tolerance*2,cartridge_width+tolerance*2,bounding_box_height]);
        }
        // upper slot - connector cutout
        translate([thickness+tolerance+cartridge_length/2+5-connector_length/2-connector_tolerance,cartridge_spacing+thickness+tolerance+cartridge_width/2-connector_width/2-connector_tolerance,0]) {
            cube([connector_length+connector_tolerance*2,connector_width+connector_tolerance*2,bottom_thickness]);
        }
        // upper slot - left hole
        translate([thickness+tolerance+cartridge_length/2+5-holes_distance/2,cartridge_spacing+thickness+tolerance+cartridge_width/2,0]) {
            cylinder(d=holes_diameter,h=bottom_thickness);
            // nut slot
            translate([0,0,bottom_thickness-nut_slot_depth]) {
                cylinder(d=5.50*2/sqrt(3), $fn=6, h=nut_slot_depth);
            }
        }
        // upper slot - right hole
        translate([thickness+tolerance+cartridge_length/2+5+holes_distance/2,cartridge_spacing+thickness+tolerance+cartridge_width/2,0]) {
            cylinder(d=holes_diameter,h=bottom_thickness);
            // nut slot
            translate([0,0,bottom_thickness-nut_slot_depth]) {
                cylinder(d=5.50*2/sqrt(3), $fn=6, h=nut_slot_depth);
            }
        }
    }
}
// lower slot - key cylinder
translate([thickness+tolerance+cartridge_length/2-key_offset,thickness+tolerance+cartridge_width/2,bottom_thickness]) {
    cylinder(d=key_diameter,h=key_height);
}
// upper slot - key cylinder
translate([thickness+tolerance+cartridge_length/2-key_offset,cartridge_spacing+thickness+tolerance+cartridge_width/2, bottom_thickness]) {
    cylinder(d=key_diameter,h=key_height);
}

// lower slot - key notch
translate([thickness+tolerance+cartridge_length/2-key_offset,thickness+tolerance*2+cartridge_width,bottom_thickness]) {
    difference() {
        cylinder(d=notch_diameter,h=notch_height);
        translate([-notch_diameter/2,0,0]) {
            cube([notch_diameter,notch_diameter/2,notch_height]);
        }
    }
}
// upper slot - key notch
translate([thickness+tolerance+cartridge_length/2-key_offset,cartridge_spacing+thickness+tolerance*2+cartridge_width,bottom_thickness]) {
    difference() {
        cylinder(d=notch_diameter,h=notch_height);
        translate([-notch_diameter/2,0,0]) {
            cube([notch_diameter,notch_diameter/2,notch_height]);
        }
    }
}

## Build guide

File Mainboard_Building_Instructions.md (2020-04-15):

# Omega Home Computer - Main Board Building Instructions

[Lea este documento en español](Mainboard_Building_Instructions_es.md)

## Prerequisites

### Tools, Equipment, and Supplies

* Soldering iron with a fine tip. Temperature controlled soldering station is recommended
* Needle nose pliers for forming components' leads
* Small side cutters for cutting components' leads
* Universal programmer capable of programming SST39F040 Flash ROM ICs and ATF16V8B SPLDs. For example, MiniPro TL866CS or MiniPro TL866A
* Multimeter with frequency measurement, an oscilloscope, or a logic analyzer can be beneficial for troubleshooting
* Desk lamp, magnifying glass
* Small flat and Philips screwdrivers
* Solder suitable for soldering electronics. For example: rosin core Sn63/Pb37, Sn60/Pb40, or a lead-free solder such as Sn96.5/Ag3.0/Cu0.5 (sometimes referred to as SAC305)
* Solder wick for removing excess of solder
* 99% Isopropyl Alcohol for removing the excess of flux after soldering
* Lint free wipes, used toothbrush, cotton swabs for cleaning the PCB before and after soldering

### Parts

#### Procuring Parts
The list of parts provided in the [Bill of Materials](Mainboard.md#bill-of-materials) section of the [Mainboard.md](Mainboard.md) file. It also provides the recommended sources for the parts.
Most of the parts are available from electronic components distributors such as [Mouser](https://www.mouser.com/ProjectManager/ProjectDetail.aspx?AccessID=11fd34d22c) and [Digi-Key](https://www.digikey.com).
Some older out of production parts are available on eBay and from Chinese electronic components recyclers and resellers.

The Omega PCBs are provided by the members of [RetroBrew Computers group](https://www.retrobrewcomputers.org/doku.php?id=boardinventory#omega_home_computer_project_sergey_kiselev).
Alternatively they can be ordered from a PCB manufacturing service using [Gerber](Mainboard/gerber) or [KiCad](Mainboard/KiCad) files provided in this GitHub repository.

#### Parts Replacement

* The recommended logic family is the Advanced High-Speed CMOS with TTL compatible inputs 74AHCT-series
  * The exception is the slot buffers and transceivers, where 74F-series should be used
  * Possible replacement for 74AHCT-series is High-Speed CMOS 74HCT-series logic
  * 74ALS, 74F, and 74LS series logic might work as well, but have not been tested
* The recommended CPU is the CMOS Z80 variant - Z84C00. Any frequency would work.
  * It might be possible to use NMOS Z80, but it has not been tested
* The recommended SPLD is Atmel ATF16V8B. It can be replaced with Lattice GAL16V8D or similar
  * Make sure that your programmer supports the SPLD type you're planning to use
* The recommended Flash ROM part is Microchip SST39SF040
  * Other 512 KiB or 256 KiB, 5V-only Flash ROM ICs can be used, for example SST39SF020A, AMD Am29F040B
* The recommended SRAM part is Alliance Memory AS6C4008-55PCN
  * Other 512 KiB, TTL compatible SRAM ICs should work, for example Hitachi HM628512, BSI BS62LV4006PC
* It is recommended to use ceramic multilayer capacitors with 5 mm lead pitch
  * It is possible to use 2.5 mm lead pitch or axial capacitors by forming their leads accordingly
  * Electrolytic or tantalum capacitors can be used for C18-C20 10 uF. Make sure to observe the polarity in this case

#### Optional Components

* To be completed

### Other Components Required to Build Functional Computer System

* [Omega Keyboard](Keyboard.md)
* Power supply - 5V regulated power supply with barrel type connector. Or 5V/+12V/-12V power supply if 12V/-12V are desired on the extension slots
* Firmware and software to install and run on the system
  * C-BIOS or MSX2 BIOS
  * MSX-DOS
  * Games

## Building the Omega Mainboard

### Build Sequence

1. Inspect the PCB for obvious defects, such as deep scratches or short-circuits between traces
2. Clean the PCB with an alcohol wipe
3. Solder the components, going from lower profile components to higher profile ones
  * Form the leads and solder the D1 diode. Pay attention to the diode's polarity (the black band on the diode should match the band on the silkscreen)
  * Solder resistors
  * Solder inductors
  * Solder crystal oscillators. Start with 32768 Hz X2 crystal oscillator. Secure it with a piece of wire (e.g. cut resistor lead), solder that piece of wire to the crystal's case.
  * Solder resistor arrays. Pay attention to the orientation - pin number 1 is usually marked with a dot on the resistor array. Square pads on the PCB are used to mark the first pin
  * Solder ceramic capacitors
  * Solder all the DIP sockets. Pay close attention to the orientation of the sockets
  * Solder transistors
  * Solder the jumpers and headers.
  * Solder keyboard connector
  * Solder the F1 polyfuse
  * Solder the S-Video Mini DIN connector
  * Solder the Composite Video and the Audio RCA jacks 
  * Solder the extension slot PCB edge connectors
  * Solder the printer connector
  * Solder electrolytic capacitors. Pay attention to the capacitors' polarity
  * Solder the cassette recorder and the RGB DIN connectors
4. Carefully inspect all the solder joints. Re-solder if needed. Optionally use a multimeter to check the board for short-circuits, and for the power supply signals connectivity
5. Clean the board using cotton swaps, wipes, and the toothbrush soaked in alcohol
6. Program the Flash ROM with the BIOS image (Todo: Add image instructions)
7. Program the SPLDs with the [fuse maps](Mainboard/SPLD)
8. Carefully install ICs into the sockets. Use a hard non-static surface to bend the pins of ICs in DIP packages as needed. Double check the orientation of the ICs. Make sure that all ICs pins are inserted into the sockets, and not bent.
9. Inspect the completed board once again
10. Install the configuration jumpers. Refer to the [Jumpers](Mainboard.md#jumpers) section of the [Mainboard.md](Mainboard.md) file
11. Connect the keyboard PCB
12. Connect the display or TV and the power supply
13. Turn on the power, test the board, run your favorite software, and enjoy!

## Troubleshooting Tips

* Inspect your board for any soldering issues
* Check the jumpers settings
* Make sure that your system is getting the power, and that power supply voltage is within 5% range of the nominal voltage (5 V)
* Start troubleshooting using C-BIOS image first. Once C-BIOS boots, proceed with MSX2 BIOS
  * C-BIOS will initialize the VDP (and show an error message) even the SRAM is not installed or if components related to SRAM are not working.
  * C-BIOS does not access the RTC, and will boot and work even if the RTC IC (U5 RP5C01) is not installed or defective.
* Observe the system activity
  * Does it produce any picture?
    * Does your display or TV show "no signal" message? In this case VDP is not being initialized correctly, or there is an issue with the NTSC/PAL encoder U47 (CXA1645). Check VDP output and U47 input signals.
    * Does your display show that NTSC or PAL input has been detected, yet the screen is black? If using MSX2 BIOS, this likely means that the CPU can't access the RTC IC U5 (RP5C01). Try using C-BIOS instead. It doesn't access RTC, and should work in this case.
  * Using multimeter with the frequency measurement function or an oscilloscope check key CPU and VDP signals:
    * CLK signal on U3 (VDP), pin 8. It should be a 3.579545 MHz square wave signal
    * CLK signal on U1 (CPU), pin 6. It should be a 3.579545 MHz square wave signal
    * A0 signal on U1 (CPU), pin 30. This is a good indicator of CPU activity. There should be a few hundred kHz pulses
    * /RD and /WR signals on U1 (Z80 CPU), pins 21 and 22 respectively. These signals are also a good indicator of CPU activity. There should be a few hundred kHz pulses
    * /MEM_RD signal on U26, pin 1. This signal generated (goes low) every time CPU fetches data from memory. There should be a few hundred kHz pulses
    * /ROM_CS and /RAM0_CS signals on U6 (Flash ROM) pin 22, and U7 (SRAM) pin 22 respectively. These signals go low every time CPU accesses Flash ROM or SRAM. 
    * CSYNC signal on U3 (VDP), pin 6. It should be 15.734 kHz signal for NTSC	15.625 kHz for PAL.
    * SYNCIN signal on U47, pin 10. It should be 15.734 kHz signal for NTSC	15.625 kHz for PAL.
    * SCIN signal on U47, pin 6. It should be 3.579545 MHz for NTSC and	4.433618 MHz for PAL.
    * RED, GREEN, and BLUE signals on U3 (VDP), pins 23, 22, and 24 respectively.

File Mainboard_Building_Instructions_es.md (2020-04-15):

# Omega Home Computer. Instrucciones para construir la Placa Base.

[Read this document in English](Mainboard_Building_Instructions.md)

## Requisitos Previos.

## Herramientas, Equipo y Componentes
* Soldador de punta fina. Estación de soldadura con control de temperatura sería recomendable.
* Alicates de punta fina para modificar las patillas de los componentes.
* Alicates de corte lateral para cortar las patillas de los compponentes.
* Programador de Chips Universal con capacidad para programar chips SST39F040 Flash ROM y los SPLDs ATF16V8B. Por ejemplo un MiniPro TL866CS o MiniPro TL866A
* Multimetro con medidor de frecuencia, un osciloscopio o un analizador lógico pueden ser beneficiosos para solucionar problemas.
* Lampara de escritorio, Lupa
* Destornilladores pequeños plano y estrella (Philips)
* Estaño adecuado para electrónica. Por ejemplo: rosin core Sn63/Pb37, Sn60/Pb40, o estaño libre de plomo tipo Sn96.5/Ag3.0/Cu0.5 (a veces referido como SAC305) 
* Malla para desoldar y retirar el exceso de estaño
* Alcohol Isopropílico al 99% para quitar el exceso de flux tras soldar
* Toallitas libres de pelusa, un cepillo de dientes usado, algodoncillos para limpiar la PCB antes y después de soldar.

### Componentes

### Adquisición de los componentes
La lista de componentes proporcionada en [Lista de componentes](Mainboard_es.md#lista-de-componentes) que forma parte de la sección del fichero [Mainboard_es.md](Mainboard_es.md). También aporta fuentes recomendadas para adquirir los componentes.
La mayoría de los componentes están disponibles en distribuidores habituales como [Mouser](https://www.mouser.com/ProjectManager/ProjectDetail.aspx?AccesID=11fd34d22c) y [Digi-key](https://www.digikey.com).
Algunos componentes antiguos y fuera de producción están disponibles tanto en eBay como en páginas de recicladores y revendedores de componentes electrónicos chinos.

Las placas (PCB) del Omega son facilitadas por los miembros de [RetroBrew Computers group](https://www.retrobrewcomputers.org/doku.php?id=boardinventory#omega_home_computer_project_sergey_kiselev).
Como alternativa pueden ser encargarlas a una empresa de  fabricación de PCB usando los ficheros [Gerber](Mainboard/gerber) o [KiCad](Mainboard/KiCad) facilitados en este repositorio GitHub.

#### Remplazo de Componentes

* La familia de integrados lógicos recomendada es la serie 74AHCT-series consistente en CMOS Avanzado de alta velocidad con entradas compatibles con TTL.
  * Como excepción para los slots de buffers y transceivers se usarán la serie 74F (74F-Series)
  * Un posible reemplazo para los 74AHCT-series es la serie de CMOS 74HCT-series de alta velocidad.
  * 74ALS, 74F, y 74LS series pueden funcionar también pero no han sido probados.
  * La CPU recomedada es la variante CMOS del Z80 - Z84C00. Cualquier frecuencia debería de funcionar.
  * Cabría la posibilidad de usar una Z80 NMOS pero no ha sido probada
  * El SPLD recomendado es el Atmel ATF16V8B. Puede ser reemplazado por un GAL16V8D Lattice o similar
  * Asegúrate que el programador que uses tenga soporte para el SPLD que estés planeando usar
  * La Flash ROM recomendada es la SST39SF040 de Microchip
  * Se pueden utilizar otros chips de Flash ROM compatibles (512 KiB o 256 KiB a 5V (5V-sólo) como por ejemplo SST39SF020A o el AMD Am29F040B
  * El chip de SRAM recomendado es el AS6C4008-55PCN de Alliance Memory
  * Otros chips compatibles para SRAM (512 KiB con TTL) deberían funcionar como por ejemplo HM628512 Hitachi, BS62LV4006PC BSI
  * Es recomendable usar condensadores cerámicos multi-capa con al menos 5mm de distancia entre patillas
  * Se pueden usar condensadores con distancia entre patillas inferiores (2.5mm) o condensadores axiales modificando adecuadamente sus patillas con los alicates de punta fina
  * Es posible usar condensadores electrolíticos o de Tántalo para C18-C20 10 uF. Asegúrate de fijarte bien en la polaridad en este caso

#### Componentes opcionales

* Pendiente

### Otros componentes requeridos para construir un Ordenador Omega funcional

* [Teclado Omega](Keyboard_es.md)
* (PSU) Fuente de alimentación regulada de 5V con conector tipo cilíndrico. O fuente de 5V/+12V/-12V si se desea 12V/-12V en los slots de extensión
* Firmware y software para instalar y cargar el sistema
  * C-BIOS o BIOS de MSX2
  * MSX-DOS
  * Juegos

## Construyendo la Placa Base del Omega

### Secuencia de construcción

1. Revisa la PCB para hallar defectos evidentes como arañazos profundos (que muestren el cobre donde no debe) o corto-circuitos entre pistas
2. Limpia la PCB con un toallita de alcohol isopropílico libre de pelusa (o de algodón + alcohol isopropílico) 
3. Suelda los componentes empezando por aquellos que tienen perfil más bajo y acabando por los de mayor perfil
  * Dale forma a las patillas del diodo D1 y suéldalo. Pon atención a la polaridad del diodo. (La banda negra del diodo debe coincidir con la banda representada en la serigrafía)
  * Suelda las resistencias
  * Suelda los inductores
  * Suelda los osciladores de cristal de cuarzo. Empieza con X2, el cristal de 32768 Hz. Asegúralo con un trozo de cable o patilla (p. e. una patilla de resistencia cortada). Suelda esa patilla a la carcasa del cristal de cuarzo.
  * Suelda las arrays de resistencias. Pon atención en la orientación. El pin 1 suele estar marcado con un punto en su encapsulado. En la PCB el pad cuadrado (topo) se usa habitualmente para marcar también el pin 1
  * Suelda los condesadores cerámicos
  * Suelda todos los zócalos de integrado. Pon mucha atención en la orientación de los zócalos.
  * Suelda los transistores
  * Suelda los jumpers y headers
  * Suelda el conector de teclado
  * Suelda el fusible F1
  * Suelda el conector Mini Din del S-Video
  * Suelda los conectores RCA de Video Compuesto y Audio
  * Suelda los conectores de slot de expansión
  * Suelda el conector del puerto de impresora
  * Suelda los condensadores electrolíticos. Pon atención en la polaridad de estos
  * Suelda los conectores DIN para la grabadora de cassette y para el conector de Video RGB
4. Inspecciona cuidadosamente todas las soldaduras. Repasa las soldaduras que creas necesario. Opcionalmente usa un multímetro para buscar corto-circuitos de la placa y para medir la conectividad de la línea alimentación
5. Limpia la PCB usando toallitas, bastoncillos de algodón y el cepillo de dientes mojados en alcohol.
6. Programa la Flash ROM con la imagen de la BIOS (pendiente: añadir instrucciones de la imagen)
7. Programa las SPLDs con el [esquema de fusibles SPLD](Mainboard/SPLD)
8. Inserta cuidadosamente los integrados en sus zócalos. Si no entran, usa una superficie libre de estática para doblar los pines de los integrados. Repasa la orientación de los integrados (IC). Asegúrate de que todos los pines del integrado entran en el zócalo y no se doblan.
9. Inspecciona toda la placa una vez más.
10. Instala los jumpers de configuración. Están referenciados en la sección [Jumpers](Mainboard_es.md#jumpers) del fichero [Mainboard_es.md](Mainboard_es.md)
11. Conecta la placa del teclado
12. Conecta la pantalla o TV y la fuente de alimentación a la placa
13. Enciende la fuente, testea la placa, carga tu software favorito y disfruta!

## Consejos para solucionar problemas

* Inspecciona la placa para encontrar posibles problemas de soldadura
* Repasa la configuración de jumpers
* Asegúrate de que tu sistema está correctamente alimentado y que la fuente de alimentación está dentro del rango del 5% del voltage nominal (5 V)
* Empieza por solucionar los problemas usando la C-BIOS primeramente. Una vez la C-BIOS arranca, prosigue con la BIOS MSX2
  * La C-BIOS iniciará el VDP (y mostrará un mensaje de error) aún no teniendo instalada la SRAM o si los componentes relativos a esta no funcionan correctamente.
  * C-BIOS no accede al RTC, arrancará y funcionará incluso si el integrado del RTC no está instalado o es defectuoso.
* Observa la actividad del sistema
  * Se ve alguna imagen?
    * Muestra tu pantalla o TV el mensaje “sin señal”? En este caso el VDP no está funcionando correctamente o hay algún problema con el codificador NTSC/PAL U47 (CXA1645). Revisa la salida VDP y las señales de entrada de U47.
    * Muestra tu pantalla o TV que ha detectado una entrada NTSC/PAL pero mantiene la pantalla en negro? Si estás usando la BIOS MSX2 significa que la CPU no puede acceder al RTC (IC U5 / RPC5C01). Prueba con C-BIOS en su lugar. Esta no accede al RTC y puede funcionar en ese caso.
  * Usando un multimetro con la función de medida de frecuencia o con un osciloscopio revisa las señales clave de la CPU y del VDP:
    * La señal CLK en U3 (VDP), pin 8. Debe ser una onda cuadrada a 3.579545 Mhz
    * La señak CLK en U1 (CPU), Pin 6. Debe ser una onda cuadrada a 3.579545 Mhz
    * La señal A0 en U1 (CPU), Pin 30. Esta es un buen indicador de la actividad de la CPU. Debería ser un pulso de pocos cientos de Khz
    * Las señales /RD y /WR en U1 (CPU), Pines 21 y 22 respectivamente. Estas señales son también un buen indicador de la actividad de la CPU. Debería ser un pulso de pocos cientos de Khz
    * La señal /MEM_RD en U26, Pin 1. Esta señal desciende cada vez que la CPU busca datos de la memoria. Debería ser un pulso de pocos cientos de Khz
    * Las señales /ROM_CS y /RAM0_CS en U6 (Flash ROM) pin 22 y U7 (SRAM) pin 22, respectivamente. Estas señales descienden cada vez que la CPU accede a la Flash ROM o a la SRAM.
    * La señal CSYNC en U3 (VDP), Pin 6. Debería ser una señal a 15.734 kHz para NTSC y 15.625 kHz para PAL.
    * La señal SYNCIN en U47, Pin 10. Debería ser una señal a 15.734 kHz para NTSC y 15.625 kHz para PAL.
    * La señal SCIN en U47, Pin 6. Debería ser una señal a 3.579545 MHz para NTSC y 4.433618 MHz para PAL.
* Las señales ROJO, VERDE y AZUL en U3 (VDP), Pines 23, 22 y 24 respectivamente.

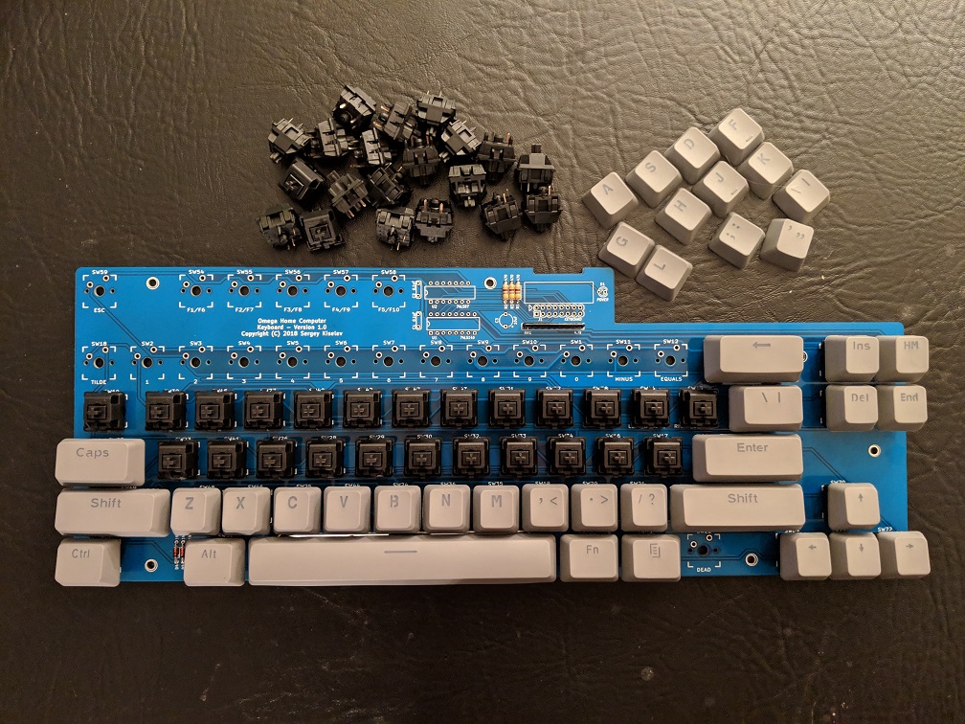
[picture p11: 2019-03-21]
Keyboard/images/Omega_Keyboard-Building.jpg

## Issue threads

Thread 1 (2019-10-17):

Some small suggestions for improvement

sdsnatcher, 2019-10-17:
After checking the circuit, here goes some small suggestions for improvement. I hope it helps.

- It's highly recommended to have a good filter for the pin-21 of the VDP. This can improve the image quality and stay away from jailbar issues
- The CXA-2075 is a newer TV-encoder that is pin-compatible with the CXA-1645 and offers much superior image quality. The required external circuitry is also simpler.
- Ideally, the pinout of the RGB connector should be the same as the Japanese MSX machines, even if it's a mini-DIN. Better yet if it was a normal DIN8 connector, so existing cables can be used. Another very good option is to use a DE-15 connector with the VGA pinout, as many projectors and scalers are designed to accept 15kHz this way.
- A pin header connector for the VDP ColorBus would be welcome for hardware tinkerers, following the [pinout shown in the MSX Turbo-R Datapack](http://ngs.no.coocan.jp/doc/img/datapack/7%25BE%25CF%2BMSX2%252B%25B2%25F3%25CF%25A9%25CE%25E3.%25BF%25DEP51.png). (Obs: CBDR should connected to the pin-1, and this is missing on this link). You can keep the pull-ups as you designed.
- Similarly, a pin-header to allow easy connection of a superimposer circuit
- It's recommended to add some sort of bus contention protection on the joystick ports, since a lot of European software tend to misconfigure the PSG via direct I/O, and this could fry it
- It's also recommended to add bus contention protection to the PPI port-B, as poorly written software might configure it for output, and then if some key is pressed, the port-B can be fried.
- It might be a good idea to add fusistors to the +5V pins of every joystick port, RGB-out and  for protection against short circuits. These didn't exist back at the MSX era, but are cheap nowadays.
- It might also be a nice idea to add fusistors for the +5V/+12V/-12V pins of the slots
- If the machine doesn't have the slot hot-insertion protection circuit, both the pins-44 and 46 of the slot should be connected to GND.
- It's advisable to have 100R series resistors on the slot signals, like Panasonic did in their MSX2+ and TR machines, to avoid ringing and protect the circuit
- All MSX machines have the keyboard pull-up resistors on the motherboard instead of the keyboard PCB. This allows the machine to work even with the keyboard disconnected, for easier maintenance.
- A pin header to connect RESET and NMI buttons will be welcome for developers

Last, some questions:
- Where does the KBD_WAIT signal comes from? I couldn't find it anywhere

skiselev, 2019-10-18:
Thank you for your suggestions!
Generally speaking I'd like to keep this design as simple as practically possible. So some features are intentionally missing. Also at this stage I don't want to make significant schematic or PCB layout changes.

- VDP pin 21 is only connected to a 470 ohm pull-down. It is not used to produce composite video. Also V9958 uses this as an additional VCC. I am not sure what filter needs to be there and why.
- CXA2075: I didn't want to use SMD components. But since CXA1645 and CXA2075 have similar layout it should be possible to make a simple SOIC to DIP adapter PCB. BTW, I was considering using AD724 but decided against it because it is an SMD IC
- I've changed both RGB and Cassette connector to DIN-8 with the standard MSX pinout. Please check the layout / schematic again.
- I'll check if I can squeeze in a color bus connector
- I am not quite sure what is a practical use of superimposer
- PSG/PPI protection - I am not sure what kind of protection? Just add resistors in series?
- Polyfuses - generally modern power supplies have short circuit protection. Also we are talking about only a few amperes current at most. With that being said, I'll see if I can add polyfuses for joystick ports. YS/AV pins of RGB are connected through resistors, so they should not cause short circuit.
- Pins 44 and 46. I'll fix it. Thanks! By the way, I did some research. I couldn't find any definite answer to where these pins should be connected. At least one MSX2 machine has only pin 44 is connected to the ground.
- 100 ohm to reduce ringing - might be a bit of overkill for 3.5 MHz bus. I also use TTL bus drivers that have somewhat slower switching characteristics compared to CMOS.
- Keyboard pull-ups. I'll fix it. Thanks!
- Pin headers for NMI and RESET - definitely a possibility. I'll see if I can squeeze in these.
- KBD_WAIT - is a leftover from earlier version. It was supposed to help with keyboard emulation using a micro-controller. It is not relevant any more and can be removed.

sdsnatcher, 2019-10-18:
- VDP pin21: The V99x8 is very susceptible to noise. Yamaha provided a separate supply for the V9958 DAC as they learned their lessons on the V9938. If you google for "Philips V9958 upgrade noise" you'll see that the most common problem of MSX2 machines upgraded to use the V9958 is a noisy video output. Nothing fancy is required, just a simple/compact LC filter will do, preferably one for each Vcc pin, and as close as possible to that pin. Given that many peripherals (that will be connected to the slot) now have switching power supplies, it's recommended to add LC filtering to the CXA-1645 Vcc pins too.

skiselev, 2019-10-19:
I've fixed the following:
1.  VDP and CXA1645 power supply now goes through a pair of LC filters.
2. Added a polyfuse for joystick ports... A single 740 mA polyfuse should be enough for both ports.
3. Connected slots pin 46 to GND
4. Added a 4.7 k pull-up resistor array for all keyboard column inputs.
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
sdsnatcher, 2019-10-19:
- Maybe it's better to use +12V/-12V to supply the opamps. This way you won't have to worry about biases, and how it might interact with the audio circuit of the cartridges that will be connected to the slot.

skiselev, 2019-10-19:
A couple of questions:
- I think that for color bus it won't be enough to have just the color bus data and the direction signal. At least the dot clock is required for simple RAMDAC application. Also GND and 5V would be useful if. What other signals does it need?
- Superimpose - what signals we are talking about here? YS? Video signals / sync?

Comments:
- Single supply op amp LPF works just fine. The inputs are decoupled with capacitors (even in case of a dual supply op amp they are), so it should not make any difference for cartridges sound output. Nothing else on the board uses 12V/-12V. I assume some cartridges might... In this case I provide a header to connect 5V/12V/-12V supply.
- I will swap the slot numbers
- It should be possible to solder a right angle edge connector for the top slot. The only problem is to find one...

sdsnatcher, 2019-10-19:
> I think that for color bus it won't be enough to have just the color bus data and the direction signal. At least the dot clock is required for simple RAMDAC application. Also GND and 5V would be useful if. What other signals does it need?

You're right. According to the Philips NMS-8280 service manual, the dot clock (DHCLK) is also needed.

- The superimposer is easier to be done on the V9958, so I would worry about this one. The signals required are: YS, DLCLK,  VRESET, HRESET.

> It should be possible to solder a right angle edge connector for the top slot. The only problem is to find one...

Tip: they're being sold [here](https://www.ebay.com/itm/5pc-Industrial-Card-Edge-Slot-Socket-Connector-25x2P-50P-2-54mm-0-1-Right-Angle/130970278382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) for many years. He also has a [listing for larger quantities](https://www.ebay.com/itm/50x-Industrial-Card-Edge-Slot-Socket-Connector-25x2P-50P-2-54mm-0-1-Right-Angle/130970278891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) if needed. I purchased those to replace defective slots on some of my MSX machines, and they worked very well. The fact that they have no flanges wasn't a problem. (BTW, he also has the straight slot connector type if you need them)

An alternative trick is to design a male EDGE connector on the PCB facing backwards, and solder the slot connector directly on it. People have been doing this trick for years [to add the rear slot to the Yamaha CX5M computers](https://www.msxpro.com/cx5m.html#slot), and it works like a charm.

sdsnatcher, 2020-09-10:
I have a suggestion for the RAM circuitry that can save space on a next revision of the motherboard, see if you like it:

- Eliminate U32
- Add the following pins to the J12 header:
  - /RAM_SL and /RAM0_CS, side-by-side. They'll be connected by a jumper when no RAM expansion daughterboard is present
  - A19 to A21
- Eliminate the /RAM1_CS to /RAM7_CS pins from the J12 pin header. A RAM expansion board could easily generate itself /RAM0_CS to /RAM7_CS from the other pins of J12.
- Eliminate U26. If necessary, it can also be placed on the RAM expansion board.

skiselev, 2020-09-10:
I actually was considering this implementation initially. U32 is indeed optional, it is likely that most users will not ever upgrade the memory beyond 512 KiB, and in this case U32 can be omitted and /RAM_SL can be connected directly to /RAM0_CS.
I am unsure about U26... Eliminating it might make system less stable. There are too many things connected to the data bus already ;-) We can do an experiment, and replace it with some wires :-)

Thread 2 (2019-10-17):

Suggestion: Turbo support

sdsnatcher, 2019-10-17:
I added this suggestion here on its own issue, to avoid cluttering on the MSX.org news thread.

In fact, the [circuit for the turbo is very simple](https://hansotten.file-hunter.com/do-it-yourself/clock-upgrades/#what-is). For the MSX1 and MSX2, the turbo will be disabled on all I/O operations, but it still can provide a very welcome boost in performance. An MSX1 at 5.37MHz with this turbo can run ZX-Spectrum ports at their correct speed, i.e.

As mentioned before, for the MSX2+ it's possible to speed-up the access to the VRAM, thanks to the V9958 /WAIT feature. For this, Belavenuto and myself have designed a GAL logic that:

1) Turns the turbo ON/OFF at the switched I/O port 41h
2) Disables the turbo for a selection of I/O ports, but not the VRAM I/O port.

It only can't read the status of the turbo, as it was designed to complement implement the turbo on Sanyo2+ machines, and those already provide the turbo status feature internally. You probably would be able to easily add the turbo status feature

If you're interested, I can gladly send you the .EQN file for the turbo GAL as an open-source contribution.

sdsnatcher, 2019-10-18:
Temp

> frankly, the benefit won't be that great.

I beg to disagree. Once you have used a turbo MSX machine, you won’t want to go back and will start wondering why they haven’t done this before     ;)

There are plenty of heavy games and apps that will run much better when a turbo is present. Just to name a few:

- Games: Metal Gear 2, Space Manbow, King’s Valley 2, Penguin Adventure, Undeadline, Snatcher, SD Snatcher, Valis 2, Ys 3, any ZX-Spectrum port, any PC-88 port, Aleste, Aleste 2, 1942, Gunship, Sim City, Red Zone, Tales of Popolon, Playball 3, Xak1/2/3, Fray, Illusion City, etc
- Apps: Nextor/MSX-DOS2, SymbOS, Graph Saurus 2.0, Philips Video Graphics, Print Shop II, InterNestor, MUE, MGSplay, etc

> To replicate turbo functionality I would
need to implement:
> Glitch-less clock switching circuit, an I/O port to turn on/off turbo,

As you have seen, the SuperTurbo design is very simple and compact

> a wait state generator to generate additional wait states when accessing PSG

SuperTurbo takes a very simple approach to this. It just lowers the clock when needed

> and perhaps the cartridge slots.

Not really necessary, for speeds up to 10MHz. But the approach I use when I want to be conservative is to connect the SLTSL pin of the slot-1 to one of the SuperTurbo break inputs. This allows a flexible configuration where the slot-2 is the “turbo slot” and the slot-1 is the “slow slot”. On a new motherboard like this, configuration switches could be added to select if a slot will be turbo or not.

sdsnatcher, 2019-10-19:
> As far as circuit protection and turbo goes, I simply don't have the real estate on the board to implement these. Turbo is on my wish list for a CPLD implementation.

Ok.  For the current PCB, maybe it could be added as a daughterboard later. It seems to be possible since you took great care on the mobo design. Just please add simple jumpers to each slot /CPUCLK signal, to make it easier to inject the turbo clock there for a specific slot if needed.

Due to being very simplistic, the SuperTurbo is a good design to add turbo for older machines, or when space/cost/DIP-requirement are of concern. If you're going to use a CPLD, then it's much better to take the wait-state generator approach.

The VDP requires a custom waitstate generator. Please let me know at this thread when you decide to implement it, so I can come back to describe the specifications. A generic waitstate generator will have a horrible impact on the CPU->VDP access, as happened on the MSX Turbo-R.

Pax-nl, 2025-04-17:
Is there an update for this enhancements?
There are several mentions about a Turbo “mode” and it is also state it is on the list of enhancements for future releases..

I ask because games like Blade Lords can really benefit from a speed boost. Next to the games and apps SDSnatcher mentioned.

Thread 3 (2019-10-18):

Installing different video chips

Wierzbowsky, 2019-10-18:
The spec claims that the board either takes v9938 or v9958 chip. But these chips have slightly different pinout. For example when installing v9958 instead of v9938 on Russian MSXs made by Yamaha, several additional wires need to be soldered. Also a diode needs to be installed between Z80 and v9958. How do you plan to solve these issues on the same board?

skiselev, 2019-10-18:
These issues are already solved :-)
There are three major differences between V9938 and V9958 pinout:
1. Pin 21 - V9938 uses this pin as composite video output, V9958 uses it as power supply for video DAC. Omega has a a jumper JP3 that allows switching between these two functions
2. Pin 26 - V9938 can use this pin as a light pen switch input. V9958 uses it as /WAIT signal to CPU. In Omega this pin is connected to a pull-up resistor and to the WAIT circuit. As the result, with V9938 this pin remains logic "high" and does not affect system operation. V9958 would pull this pin "low" when it needs a wait state, and that would result in the CPU /WAIT pin becoming "low" as well.
3. Pin 5 - Both V9938 and V9958 use this as CSYNC output. The output voltage levels are different though. V9938 outputs about 2.5 V for "low' and about 5V for "high", while V9958 outputs standard TTL logic levels. In Omega this pin is connected to an emitter follower and then 74HC04 NOT gate. That should work in either case.

Closed 2019-10-30.

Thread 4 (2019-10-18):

Optional FM-PAC

Wierzbowsky, 2019-10-18:
I would recommend to implement an optional FM-PAC mono functionality on the board. Or to create a socket for an optional FM-PAC daughterboard.

skiselev, 2019-10-18:
I would not add OPLL YM2413 in this board revision. At this stage of the project it will require major rerouting of the board, and other than that I don't have an available SPLD pin to generate chip select signal for OPLL.
I'll keep it on the list of the possible improvements for the future board upgrades.

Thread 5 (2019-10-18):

Simple floppy disk controller

Wierzbowsky, 2019-10-18:
A computer without a floppy disk controller requires purchasing an additional cartridge that offers IDE or FDC functionality. I would recommend to add a simple floppy disk controller (TDC-600 or similar) onto the board and a 34-pin connector for a floppy drive or Gotek emulator. Also a power socket with 5v and 12v could be useful to connect the Molex power connector for a drive.

skiselev, 2019-10-18:
FDC will not be added in the current revision of the project.
It is already on my list of the future upgrades. It is quite possible that I'll remove printer and cassette recorder circuits (who needs that? 😄) and replace it with the FDC.
By the way, 3.5" floppy drives only need 5V power supply and do not use 12V.

Wierzbowsky, 2019-10-18:
Better keep LPT and CAS for compatibility. If disk drive dies, the only way to load games would be the cassette port. The LPT is rarely used, but it's better to keep it for the authentic feeling.

sdsnatcher, 2019-10-19:
I like the idea of an internal floppy drive, but some ponderations must be done considering the way this machine was designed.

Adding an internal floppy interface is only useful if the floppy is internal too. Otherwise, it will only be an annoyance, because:

1) It will slow down the boot when the drive isn't present. The interface will keep waiting for the drive until it times out
2) It will eat up memory for nothing
3) If someone has an external drive+power supply, what's the difference of having a cartridge interface to use it too?

But if the drive is going to be internal, this machine was designed with the two slots occupying the right side of the PCB. This means it wont be possible to install an internal floppy on the right side like all all-in-one machines like the MSX and compact Amigas have. Maybe the floppy could be placed facing the left side, but it feels so awkward.   :)

The TDC-600 has the advantage of having a PC FDC, but its address decoder circuit is stupid.  That should be improved to place the FDC at the correct range at the end of the frame-1, because the way the FDC has to be accessed now requires a lot of  unnecessary slot juggling and is incompatible with the MSX-Audio extension.

skiselev, 2019-10-19:
I am open for suggestions for modifying TDC-600 or similar FDC. I was planning to build one for my system anyway.
Relocating FDC registers elsewhere would require modifications to the floppy BIOS. Is there a source available?

sdsnatcher, 2019-10-19:
Disassembled sources for the FDC drivers of nearly all MSX interfaces are available [here](https://sourceforge.net/projects/msxsyssrc/). More specifically, at [this folder](https://sourceforge.net/p/msxsyssrc/git/ci/master/tree/diskdrvs/).

If you're going to implement a brand new floppy disk interface cartridge, some other improvements could be done that would be **very welcome**:

- Fix the TDC-600 design mistakes
- HD floppy disk support (1.2MB & 1.44MB)
- Native Nextor support

If such an interface was built, I would buy it [without blinking](https://i.kym-cdn.com/entries/icons/original/000/005/574/takemymoney.jpg).    :)

------------------------------
Here's one draft of how a new disk interface cartridge could be implemented:
(It's meant to be as close as possible to the Turbo-R disk interface design, with some enhancements):

7FF0h: DiskROM frame-1 page select
7FF1h: Digital Status register
 when read:
   bit0: /HD0
   bit1: /HD1
   bit2: /READY0
   bit3: /READY1
   bit4: /DiskChange0
   bit5: /DiskChange1
   bit7: FDC IRQ pin status
 when written:
   bit7: 0=Suppress FDC interrupts, 1=Allows FDC interrupts  (this must be ANDed to the FDC IRQ pin, and the result negated and sent as open-collector to the MSX /INT pin)

7FF2h: Operations Register		(w/o)
7FF4h: Main status register		(r/o)
7FF5h: Data register			(r/w)
7FF8h: Configuration Control Register	(w/o)

7FFEh: 1kHz countdown timer (used to wait for timeouts, regardless of the CPU speed)
7FFFh: DiskROM frame-2 page select (to simplify flashROM updates)

7C00h-7DFFh: Data transfer window	(r/w)  Available only on page-7, allows LDIR to be used for DMA-like data transfers. When accessed:
  - Must activate the /DACK pin of the FDC
  - Must generate /WAITs for the Z80 based on the FDC /DMA pin status

To allow unmodded PC drives to work easily, PIN-34 should be kept as /DC and pin-2 should be /RDY (with a pull-up resistor). Yes, this is the opposite of the Shuggart interface (and Amiga), but this way the /RDY will work just as a accelerator bonus for those who mod the drive. It will also be much simpler to mod the drive.

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

msx-solis, 2020-02-21:
It would be possible taking advantage from the SD & floppy circuits from the N8 project?
https://www.retrobrewcomputers.org/doku.php?id=boards:sbc:n8:n8
It would be great having a hard disk included in the mainboard.

skiselev, 2020-02-21:
Technically it is not difficult to implement floppy or CF interfaces.
For floppy there is WC37C65 FDC controller that several of my previous projects and N8 uses it too.
CF cards support a 8-bit interface that can be connected directly to Z80 (perhaps adding a 74HCT245 transceiver). But then CF cards are becoming somewhat difficult to obtain.
SD cards support is not that easy to implement. N8 uses a built-in Z180 serial port to implement it. Obviously, there is nothing like that on Omega.

As I've already mentioned, I have several issues with implementing either one of these storage interfaces:
- Software support. I don't have time to do that. If there are volunteers that can write Disk BIOS, we can talk
- Board's real estate. In order to add another component, I'll need to remove an existing one. The printer port and the cassette recorder interface are likely candidates to be removed. Of course I can go CPLD route to reduce the number of discrete logic ICs and free up some space. The disadvantage in this case is that builders will need to get a JTAG adapter to program CPLDs. Also the availability of 5V-tolerant SPLDs is questionable (there are a few that are pretty much on life support)
- Finally, cartridges that implement mass storage functionality are available. Which makes it mostly a 'nice to have' feature. Yes I get that some MSX people want to have 2 slots available for something else... but then there are also slot extenders ;-)

msx-solis, 2020-09-06:
I think we can add a pin header in future OMEGA versions, something like a third cartridge but I / O. Several people would like to have a disk system without losing any of their cartridge slots, however, I don't think everyone wants the same disk system and it is best not to impose it.
Since OMEGA's ROM is so easy to modify, my solution would be to add a pin strip that would allow you to connect an I/O cartridge port.
That way, everyone could add an interface without memory and their own disk system, modify the BIOS to their liking. Furthermore, this solution does not force to increase the size of the motherboard.
Anyone who wants a disk system could plug in a ROMless TDC-600 and add that disk BIOS to OMEGA's ROM. If you prefer a compact flash disk, do the same but using that interface. If they don't want a disk, no one will have to wait for a delay in system startup.

JmanNZ, 2020-10-04:
Just so I am clear will the TDC-600 cartridge work as is or does the bios require a modification ?

msx-solis, 2020-10-04:
What I'm suggesting is a way to connect a floppy interface (or another disk interface) without loosing a slot card on it. My suggestion was to have an internal i/o slot, not full slot cartridge.
unfortunately that kind of disk interface is not common on the MSX, they used to use memory ranges to communicate even with WD34C65 chip, not only on-cartridge BIOS expansion.
In some other Z80-CPM systems the communication with that chip was through I/O ports.

JmanNZ if you build the TDC-600 and insert it on a slot cartridge it will work without BIOS modification

Leshak-pcb, 2023-03-03:
I'm currently building my Omega MSX & I also want to make a FDC for it. My suggestion is to use a i82077 controller, at 7FF0h. Only 3 ICs needed for address decoder - 74ls133 for A4-A14, one inverter for /A3 (another one for IRQ, if needed) and 74ls139 to select either FDC or ROM, with its enable pin connected to SLTSL. All main registers (data, control, operations) will line up with turboR FDC. WD37C65, TC8566F & i82077 are uPD0765 compatible, even direct-access software should work.
Although after some digging through FDC ROM sources I've ended up with a thought that a new one is needed, made from scratch. And my programming skills are barely enough to patch existing ROMs.

msx-solis, 2023-03-03:
Hi Guys.
I have a new FDC controller design for the omega MSX based on Microsol CDX-2 FDC by port.
I have two version for this controller board, as slot cartridge and as internal cpu hat (to avoid spending a slot for the controller) of curse you don't need to upgrade BIOS for any cartridge version but you have to add this ROM driver to the omega system bios if you want the internal version.
I have just shared the cartridge version on my github and I will share the internal one soon.
regards.

dude22072, 2023-12-05:
@msx-solis Do you still plan on sharing the internal version?

msx-solis, 2023-12-06:
@dude22072 yes, but I need time enough to do it.
send me an email to have the gerbers, please.

atssada, 2024-06-15:
> @dude22072 yes, but I need time enough to do it. send me an email to have the gerbers, please.

Can I have the gerbers, i would like to have internal fdd.

atssada@gmail.com

Best,
Kim.

Pax-nl, 2025-01-31:
@msx-solis is your internal option still email only, or already publicly available?

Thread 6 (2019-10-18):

Possible MSX2+ upgrade option

Wierzbowsky, 2019-10-18:
As you offer v9958 installation, it could be good to offer an upgrade option to MSX2+. This will require port F4 and FM-PAC mono functionality. The FM-FAC SRAM option could be skipped. And you need a new BIOS and SubROM from a known MSX2+.

skiselev, 2019-10-18:
OPLL YM2413 is not a standard equipment of MSX2+ machines, although many (most) did have it.
As I wrote in https://github.com/skiselev/omega/issues/4, I'll consider adding it for the future versions
F4 port - at this stage would require major changes: An additional SPLD pin chip select, R/W decode, D flip-flop to store the value and a three-state buffer to read it back. Again, that goes on the wish list for the next revision.

skiselev, 2019-10-23:
I have an idea how to enable 0xF4 port without major changes. I can use printer port bit D7 to store the value, and use one of currently unused 74*125 3-state buffers to read it back.
In this case I'll program the SPLD so that it will generate /PRT_DAT_WR on both printer port 0x91 and 0xF4 writes. And to generate /PRT_BSY_RD on both printer status port 0x90 and 0xF4 reads.
The implications are: printer port values will be changed when 0xF4 port is written. It shouldn't affect the printer, but might affect Covox, and other devices that use printer port without using /STROBE to qualify the output. Also, when reading printer status back, it will return printer port bit D7. But that shouldn't really matter, because in any case only bit D1 is defined when reading port 0x90.
Do you know at what condition (and when exactly 0xF4) is being written?

msx-solis, 2020-03-02:
https://www.msx.org/forum/msx-talk/hardware/fooling-f4-register

skiselev, 2020-03-02:
> https://www.msx.org/forum/msx-talk/hardware/fooling-f4-register

Well, that's what I did (even before reading that post). It is interesting though if the MSX2+ BIOS boot gets stuck because of the lack of F4 register or something else (e.g. looking for memory mapper in Slot 3-0). I guess, it is a time for little disassembly exercise 😸

msx-solis, 2020-03-02:
👏👏👏👏

El lun., 2 mar. 2020 a las 23:09, Sergey Kiselev (<notifications@github.com>)
escribió:

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

sdsnatcher, 2020-09-10:
> Well, that's what I did (even before reading that post). It is interesting though if the MSX2+ BIOS boot gets stuck because of the lack of F4 register or something else (e.g. looking for memory mapper in Slot 3-0). I guess, it is a time for little disassembly exercise 😸

It's probably stuck looking for the subROM on the subslot 3-1. By default, you need to place the subROM on that specific slot on the MSX2+, or modify the BIOS if you place it on another slot.

msx-solis, 2020-09-10:
Placing the expanded RAM on the subslot 3-1 is quite easy on the omega, I was modifying to 3-0 just for entertaiment and its easy to test with 3-1, just changing one of the .jed files.
I would do it, if that helps

sdsnatcher, 2020-09-10:
It's not the RAM that goes on subslot 3-1, but the subROM+optROM.    :)

The default MSX2+ slot mapping goes like this:

- mainROM: slot 0-0
- mainRAM: slot 3-0
- subROM: slot 3-1, 0000h~3FFFh
- optROM with bootlogo: slot 3-1, 4000h~BFFFh

The bootlogo can be combined with some other ROM on the same slot. Usually it's the KanjiDriver, but it can be the MSX-Music BIOS or even just the standalone bootlogo code.

skiselev, 2020-09-10:
Do we still have this issue? As far as I know Omega boots nicely with MSX2+ BIOS. The bug was (and it was fixed a while ago) that only addresses 0x0000-0x3FFF of the subROM were mapped to the CPU (at it is done on MSX2). Current SPLD configuration maps the entire 0x0000-0xFFFF range.

sdsnatcher, 2020-09-10:
Suggestion: If you replace U27 with a 74HCT573, the bit D6 can be used to implement the MSX2+ I/O port F4h without the issue of conflicting with the parallel port, and will also allow the parallel port assembly to be supressed in the future.

The BIOS will only have to be patched to mask out the other bits when reading.

The remaining unused data bits can have their output side connected to a pin header and be used to activate other things on the future, like a turbo and even some of the higher bits of the I/O port F5h.

sdsnatcher, 2020-09-10:
> Do we still have this issue? As far as I know Omega boots nicely with MSX2+ BIOS.

Humm. I wasn't aware of that. I was fooled by the fact that the project description still states that "This project is an open source implementation of an MSX2 compatible computer."      :)

skiselev, 2020-09-10:
Well, this feature request talks about 0xF4 register and FM-PAC, neither of which are implemented in Omega... Although technically the MSX2+ BIOS works without 0xF4 register, and MSX-MUSIC is not a required MSX2+ feature ;-)
And so I left it open so that we can consider adding these features in the next major revision.

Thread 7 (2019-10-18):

Stop button location and size

Wierzbowsky, 2019-10-18:
On most of MSX computers the Stop button is large and is located in the upper right corner of the keyboard. In your design the Stop button is indistinguishable from surrounding buttons, which is not good.

I would recommend to put the Stop button in the top right corner if you don't want to change the design of the PCB.

Also where is the Select button? I can see only Ins, Del, Home and Stop buttons.

skiselev, 2019-10-18:
For the ease of construction I use inexpensive and readily available PC 104-key keyboard keycaps. And so I won't be able to change the button size (PC keyboards simply don't have a similar large key).
I can consider moving keys around, but I am worrying that a shape of the keycaps will be an issue. At least the keycaps that I use have slightly different curvature depending on the row.

LEDs are located under Caps and Kana/Run keys respectively. Multiple options to make these LEDs visible:
1. Use "backlight" type of keycaps
2. Drill a small hole in the keycap so that the LED will be visible
3. Use brighter while, blue, or "true green" LEDs that will be visible in between the keycaps.

sdsnatcher, 2019-10-19:
The Panasonic MSX2/2+/TR machines have STOP keys at a normal size, at the top center of the keyboard. Sanyo machines have STOP keys with the same size as the other keys. Same deal for Sony.

Personally, I don't find it important to have an oversized STOP key.

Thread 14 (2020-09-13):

Minor suggestion - Mouser BOM no longer accurate

billlagr, 2020-09-13:
Hi,
This is a really minor thing, but the BOM on Mouser is no longer correct - there's some obsolete parts, and also a large number of parts have had their minimum order quantity changed to 200! (eg resistors). The list may have to be updated with substitute parts.

skiselev, 2020-09-14:
Thanks for your feedback. I'll update the resistor part numbers in the BOM likely using Yageo parts (such as https://www.mouser.com/ProductDetail/603-MFR-25FRF5220K), although any other 1/4W resistors can be used. The only out of stock, obsolete part is the trimmer capacitor. It can be replaced with a regular ceramic capacitor (see BOM for the part number), or it can be purchased elsewhere.

elosha, 2021-07-28:
@skiselev
• Could you please add alternate transistors/diode types for EU parts in the BOM, like maybe PN2907A –> BC327?
• Furthermore the relais G5V-1-T90-DC5 is a high temp part that is often isn't available, while the basic G5V-1-DC5 is more common.

Thank you :)

skiselev, 2021-07-28:
@billlagr
Apologies for a long delay. I've updated the resistors and resistor arrays part numbers to ones that are normally available in single quantities from Mouser

@elosha
I've added the G5V-1-DC5 relay part number to the BOM. Thank you!
Regarding the transistors, PN2907A is an extremely common part, likely the most common PNP transistor. There is no longer European vs US parts... [Everything is made in Taiwan (c)](https://www.youtube.com/watch?v=bifOI4MbHVU) by ON Semiconductor... :)  BC327 has a different pinout - emitter and collector are switched. Otherwise the specs are pretty similar, so if you're inclined so, you can use these transistors

Closed 2021-07-28.

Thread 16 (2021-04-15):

Safe substitution of 74AHCT with 74LS logic devices?

elosha, 2021-04-15:
I‘ve read the docs, they suggest the 74AHCT logic family*, but say that 74LS logic could work, while untested.

74LS devices still are widespread among tinkerers. I have a whole box of them, too. And we are building a 4MHz machine. 😉

* Has anyone tried 74LS in meanwhile?

* Which areas of the board are safe to use LS, which are not?

* I would like to learn: Why are the cartridge slot drivers so speed dependent that they even require 74F logic?

Thanks 😊

skiselev, 2021-04-15:
One person reported building the omega using mostly using 74LS logic, and it worked fine.
* You can use 74LS instead of 74F. The choice of 74F was not related to the speed (although, it doesn't hurt), but to the ability of 74F to sink more current, which is useful in the bus driver applications. Also, new 74F tend to cost less than 74LS
* PAL clock generator (U43) must use 74HCT04. That is if you need PAL clock.
* The sub-slot select logic (U38, U40) is more speed sensitive than other parts, so if possible, I'd recommend using 74AHCT32 for U38, or at least 74F32/74ALS32
* Keep in mind that using 74LS instead of 74HCT/74AHCT will increase the power consumption, so you might need a power supply rated for more current - 5V/3A or more

Closed 2021-04-15.

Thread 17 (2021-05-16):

Does Omega support MSX-AUDIO (Y8950)?

denjhang, 2021-05-16:
Does Omega support MSX-AUDIO (Y8950)?

skiselev, 2021-05-17:
It should work with an MSX-Audio cartridge. I am unsure if it needs +12V/-12V. If it does, you might need to install a DC-DC convertor

skiselev, 2021-05-18:
Martin Lukasek documented building a +12V/-12V DC-DC adapter here:
https://www.8bity.cz/2020/power-module-12v-for-omega-home-computer/

Closed 2021-06-21.

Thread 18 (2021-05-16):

Carnivore2 multifunction card support

Sch-LikA, 2021-05-16:
Hi !

I am super interested in building myself an Omega computer, it looks amazing, thanks for the hard work !

I came accross the [Carnivore2](https://github.com/RBSC/Carnivore2) open-source multifunction card : CF support, RAM extension, FlashROM, multi-sound chips emulation, ...

Has anyone tested it on the Omega ? Does it work OK ?

Thanks !

skiselev, 2021-05-17:
Yes, Omega has been tested with Carnivore2 cartridge. It works great!
Note that it requires a DC-DC converter to produce +12V/-12V voltages that audio amplifier in Carnivore2 uses.

Sch-LikA, 2021-05-18:
Amazing !! Thanks for the answer. I'll definitively build one !

serge-intel, 2021-05-18:
Martin Lukasek documented building +12V/-12V DC-DC converter here:
https://www.8bity.cz/2020/power-module-12v-for-omega-home-computer/
Also here is his post on using Carnivore2 with Omega Home Computer:
https://www.8bity.cz/2020/carnivore2-compact-flash-vce-pameti-a-lep-zvuk-pro-msx/

skiselev, 2021-05-18:
Martin Lukasek documented building a +12V/-12V DC-DC adapter here:
https://www.8bity.cz/2020/power-module-12v-for-omega-home-computer/
Also, here is his blog post about Carnivore2:
https://www.8bity.cz/2020/carnivore2-compact-flash-vce-pameti-a-lep-zvuk-pro-msx/

Sch-LikA, 2021-08-31:
Cool thanks for the info !

Closed 2021-05-18.

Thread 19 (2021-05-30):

After I assembled the Omega MSX2, I found that the image kept flickering.

denjhang, 2021-05-30:
Can you help me find the problem? The image of my Omega MSX2 is not displayed properly, which is reflected as a fast flicker. At present, I only inserted a small number of ICs, such as Z80, 82C55, VDP, ROM, RAM, VRAM, and a small number of 7400 chips, just to narrow the scope of the problem. I tested all the clocks and found them to be normal.
I use composite output, and use NTSC's V9938, currently I press 82C55 with my hand, the image will change. When I press the VDP with my hand, the image will also change.
Maybe it is the problematic IC? Or maybe my IC socket is in poor contact with the IC?

denjhang, 2021-05-30:
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

denjhang, 2021-05-30:
I have found the problem, maybe the CPU socket has a bad connection, and my Omega can work normally at the moment.

denjhang, 2021-06-04:
It's actually a power issue. When I replaced a more powerful power supply and fixed some welding errors, the problem was completely resolved.

Closed 2021-06-21.

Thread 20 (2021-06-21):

LS vs HCT

NuClear235, 2021-06-21:
Orginal design was complete 74LS chips. Now are some replaced by 74HCT chips.
Is it OK mix it so? Could not I wait problems?
Would not be best use all just all 74HCTs?
(Except special F and other exceptions)

skiselev, 2021-06-21:
74LS was the best (higher speed/lower power consumption) logic family available back in early 80's when MSX was originally designed. 74HC/74HCT are slightly newer and they use fairly fast, and very low power CMOS technology. So I prefer using it in my designs.
Generally 74LS and 74HCT have comparable parameters and in most cases can be used interchangeably (but not 74HC, which is not TTL compatible).
Omega uses 74F for driving slot signals, as this logic family is fast and can drive higher loads. You could use 74HCT instead. Omega also uses a single 74LS07 open collector driver. That part is not available in 74HCT series.

Closed 2021-06-21.

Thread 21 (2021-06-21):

About C68,C69 and C70

Bobitsme, 2021-06-21:
Hi. 20 years ago, i owned of a NMS8250+FM pac and many disk and catridges. I keep good memory of time passed on it and happy to (try to) make a new one. So, really thank you for sharing your work.
I have a question about C68, C69 and C70:
On the bill of materials, you wrote that they are 10uF MLCC (not polarized). I have seen on this [website](https://msxmakers.design.blog/proyectos/omega-home-computer/omega-paso-a-paso/) that he put polarized capa.
I owned a 1.4 PCB. I trust you more than this website but i'm a bit uncertain :)

I have avoided a disaster with mine 2N2907 who have emitter and collector reversed compared to PN2907... my fault to use old component.

Thanks.

skiselev, 2021-06-21:
You can use either non-polarized ceramic (MLCC) caps, or polarized tantalum or aluminum electrolytic capacitors. If using polarized caps, make sure to observe their polarity.

Closed 2021-06-21.

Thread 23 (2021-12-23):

Key caps

alex3331, 2021-12-23:
Can you please advise on how to get keycaps and how to label them?
Thanks

skiselev, 2021-12-23:
Omega uses standard 102 key keyboard keycaps, for example, like these: https://www.amazon.com/Tecware-Keycaps-Double-Shot-Mechanical-Keyboards/dp/B08N6F23YT

Bobitsme, 2021-12-23:
I have boughted this keyboard : [https://www.banggood.com/fr/BAJEAL-K300-87-Keys-Mechanical-Keyboard-USB-Wired-Hot-Swappable-Blue-Swtich-Colorful-LED-Backlight-Gaming-Keyboard-for-Gaming-Typing-Offi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](url)
and this kit for the stabilizer : [https://www.ebay.fr/itm/233841619481](url)

Closed 2021-12-24.

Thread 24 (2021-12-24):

Power supply issues

merlinkv, 2021-12-24:
Hi Sergey.

First of all, I'm an enthusiast of your project. Thank you very much for your work.

I have an 1.4EU board and then I have made two versions of that board myself.

The fact is that **with all of them I have the same power issue**.

For my tests I use a regulated laboratory PSU.

Without added cartridges or modules the Omega boot perfectly at +5.2v, never at +5.0v. But if I put the 4MB RAM upgrade or use cartridges like Carnivore 2, MegaFlashROM or TDC-600, the only way to get it to work properly is with 5.47v / 5.50v.

It does not matter if I use a current of 3A, 3.5A, 4A or 5A ... the result is always the same. If I want to use the RAM expansion and cartridges, the only way is with 5.47v/5.5v.

- No heated components
- All TTL are HCT
- All solders are good and I checked them with a microscope
- All IC's and components are from good sources (not from China).
- All electrolytic capacitors are low ESR and high frequency
- No short-circuits

Link to my board: https://github.com/merlinkv/Omega_MSX2

Any idea?

Any help will be much appreciated.

Thanks

skiselev, 2021-12-24:
Well, there's a significant voltage drop somewhere in the system... I am not sure if it just happens because one of the components is faulty, the PCB routing changes, or added peripheral boards.

With the original Omega, similar issue was reported in two cases:

1. When using Rookie Drive or similar with some USB Floppy drives. This is resolved by adding an electrolytic capacitor close to the USB connector
2. When using faulty ICs, the RTC specifically if I recall correctly.

You can try to troubleshoot by measuring the voltage across power pins of different ICs on the system, starting from ones closer to the power connector, and going away from it.

Also you can try using another type of U46 voltage supervisor. Some types, such as ADM693A, have slightly larger tolerance to power supply voltage (minimum of 4.4V instead of 4.65V)

merlinkv, 2021-12-25:
Hi Sergey.

Thanks for your answer.

I have made some changes in tracks and vias.

- Default Track -> Clearance 0.25mm, Track 0.3mm, Via size 0.6mm, Via drill 0.35mm
- GND -> Clearance 0.3mm, Track 0.4mm, Via size 0.7mm, Via drill 0.35mm
- Power (+5v) -> Clearance 0.3mm, Track 1.6mm, Via size 1.6mm, Via drill 0.5mm
- Power2 (+12v y -12v) -> Clearance 0.3mm, Track 1.3mm, Via size 1.3mm, Via drill 0.5mm
- VidAudOut -> Clearance 0.3mm, Track 0.6mm, Via size 0.7mm, Via drill 0.35mm

I you want to see I have uploaded some pictures with the new design: https://github.com/merlinkv/Omega_MSX2

skiselev, 2022-01-04:
A couple comments:
1. Seems to be a loop in the VCC trace on the back layer. Loops in power supply traces is not the best thing.
2. The ground fill patches on top and bottom layers are not well connected. Add more vias to connect between them. This will provide better power supply stability across the board.

merlinkv, 2022-01-14:
Hi Sergey.

First of all, sorry for the delay to answer.

Thanks for your reply. I have mode some changes, now there is not VCC loop and the GND layers have a better connection.

- https://github.com/merlinkv/Omega_MSX2/blob/main/OmegaMB_1_2_5_MKV_VCC.jpg
- https://github.com/merlinkv/Omega_MSX2/blob/main/OmegaMB_1_2_5_MKV_Routed.jpg

Board is tested working with F4-FMPAC & o4Mega (4MB RAM) modules, internal Gotek with LCD 16x2, cartridges Carnivore 2 & TDC-600 (floppy controller) at the same time with one 5.2v/3A PSU.

skiselev, 2022-01-14:
Good to hear it works now!

Closed 2022-01-14.

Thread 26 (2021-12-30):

PCB Boards

alex3331, 2021-12-30:
I am planning to order 5 each of PCB for mainboard and keyboard from JLCPCB.  I only need 2 of each. Is anybody interested in purchasing the rest? I am in Massachusetts, US.
Thanks

skiselev, 2021-12-30:
I still have a few. Maybe it will be more price effective to get them from me... Faster for sure... I am located in Oregon
https://www.tindie.com/products/weird/omega-home-computer-pcbs/

Closed 2022-01-04.

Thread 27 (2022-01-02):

HC vs HCT vs AHCT

alex3331, 2022-01-02:
I noticed that some of the logic IC's are AHCT and some HCT. Is there any reason behind this? I have plenty HC and HCT but will have to buy AHCT (although I understand it is not a lot of money )

skiselev, 2022-01-02:
You can use 74HCT ICs instead of 74AHCT. They are slower, but Omega is slow enough, and the speed difference doesn't matter. I wouldn't recommend using 74HC ICs, since their input levels are not TTL compatible. They will work though, if their inputs are connected to CMOS outputs, e.g., those of 74HCT, 74AHCT, 74HC, 82C55, Z84C00... They might misbehave if the inputs are connected to TTL or NMOS ICs or MSX slots, as they generally use TTL levels.
In the documentation I refer to 74AHCT because they tend to be more available and cheaper.
By the way, you can even use 74LS, or NMOS Z80 and 8255, but they consume more power...

alex3331, 2022-01-02:
Thanks!
Another question I have is regarding keys. I ordered 73 keys instead of 72,
because the space key (higher force) is not available now. Can I make such
a replacement?
Thanks
Alex

On Sun, Jan 2, 2022 at 5:30 PM Sergey Kiselev ***@***.***>
wrote:

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

--
Alex Shakhnovich

skiselev, 2022-01-02:
Yes, you can use regular Cherry MX switch for the space bar. It just would be a bit easier to press...

Closed 2022-01-04.

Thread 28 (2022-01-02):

What size are the PCB?

ironardin, 2022-01-02:
Just to double check/for reference, what size are the PCBs? JLCPCB etc. ask for this.

skiselev, 2022-01-02:
The mainboard size is 333.4 mm * 149.9 mm
The keyboard size is 333.4 mm * 124.5 mm

You can always open the PCB layout file in KiCad, or open Gerber files in a Gerber viewer and measure the dimensions there

Closed 2022-01-02.

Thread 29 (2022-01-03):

Diode D1 is a resistor on the Mainboard Bill of Materials

ironardin, 2022-01-03:
Diode D1 (1N4148) links to 603-MFR-25FBF52-75R on Mouser, a Metal-Film resistor, the same as R43-R48. I assume this is a mistake?

skiselev, 2022-01-04:
Thanks for reporting it. Looks like copy and paste error ;)
Fixed

Closed 2022-01-04.

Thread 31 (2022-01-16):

ROM content

alex3331, 2022-01-16:
Where can I find an image for U6 (SST39SF040)?

skiselev, 2022-01-17:
You can use make_roms.sh script here: https://github.com/skiselev/omega/tree/master/BIOSto generate ROM images. It generates several images, I use omega_msx2_msx2+_ntsc.bin on my NTSC system.
The script uses ROMs from original MSX systems. You'll need to find and download them from the internet. I don't post them in there repository for copyright reasons

alex3331, 2022-01-17:
I will find the ROMs, what should I look for?

On Sun, Jan 16, 2022 at 8:42 PM Sergey Kiselev ***@***.***>
wrote:

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
--
Alex Shakhnovich

alex3331, 2022-01-17:
There are plenty of them on the Web. - can you please point me to a website?

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

--
Alex Shakhnovich

skiselev, 2022-01-17:
The NTSC MSX2/MSX2+ images uses the following ROMs:
phc-23jb_basic-bios2.rom
phc-23jb_msx2sub.rom
phc-35j_basic-bios2p.rom
phc-35j_msx2psub.rom
phc-35j_kanjibasic.rom

alex3331, 2022-01-17:
thanks. got these five.

On Sun, Jan 16, 2022 at 9:08 PM Sergey Kiselev ***@***.***>
wrote:

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

--
Alex Shakhnovich

alex3331, 2022-01-18:
I am not able to execute bash command on my Windows computer. Is there an
alternative way of composing these roms into 512 K image?
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

--
Alex Shakhnovich

alex3331, 2022-01-18:
Thank you. I actually ran it on LINUX machine and generated the package
(CBIOS 0.29). However, I can't find assembled 512 k image - just the 16 k
and 32 k pieces. Thanks, anyway.

On Tue, Jan 18, 2022 at 11:20 AM Sergey Kiselev ***@***.***>
wrote:

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

--
Alex Shakhnovich

skiselev, 2022-01-18:
That's weird. Check the script. It expects to find the source ROM images in certain directories/folders. And it doesn't have a really good error handling :)

alex3331, 2022-01-18:
Agree
I could not find a single 512 K image - let me look again at this folder.

On Tue, Jan 18, 2022 at 11:44 AM Sergey Kiselev ***@***.***>
wrote:

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

--
Alex Shakhnovich

elosha, 2022-10-30:
I agree to @alex3331:

After running make_roms.sh with all required scripts, I end up with these files – please note the sizes:
```
-rwx------  1 user  staff  884736 30 Okt 19:43 omega_msx2+_int_ntsc.bin
-rwx------  1 user  staff  901120 30 Okt 19:43 omega_msx2+_ntsc.bin
-rwx------  1 user  staff  950272 30 Okt 19:43 omega_msx2_int_ntsc.bin
-rwx------  1 user  staff  917504 30 Okt 19:43 omega_msx2_msx2+_ntsc.bin
-rwx------  1 user  staff  933888 30 Okt 19:43 omega_msx2_ntsc.bin
-rwx------  1 user  staff  933888 30 Okt 19:43 omega_msx2_pal.bin
```
So none of them fits into my SST39SF020 (256KB)

What am I doing wrong?

Also I noticed @msx-solis' repo here:
https://github.com/msx-solis/OMEGA_MSX_BIOS
His script produces different sizes, still everything is bigger than my Flash ROM. 💇

msx-solis, 2022-11-01:
Hi,
the size of your files should be 512K, the correct size to burn a SST39SF040, if not, you should check each file introduced to the script, if they are not in the route expected or they have an unexpected size the result will fail.
maybe you can do a file for your 39SF020 and maybe it could work but you should check each IC pin to do it.
If you follow that instructions you may understand what does it do and maybe get success:
https://msxmakers.design.blog/proyectos/omega-home-computer/omega-paso-a-paso/cocinando-la-rom-del-omega/

skiselev, 2023-01-06:
@elosha were you able to generate the proper ROM image?

elosha, 2023-01-06:
@skiselev Yes, finally had some spare time again, followed the ROM cooking manual from @msx-solis (easy with school-level spanish) and smacked the ROM parts together.

Hardest part was to understand why there is no MSX2+ PAL ROM, why I don't need one and that it shouldn't distract me. 😅

Actually the included ready-made file "256k_msx2_int_pal_fm.bin" should fit most EU needs I guess.

elosha, 2023-01-08:
Thanks for further clarification 😃 Very helpful. Wasn't kidding, just staying with MSX2 for simplicity reasons (few MSX2+ exclusive titles anyway) and might play with firmware later, after the hardware is fully working. 🤧

Closed 2023-06-28.

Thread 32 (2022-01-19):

Is switch 53 illuminated

alex3331, 2022-01-19:
D3 LED is mounted underneath SW53 (CODE/KANA) - what is switch part # for this key?

skiselev, 2022-01-19:
It a usual Cherry MX switch, combined with a **flangeless** 3 mm LED.
The LED part numbers are given in the [Bill of Materials](https://github.com/skiselev/omega/blob/master/Keyboard.md#bill-of-materials---version-10)
It appears that the yellow LEDs (part number VAOL-3HCE4) are no longer available. It can be substituted for red/green/blue/white or any other colors you like

alex3331, 2022-01-19:
I still do not understand. This LED (D3) is right underneath SW53  and the
switch is black and non transparent-  please see attached photo

On Wed, Jan 19, 2022 at 11:01 AM Sergey Kiselev ***@***.***>
wrote:

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

--
Alex Shakhnovich

elosha, 2022-01-19:
@alex3331 You should choose a Switch cap that supports a LED, like some Num Lock keys do.

@skiselev Kingbright (and TT Electronics at Digikey) seem to still manufacture flangeless. I've searched for T1 (3mm) + 3mm outer diameter.

skiselev, 2022-01-20:
@elosha thank you for this information. Do you happen to have the part numbers?

elosha, 2022-04-14:
@skiselev It seems the LEDs I found were not entirely flangeless, but at least barely measurable, adding only 0.5mm outer diameter. In my keyboard I used those and they fit, because the switches have a little vertical gap at the bottom where the LED mounts.

Closed 2023-01-06.

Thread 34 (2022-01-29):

No video

alex3331, 2022-01-29:
Turned on the first time; no RGB video on pins 22, 23, 24   of VDP
With the scope:

Synchro  (pins 5, 6) - normal
CPU clock  (pin 8 ) - normal
CPU is listing addresses

V9958 - pins 22,23 and 24 - 2.2 volts, no pulses.
Any way to diagnose?
Thanks

skiselev, 2022-01-29:
It might be not VDP related at all.
The MSX BIOS will not produce any video if RAM or RTC are not working.
I can recommend trying C-BIOS image first, which will produce video output even without working RAM and RTC

alex3331, 2022-01-29:
Thanks, can you give me a reference for the image?

On Sat, Jan 29, 2022 at 2:27 PM Sergey Kiselev ***@***.***>
wrote:

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
--
Alex Shakhnovich

alex3331, 2022-01-30:
I am using RGBS-VGA and RGBS-HDMI  converters (negative CSYNC)  with all my retros; Omega J5 RGB socket does not  seem to have S pin. How is synchronization arranged on J5?
Can I get synchro  from VDP pin 6 (CSYNC)  inverted by  U43C (Q2 installed)? The scope shows correct timing and polarity. I looked at CXA1645 datasheet and it does not mix in SYNC with RGB outputs.

skiselev, 2022-01-30:
I might be mistaken, since I haven't used my Omega with RGB, but I think RGB monitors, at least with SCART, use Composte signal for synchronization

alex3331, 2022-01-30:
You mean Composite Video or Composite Synchro? Composite Synchro is working OK. Will start checking soldering; as well as checking signals with scope.

Sent from my iPad

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

alex3331, 2022-01-30:
Computer works OK (changed processor) with CBIOS and regular  BIOS. Video
is horrible. It does not want to talk to my adapters. I need to figure out
how to connect it to LCD monitor. Both my adapters so far do not work with
OMEGA RGB output. How do people connect it?
Alex

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

--
Alex Shakhnovich

skiselev, 2022-01-31:
I personally use S-Video. Composite video also works for me, although with lower quality.
Several people reported success with using RGB monitors or TVs with SCART connector (common in Europe). In the latter case, the connector provides RGB and composite video, and the TV/monitor extracts synchronization information from the composite video signal.
There are a few, not particularly expensive S-Video to HDMI converters on Amazon, such as this one: https://www.amazon.com/Converter-Composite-Adapter-Support-Blue-Ray/dp/B07GVDWGK8/
Maybe give it a try? (and return of it doesn't work)

alex3331, 2022-01-31:
I sure will. Let me play with the scope a bit more. I have seen somebody
taking RGB from 9929 and adding a 2N2907 transistor amplifier to each
channel to bring it to TTL level. I have the PCB already so may try.

On Mon, Jan 31, 2022 at 12:50 PM Sergey Kiselev ***@***.***>
wrote:

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
--
Alex Shakhnovich

skiselev, 2022-01-31:
Analog RGB voltage is normally much lower than 5V. For example, VGA ranges from 0V (black/no color component) to 0.7V (white/full intensity).
CGA and EGA used 5V TTL digital signal, but I assume that's not what you want.

cristianoag, 2022-02-28:
I'm using mine with RGB currently, but I noticed it is super sensible to the power source. I have multiple 5V power supplies, including my bench device and I only manage to make RGB work with one of the power supplies. I didn't check with scope yet, but that is strange. While it works ok in S-Video and Composite with any 5V power source, RGB only works within specific parameters.

alex3331, 2022-02-28:
After I fixed my VDP issue RGB works fine for me. I use cheap RGBtoVGA
adapter based on 8220 chip. The board is $25 on Amazon. Power supply is a
cheap 5 v 2.5 a. If everything is OK, Omega does not pull a lot of current

On Mon, Feb 28, 2022 at 8:41 AM Cristiano Goncalves <
***@***.***> wrote:

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
--
Alex Shakhnovich

cristianoag, 2022-02-28:
What was the issue with your VDP?

alex3331, 2022-02-28:
As it turned out, VDP was fine ; two RAM pins were bent, so VDP did not
initialize properly. Now I have an extra chip which is tested and working.

On Mon, Feb 28, 2022 at 10:44 AM Cristiano Goncalves <
***@***.***> wrote:

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
--
Alex Shakhnovich

Closed 2023-01-06.

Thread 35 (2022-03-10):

Hardware switch & HDMI

EMLommers, 2022-03-10:
Hi,

This is the best successor of MSX, I have seen!
No emulation, but real Zilog inside, much better than FPGA, ARM or whatsever.
If there is a possibility to have a hardware switch to select MSX 1/2/2+/tR, (incl. button R800 on/off, maybe for the suckers like me an additional switch for 7Mhz, MSX Music) with flashable ROMs for each type and a HDMI output,
there is no possibility to deny this... and really a wanna have!..

I know it is not easy.. but possible!

Emulation never achieves 100% accuracy! Everyone wants only the real thing!

skiselev, 2022-03-10:
Thanks for your feedback!

A few thoughts:

- Switching between MSX1/2/2+ is practically impossible. The defining difference between MSX1, MSX2, and MSX2+ is the VDP type - TMS9918, V9938, and V9958 respectively. To make a switch, the board would have to have all three VDPs and somehow switch between them. There are other, less significant differences too - BIOS/BASIC (there is an option to load two BIOS images right now, and easily switch between them - that might work as switch between MSX2 and MSX2+ BIOSes), memory mapper in MSX2 (but also present in some MSX1), F4 port in MSX 2+ (no one seems to care about), but these tend to be backward compatible
- Turbo R uses R800 CPU. Good luck finding one, and also soldering SMD components is a problem for many people
- Turbo mode (7.159 MHz) on Z80 CPU might be possible. It is on my list of possible enhancements for the next version
- HDMI output is likely no go, unless there is a reasonably small and affordable RGB to HDMI converter module that can be installed on the PCB.

EMLommers, 2022-03-15:
Hi Skiselev,

Thanks for your reply.
If there is an possilibity to use VGA to HDMI adapter (external) , would be  appreciated, due to currrent monitors, use vga /hdmi (some times scart)
I am used to run MSX2, with switch to 2+ and switch for 7Mhz. Running an MSX2 and able to access the VDP registers of V9958, would be excellent. 7Mhz is for me only used to check timings adressing VDP.
One last question,  possible to connect my old MSX drive to the board (or 2 like Phlips NMS8280 ??) To run original disk software.

What would be the estimated price when finished?

skiselev, 2023-01-06:
@EMLommers apologies for a very late reply

* MSX Turbo-R compatibility is out of the scope. As far as I can tell, it is not easy to implement it. Z380 does not seem to be a straight forward replacement for R800
* Some people do use 3-rd party RGB to HDMI adapters. Currently there are no plans to integrate one in the system. Also, supposedly, some monitors can use the RGB signal with NTSC timing directly if connected to VGA input
* I still don't understand switching between MSX2 and MSX2+... In Omega you can have both MSX2 and MSX2+ ROM images, and switch between two. I think V9958 is backward compatible with V9938, so that should work just fine. As I said previously, 7.159 MHz is on the list of possible enhancements for the next version
* Currently Omega does not have a built-in floppy disk controller. With that being said, it is on the list of possible enhancements for the next version. Also you can use a floppy disk controller cartridge, for example, FDC-600, [Rookie Drive](http://rookiedrive.com/en/home/), together with whatever floppy drives they support
* At this point I am not planning to remove printer port
* I cannot give you a price estimate. It depends where you get the parts, what case you use, and so on...

Closed 2023-01-06.

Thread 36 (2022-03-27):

Is there a way to run 128 K or larger rom files on Omega

alex3331, 2022-03-27:
It looks like slot address bus can address no more than 64 k. Is there a way to run larger programs without the need of another external storage device, like FD, SD card or hard drive?

skiselev, 2022-03-27:
The address bus is 16-bit, so the addressable memory is limited to 64 KB.
There are ways around this limitation, usually by "paging" the memory. MSX2 memory mapper, and MegaROMs are the examples of such approaches.

alex3331, 2022-03-27:
Can you please give  a reference to MegaROM and MSX2 memory mapper? I have a few 128 k, 256 k and 512 k programs and would like to try them

skiselev, 2023-01-06:
@alex3331 I believe I've provided you the information in the email.
Closing the issue

Closed 2023-01-06.

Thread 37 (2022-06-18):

HC vs HCT - BOM / Silkscreen mistmatch

rain2usa, 2022-06-18:
Good Evening.  I'm having a lot of trouble building the Omega.  I bought the quick kit from eBay with all LS chips but that didn't work so I bought everything as-is from the BOM as much as possible.  Anyways, I just read up on the differences between HC vs LS vs HCT stating HC isn't TTL compatible and shouldn't be used.  One of the BOM parts is asking for a regular HC IC.  Is this correct?

Integrated Circuit | U15 - U18 | 4-by-4 Register File - 74HC670, 16 pin DIP.

Silkscreen is asking for 74HCT670.  Could the difference be causing my "Error: Memory not found" screen no matter what IC I keep/pull?  GALs and Flash are programmed correctly.  Voltages are all good. The Smoke tests 1 - 3 from the MSX Makers guide seems to work. The Expected scoped frequencies in many places seems to match, but not the PPI_CS.  Can't get any frequency reading from the 82c55 (Pin 6) to the U12 (Chip Select Pin 14).  I get 4.7V on Pin 6 (U2), which I have been told may not be correct.
I listed all of my issues on the MSX Makers forum if it helps any to see what all I have done.  Any help would be appreciated.

skiselev, 2022-06-18:
74HC inputs are not compatible with 74LS outputs.
74HC inputs are compatible with 74HCT and other CMOS (e.g. GALs, Z84C00 CPU, 82C55 PPI) outputs.
Look at the schematic and check if you have any 74LS outputs going to 74HC inputs
I'll check the schematic later regarding your measurements

rain2usa, 2022-06-18:
Thank you for the quick reply. Ok, then the 670 is fine then.  All of the ICs are HC/HCT/ACHT ICs except the lone LS07.  The only HC IC is the 670 in my current configuration.  I'll wait for your review of the measurements and appreciate the help.  I just feel like I'm missing something and no one on the Makers Forum knows what that could be.  Just to reiterate from the Maker's Forum, I have a 1.4 revision board.

rain2usa, 2022-06-22:
Defective/Incompatible Mitsubishi 82c55 was the cause of the board issues.  Replaced with exact part number from BOM and it's working thus far.  Was unable to diagnose Why it was defective but it was also the last part in that part of the circuit that wasn't replaced until a couple days ago.

Closed 2022-06-22.

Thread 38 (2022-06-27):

Put Luma instead of CVBS on the pin-4 of the RGB connector

sdsnatcher, 2022-06-27:
The current revision of the OmegaMSX has CVBS (aka "Composite Video") on the pin-4 of the RGB connector.

But this is known to cause jailbars on the RGB image.

It's better to replace it with the Luma signal from the S-Video connector. This is a much better way to provide a cheap/clean CSYNC signal for that pin.

skiselev, 2023-01-05:
Sounds like a reasonable fix. Adding to the next version improvements

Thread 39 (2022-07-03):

Make Ys available on the RGB connector

sdsnatcher, 2022-07-03:
Please add the Ys signal to the RGB connector. The pin-5 of the DIN-8 MSX RGB connector was meant to be the Ys signal from the VDP.

To save some pennies on a transistor, many MSX models came with just a resistor divider connected to that pin.

But for those on the SCART world, it's very useful to have a funcional Ys pin, since the TV can superimpose the MSX image over other sources.

I attached here a screenshot of how it was implemented on the Philips NMS-8245.

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

sdsnatcher, 2022-07-03:
There are a lot of free inverters on the current Omega schematic, and any of them could also be used to implement the Ys signal too:

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

skiselev, 2022-07-03:
Thanks for the suggestion! I'll add it to the next revision.

Leshak-pcb, 2023-06-29:
> There are a lot of free inverters on the current Omega schematic, and any of them could also be used to implement the Ys signal too:
>
> 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

Since Ys is terminated with 75 Omh resistance this is probably too much for 74HCT04. Increasing series to 150 Omh results in 18.7 mA current - pretty high, but acceptable for 74HCT.
74ACT04 can source up to 24 mA, but is it suitable for a clock generator?

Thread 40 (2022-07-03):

Position C93 must be jumped if the optional PAL clock generator is not installed

sdsnatcher, 2022-07-03:
It's implicit in the schematic, but since most people won't know this, it's better to include a note there to explain that the position C93 must be jumped closed when the optional PAL clock generator isn't installed.

skiselev, 2023-01-05:
That would be the case only if U43 is installed, eg. using V9938 VDP. I'll add a note

skiselev, 2023-06-28:
Documented here: https://github.com/skiselev/omega/commit/fb3b31dc1fc799c4046cd5436b77a6c39a7dd5c3

Closed 2023-06-28.

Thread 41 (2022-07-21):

Any reason for JP7 and RR10 to exist?

sdsnatcher, 2022-07-21:
Is there any reason for JP7 and RR10 to exist? They only seem to be a source of trouble for those that I'm seeing to assemble the project.

Some of them cut the JP7 tracks open, causing mirroring of the 512KB of RAM to happen amongst the Memory Mapper pages. This is an unwanted behavior that causes some programs to incorrectly detect up to 4096KB of RAM from the 512KB RAM chip.

skiselev, 2023-01-05:
Yes, there is a reason. The previous revisions (1.1, 1.2) didn't have JP7, JP8, and RR10. This resulted in some poorly written software (Jordi/MSXMaker knows exactly which) to misdetect the memory size. If I recall correctly, the software relied on writing and reading back page register, which supposedly should wrap around when the top of the memory is reached. In case previous revisions, the page register has 8-bit, while only 5 bits are used on a 512 KB system. So we added these jumpers.
Perhaps I should document them better...

skiselev, 2023-01-05:
Some other software, detected the memory size by writing values to all 256 theoretical memory pages, and then reading the written values back, expecting that the values will be overwritten at some point, if the memory size is less than 4 MB. In case of the earlier Omega design, the writes above 512 KB (32 pages) simply disappear, which was causing issues.

skiselev, 2023-01-05:
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
This shows the "testmap.com" output that displays an error, before implementing the "fix". Generally speaking, the software shouldn't read the page register back and rely on its value... but it does...

Closed 2023-06-28.

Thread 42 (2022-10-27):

Which Programmer to buy?

CaffeinatedTech, 2022-10-27:
I can't seem to get hold of a minipro TL866II any more.  They are either out of stock, or quite expensive.

Can anyone suggest a currently available programmer which would be suitable for this project?

I've got an arduino mega if anyone can point me to a project to build a programmer.  I'm happy with that option too.

skiselev, 2022-10-27:
I think TL866II Plus and Xgecu are the later revisions of TL866 series
Check the programmers' device list for SST39SF040 and ATF16V8 support

CaffeinatedTech, 2022-10-28:
Looks like TL866II Plus was replaced by the XGecu T48, and the T56.  The T56 is more capable and faster, but is considerably more expensive.  So I'll try to get a T48.

Here's the [device list](http://www.xgecu.com/MiniPro/T48_List.txt) for anyone interested.  Both of the specified chips for this project are listed.

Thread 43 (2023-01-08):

Proposed box of various designs for MSX Omega

Mundo-Desconocido, 2023-01-08:
I have some conceptual proposals on 21st century case designs for the MSX Omega.

As a background, I helped the MEGA65 team for a year on some modifications to the computer case as well as some conceptual ideas for future versions.

I would be grateful if you could rate the different ideas I uploaded in the following thread.

Muchas gracias
Jose Luis
Mundo Desconocido
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

skiselev, 2023-01-12:
Jose Luis,

These designs look beautiful.
A few things of concern:
* I think the design assumes that the keyboard is housed separately from the computer. With the current computer design, it would require a 16-wire cable to communicate between the keyboard and the computer. It is possible that systems with separate keyboard design used a different approach that allowed reducing the number of wires. I'll have to check how easy that can be implemented
* Currently the slot connectors are stacked in the right corner of the motherboard. Moving them elsewhere would require redesigning the motherboard, or developing an extra board with the slot connectors. The particular "side by side" arrangement might be more problematic, as it will make more difficult to route the PCB traces
* Looks like the design includes places for floppy disk drives. I like that, although we need to come up with a way to connect them to the computer. Currently it would require using a controller in one of the cartridge slots. Adding a floppy disk controller is on my enhancements list. I don't quite understand what SSD is and why there is a bump in the case to accommodate it. Is it supposed to be a removable drive? I think most if not all SSDs have SATA interface, so it will be difficult to connect them to an MSX. It is more reasonable to connect an SD card or a USB-based storage devices
* I personally do not recommend using MSX anywhere in the labeling, as it is a registered trademark

Also, what is the goal of this case design? Are you planning to manufacture it eventually? Or would you publish the design files, e.g., 3D printable files (STL or similar)?

Thanks,
Sergey

Mundo-Desconocido, 2023-01-14:
>

Thank you very much for your indications and assessment.

This is just one of the conceptual ideas I have for the Omega, obviously, I will upload more in this thread as I have them designed, another one is about to come out of the oven.

Regarding the non-inclusion of the MSX logo, I will take it into account, it happened the same with MEGA, etc...

The purpose of the case that I design here, is to offer it for free to the community in a printable STL file or if this project wishes, to use it as a final capsule in injected plastic, if someone decides to market them, for my part, my only interest is the mere altruistic collaboration.

thanks
JL

Mundo-Desconocido, 2023-01-14:
This is a new concept.

It has shapes reminiscent of stealth forms and the colours are warm and classic, a strange mix that together with the blue and red stripes give it a modern and classic touch at the same time.

Remember that these are just sketches. Whichever one you choose, it will fit the shape of the motherboard.

Thanks for your feedback.
JL
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

nullvalue0, 2023-01-22:
I really like the idea of a separate keyboard and was thinking about doing my build like that. Since it requires a 16-pin cable, I was planning using an [ODB2 cable like this](https://www.ebay.com/itm/291181598660).

nullvalue0, 2023-01-25:
@Mundo-Desconocido I already have an enclosure that I am planning to use for my build for the motherboard but I would really love to get the STLs for the keyboard case in your first design. Not sure how much work that would be..

skiselev, 2023-01-27:
@Mundo-Desconocido that's an interesting concept and lovely colors! Is it possible to do the floppy part a separate module, pluggable into the computer? There might be some mechanical considerations there, as it would need to be secured, so it doesn't accidentally disconnects, or worse, breaks the connector

sallevan, 2023-03-21:
Sergey,

> I think the design assumes that the keyboard is housed separately from the computer. With the current computer design, it would require a 16-wire cable to communicate between the keyboard and the computer. It is possible that systems with separate keyboard design used a different approach that allowed reducing the number of wires. I'll have to check how easy that can be implemented

I have nice times in the school which has "KUVT "Yamaha" (КУВТ - комплект учебной вычислительной техники), where schoolchildren's computers were "all-in-a-keyboard" design (without FDDs) while teacher's one has main unit (with FDDs) **separate from keyboard.**
As such, I think that Yamaha, Inc. somehow resolved the issue with a bunch of keyboard wires those years. Unfortunately, I have no design/schematic files for such a variant. :(

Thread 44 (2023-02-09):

Possibility of adding a numeric keypad?

nullvalue0, 2023-02-09:
Looking at [this page](https://www.msx.org/wiki/Keyboard_Matrices#U.K._matrix_.28QWERTY_with_a_.22.C2.A3.22_key.29), it appears the numeric keypad resides at matrix ROW 9 & 10 (UK matrix format). I see in the keyboard schematic, on the 74LS145, Q9 is not hooked up which might get me one extra row, or half of the keypad keys. What might it take to fully support the keypad? (I'm thinking about designing an add-on PCB)

skiselev, 2023-03-10:
It would require changing the decoders. Perhaps similar to this: https://github.com/vipoo/yellow-msx-series-for-rc2014/blob/main/keyboard/schematic.png
The main reason I didn't implement numeric keypad is to keep the keyboard PCB size small. But, as you've mentioned, it is possible to add a connector for an optional numeric keypad board.
I'll keep this in mind for future redesigns.
Or, if you feel so inclined and you have a bit of time, perhaps you can take the schematic linked above, and modify the keyboard PCB layout accordingly, adding a connector with rows 9 and 10, and all columns 0 - 7 (so, 10 signals, perhaps using a 5x2 header?

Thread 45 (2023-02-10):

spacebar stabilizer part no is wrong

mrkite, 2023-02-10:
In the parts list for the keyboard, you list Mouser 540-G99-0226 for a "Leveling kit for MX 1x8".  That is the right description and part for a 1x8 stabilizer, but the spacebar used in the project is a 6.25u spacebar.

skiselev, 2023-02-10:
I know. Unfortunately, Mouser does not have a stabilizer for 6.25u spacebar.
I used a longer 8u stabilizer, bent and cut it to build a shorter one.
Perhaps this needs to be documented 😄

nullvalue0, 2023-02-11:
I just ordered them from here: https://www.aliexpress.us/item/2251832533420646.html

skiselev, 2023-03-10:
I've enquired Cherry US about ordering these parts. The part name and the number are: Wire yoke 6145017
They said that there is no official distributor that sells these parts.
Just in case, I'll shoot an email to Digi-Key and Mouser, and ask them if they want to stock that.

nullvalue0, 2023-03-10:
I can confirm the part I listed above from AliExpress fit perfectly for me.
I got the 7U 60 87 version. I know it might not sound right but it fit
without modification.

On Fri, Mar 10, 2023, 4:49 PM Sergey Kiselev ***@***.***>
wrote:

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

Closed 2023-03-10.

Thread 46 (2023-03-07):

Omega Keyboard is missing two keys to be JIS layout.

dude22072, 2023-03-07:
On JIS keyboards, both MSX and modern day, there are two extra keys compared to US QWERTY layout that are missing from the Omega Keyboard.
JIS Keyboards have three keys between L and Return, whereas US keyboards only have two.
Similarly there is an extra key between /? and right-shift, making a total of 4 keys between M and Shift.
Technically speaking the spacebar is also shorter to make room for 実行 and 取消 keys, but very few MSXes have these keys. They seem to only have been included on models that were marketed as word processors.
Since the Omega Mainboard has a jumper for JIS keyboard layout, I think the keyboard PCB should be updated to include these two extra keys.

skiselev, 2023-03-10:
How important are these keys? Is there any software that doesn't work without them?

Looks like it will require decoding all 4 rows (instead of just 3 in Omega keyboard).
It is doable. But will require keyboard redesign, perhaps similar to this: https://github.com/vipoo/yellow-msx-series-for-rc2014/blob/main/keyboard/schematic.png
Keyboard JIS keyboard matrix, for my own reference: https://www.msx.org/wiki/Keyboard_Matrices#JIS_Matrix

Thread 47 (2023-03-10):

Keyboard LEDs

peterw8102, 2023-03-10:
The keyboard has D2 and D3 as 3mm LEDs (through hole 3mm from the BOM). I can't see how these work with the MX Cherry Switches in the BOM. There's no room for the LED. I'm assuming I'm missing something? I thought I'd bought the right switches. Any help appreciated.

skiselev, 2023-03-10:
Hope this explains :)
You'll want to get a flangeless 3 mm LEDs. See the BOM for some suggested part numbers.
If for some reason your keys don't have a place to mount LED, perhaps you don't have the original Cherry MX switches?
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

peterw8102, 2023-03-10:
Brilliant, I do have the right switches and had completely missed those holes! Thank you!

Closed 2023-03-10.

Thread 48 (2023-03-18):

Could use some help debugging my cartridge slots..

nullvalue0, 2023-03-18:
I have my Omega computer built, and have gone through many tests - everything seems to be working except for booting a cartridge.. Screen, sound, joystick, even tested cassette and it's working perfectly (loaded Donkey Kong from a wav file, what a blast!)

But when I put in a cartridge the system just boots to MSX-BASIC. Voltages look correct. I've double-checked my slot select/dir GALs, the CS lines all seem to be operating.

Does this timing look correct? This is a boot-up from power off, with a cart in Slot 1.
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

[MSX Cart PV.zip](https://github.com/skiselev/omega/files/11009321/MSX.Cart.PV.zip)

Let me know if there are any other lines that would be more helpful from a logic analyzer perspective. Thanks!

nullvalue0, 2023-03-25:
I have resolved this. After extensive testing of all the address & data lines, I found there was no activity on my D0 and D2 lines. Followed the traces and found there was no connectivity between the cartridge port and the IC. It must be a couple of cracked traces, although I could not see any evidence of this. I ran a couple of bodge wires and I'm booting from cartridge now!

Closed 2023-03-25.

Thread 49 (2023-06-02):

Floppy disk interface TDC-600 clone Error.

drawingangnam, 2023-06-02:
I successfully assembled a floppy disk interface TDC-600 clone.
I connected to OMEGA and connected GoteK flash floppy to run the game.
However, while reading the file, it freezes on a black screen. (But interestingly, some games are running well.)
Gotek Floppy Action LED is on but OMEGA is stopped.
Some games have a start screen, but will stop after a while. Is it an MY Omega problem?
Or is it a TDC-600 clone issue?
The TDC-600 clone was tested by assembling two different production years WD37C65.

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
My  TDC-600 clone

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
"Fire Hawk"
logo comes out and reading the disc, and at the bottom of the page, there's a broken graphic like that and it stops.

merlinkv, 2023-06-03:
Hello,

As I can see, you only have the gotek connected. Try this:

- Set all jumpers UP
- Plain cable, set the Gotek as DS0
- Standard PC FDD cable: Connect the Gotek after the crossing cables and set it as DS1

drawingangnam, 2023-06-03:
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
Thank you for your interest. I've already tested everything you said.

I've done everything I can think of.

Jumper setting, cable related, firmware related…

It's still the same symptom.

I asked the community to test the person who made OMEGA before me.

I heard that there was a same problem when I used the all-in-one GoTek cartridge using WD37C65 PLCC-44.
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

He said THAT worked well at SONY MSX.

merlinkv, 2023-06-03:
I don't know ... but I have two TDC-600 clones (https://msxmakers.design.blog/proyectos/proyecto-tdc-600/) working like a charm with Gotek and real FDD's.

But I think is not a problem of the Omega or the TDC-600 controller. I have been tested this game (Fire Hawk) and have the same problem as you.

Maybe is a problem of bad cracked/dumped game? Becasue many MSX1/MSX2 games works perfectly.

drawingangnam, 2023-06-03:
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

Thank you for the test.

It runs well on my DAEWOO MSX with GOTEK that doesn't run on OMEGA. (Of course, the FDC is the DAEWOO MSX built-in interface.)

If possible, could you test it for me?

Psycho World
Ultima4
Snatcher
SD Snatcher
Ancient Ys Vanished II - The Final Chapter
Valis II - The Fantasm Soldier

merlinkv, 2023-06-03:
I have done some test with Gotek and real disks.

Psycho World -> NO
Ultima4 -> OK
Snatcher -> OK
SD Snatcher -> I can't test, I have SCC (Carnivore2) but ask for Sound Cartridge ... ??
Ancient Ys Vanished II - The Final Chapter -> NO
Valis II - The Fantasm Soldier -> OK

drawingangnam, 2023-06-03:
> I have done some test with Gotek and real disks.
>
> Psycho World -> NO Ultima4 -> OK Snatcher -> OK SD Snatcher -> I can't test, I have SCC (Carnivore2) but ask for Sound Cartridge ... ?? Ancient Ys Vanished II - The Final Chapter -> NO Valis II - The Fantasm Soldier -> OK

Thank you very much for the test.

But it's interesting.
These are all games that don't run on my OMEGA but some games run on your OMEGA!!

I'm really curious.
If it's caused by a mechanical defect, the same reaction should come out..

merlinkv, 2023-06-05:
Ancient Ys Vanished II - The Final Chapter (1988)(Falcom)(Disk 1 of 2)(Game Disk)[tr es Manuel Pazos].dsk
Ancient Ys Vanished II - The Final Chapter (1988)(Falcom)(Disk 2 of 2)(Game Disk)[tr es Manuel Pazos].dsk

Works fine.

drawingangnam, 2023-06-05:
> Psycho World [T-En by FRS v.1.0].dsk

Thank you for the TEST.
I downloaded the exact same file and tested it.

Ancient Ys Vanished II - The Final Chapter : Stop as soon as the step roll FIRTST LINE comes out

Psycho World [T-En by FRS v.1.0].dsk : START selected and the "LOADING" appears when the game is pressed

There is a high probability that my OMEGA has a problem.

Did you use a chip with the correct prefix?

AHCT138 -> F138
HCT670 -> HC670
HCT153 -> HC153

Except for this replacement, we used the exact chip.

Can this cause the problem?

merlinkv, 2023-06-05:
I'm not sure, but yes, that may be the problem.

I use chips with the exact nomenclature and with my own version of the motherboard (It's almost the same as the original 1.4EU, except that you can choose between 4 ROMs and it has some extra power connectors).

https://github.com/merlinkv/Omega_MSX2

drawingangnam, 2023-06-06:
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

I ordered new HCT chips.

I will replace the HC with HCT and report the results.

And

I'm thinking about build a new FDC that requires 2793.
(https://github.com/konkotgit/fdd-cdx2)

merlinkv, 2023-06-06:
Great!

I'll wait your tests.

drawingangnam, 2023-07-05:
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

HC670 -> HCT670
HCT245 -> F245
HC153 -> LS153 (Ori. HCT153)

I've tried this.

The problem has not been resolved.  ;'-(

FDD is freezing with the ACT LED on while loading the game.

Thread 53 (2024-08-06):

Bizarre signals with no video out

ProfsRetroFix, 2024-08-06:
Welp, as I don't have an MSX.org account I'm running out of places I can hopefully get a bit of guidance on this.

I'm trying to build an MSX Omega, and failing on smoking test 2 on [MSXMaker's step-by-step guide](https://msxmakers.design.blog/proyectos/omega-home-computer/omega-paso-a-paso/). Test one works with flying colours. However, test 2 doesn't give me a video signal. At all. No black screen, nothing. BIOS-wise at the moment, I'm using the one from the link, with a halt BIOS in the first have, and NTSC C-BIOS in the second. I don't think the NTSC BIOS should be the issue though, as the reason I flashed the halt BIOS ROM is because this was happening with the PAL BIOS too.

I've wired it for PAL (although if NTSC is easier, I might change it because this obviously isn't working), and the frequencies don't seem right. SCIN on the CXA1645P encoder doesn't look right either. It's just constantly at around 2.4v, no pulse.

I've attached some screenies from when I was taking some measurements. I'm hoping someone can lead me in the right direction here. This was a fun project up to this point, and now I want to throw it out the window. I've examined every solder joint, and they seem to be fine (although admittedly I haven't gone over them with a multimeter yet). I've built a retro chip tester pro from scratch though, and recapped a few machines, so hopefully my work isn't that bad.

In case of fake chips, I've already spent an extra €80 getting a couple of replacement CPUs and V9958's from UTSource. Doesn't seem to make a difference. I've got a couple of replacement CXA's coming just in case. Everything else is new from Digikey and Mouser.

Does anyone have any ideas of where I can go from here?

CSYNC on the VDP is reporting at 15.70 kHz. My oscilloscope can't seem to lock onto a frequency like it does for SYNCIN on the CXA later.
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

SCIN on the CXA1645P seems to be held at around 3.2v? Is this normal? I was under the impression it should be pulsing.
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

SYNCIN is showing at 16.235 kHz, the oscilloscope can lock in this time. But it's still not the PAL frequency. What's going on here?
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

zomgugoff, 2024-09-28:
Per the [CXA1645 datasheet](https://gamesx.com/rgbadd/cxa1645.pdf), SCIN should be a sine wave or pulse from 0.4-0.5 VP-P. I'm seeing the system clock coming in  at 3.58MHz on mine. Something is wrong there.

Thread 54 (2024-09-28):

Keyboard v1.1 ghosting

zomgugoff, 2024-09-28:
When typing "cd " quickly, the cursor moves to the beginning of the line. I believe this is the result of keyboard ghosting. There are no diodes running from each row->column junction to prevent it. The Yellow MSX keyboard matrix does this and has no ghosting issues.

[Yellow MSX keyboard schematic](https://github.com/dinoboards/yellow-msx-series-for-rc2014/blob/main/keyboard/schematic.png)

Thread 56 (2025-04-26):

Joystick issue: JB1 should be connected to TRG2_A but is connected to TRG1_B

Pax-nl, 2025-04-26:
Hi,

I found an issue with the Joystick port, pin 11 and 13 on U29 should be reversed.

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

I first encountered the issue with Super Sokuban, which is using MSXgl and Aoineko and Ludo from the MSXgl discord found the cause.

Both me and Ludo debugged the issue by switching pin 11 and 13 on U29/74HCT157

My test setup:
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
And Ludo with a nice cnc pcb:

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

herraa1, 2025-04-27:
The actual fix seems to be swapping signals for pin 11 and 13 of U42/74LS07 (not pins 11 and 13 of U29/74HCT157).

See [https://www.msx.org/forum/msx-talk/hardware/msxmakers-support?page=17](url) for additional information.

Pax-nl, 2025-04-27:
> The actual fix seems to be swapping signals for pin 11 and 13 of U42/74LS07

Sorry my mistake, updated..

herraa1, 2025-04-27:
> Sorry my mistake, updated..

Np.

> The post of Ahmsx is very detailed and explains the issue perfectly..

Thanks, it’s me.

skiselev, 2025-04-28:
Thanks for analyzing and reporting the issue. I am planning to fix the schematic and update the PCB in the near future. Your PCB, or perhaps just lifting U42/74LS07 pins 11 and 13 and using a couple of pieces of wire to connect them to the pads corresponding to pins 13 and 11 respectively can be used as a workaround for existing systems.

skiselev, 2025-04-28:
Comment for myself: The joystick implementation is described in the [MSX Technical Data Book](https://map.grauw.nl/resources/system/msxtech.pdf), page 26 (page 29 in the PDF)

skiselev, 2025-05-01:
Fixed in version 1.5. Described a workaround/patch for previous versions.

Pax-nl, 2025-05-02:
@skiselev thank you for the quick solution.

herraa1, 2025-10-04:
For existing 1.4 mainboards, this [omega-1.4-joyfix-board-v1 interposer board](https://github.com/herraa1/omega-1.4-joyfix-board-v1) which fixes the joystick circuit bug may be useful.

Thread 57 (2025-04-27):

Schematic/PCB issue with JB1 and JB2 on PSG

gfx0101, 2025-04-27:
We identified an error in the schematics and the PCB of the Omega, the JB1 and JB2 are wrongly connected to the PSG and should be swapped.

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

Without this modification the output pin 7 of the port A is driving the pin 6 of port B and the output pin 6 of port B is driving the pin 7 of port A.

See schematics of a standard MSX:

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

BTW i love the Omega, thanks for this great project.

herraa1, 2025-04-27:
Duplicate of #56

gfx0101, 2025-04-27:
Ah yes sorry I just seen it, at least you are well aware now :)

Closed 2025-04-28.

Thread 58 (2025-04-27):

keyboard internationalization option

mpsantos7, 2025-04-27:
Would it be possible to make an optional keyboard with support for dead keys?  I believe that the base could be some of the MSX from Philips, but there are also Brazilian and Argentine models.  Although I don't know how the support for this would be in the case of MSX 2+ BIOS  ...

skiselev, 2025-04-28:
Sorry, I don't have plans to implement any optional keyboard support.
There are multiple reasons for this:
* I personally don't know what keyboard mapping, matrixes, key locations are on the localized MSX systems. If I would want to do that, it will take a lot of my time to research this.
* Different layouts would likely mean implementing different keyboard PCBs. Shouldn't be too difficult, but again I have no time for this.
* I don't think MSX2+ ever supported anything but Japanese layout. It might be possible to patch it to support other keyboards layouts, but again, beyond my level of expertise.

With that said, this project is open source, so feel free to clone the GitHub repo, add support for whatever keyboard layout you want, and contribute back for everyone's enjoyment.

Nephrite-FM, 2025-05-07:
I have a Question on this, too.  You have on the mainboard options a jumper setting (JP2) to set it as a JIS layout.

The Standard ANSI layout, has no katakana ロ (Ro) key.  Is that what the DEAD Key switch footprint is for?  So it can handle this extra, quite necessary to JIS-layout ロ key?  I can't tell yet as your Circuit diags/silkscreens don't mention the kana, only the english ANSI layout, with no mention as to what the Motherboard would accept (i.e. what Switch Rows and Columns correspond to what in the MSX2+ Kana keyboard), and I haven't finished building the mainboard yet (Need to order the rest of the parts) so I can't plug it in and test it even.

I also noticed this:

https://github.com/skiselev/omega/issues/46

is the newest Keyboard layout work with ロ in the dead key space, and no @ key?

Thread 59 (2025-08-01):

Bill of Materials needs updating

gryffinwings, 2025-08-01:
Some components on the Bill of Materials are no longer available, specifically some capacitors and such. I am not sure what would be suitable replacements for such components, and what specification range is needed.

gryffinwings, 2025-08-03:
Here are the links to each component that is listed as no longer available:

[https://www.mouser.com/ProductDetail/Sprague-Goodman/GKG30015?qs=HdU6uKlpW%252BqyxcMMKAqIuQ%3D%3D](url)
[https://www.mouser.com/ProductDetail/Xicon/266-10K-RC?qs=Ji3PIxgD6lSe21OVwgietw%3D%3D](url)
[https://www.mouser.com/ProductDetail/Xicon/291-1M-RC?qs=%252B1l6uH8bpUdZd%2FwHZm0Tyg%3D%3D](url)
[https://www.mouser.com/ProductDetail/Xicon/291-470K-RC?qs=htE2BmrFIEqZn3RsJb10cg%3D%3D](url)
[https://www.mouser.com/ProductDetail/Xicon/291-220K-RC?qs=aj%252B4PPlQAEIjgn7XoDpdMQ%3D%3D](url)
[https://www.mouser.com/ProductDetail/Xicon/291-100K-RC?qs=phIbCmCU35H649ALv8H6YQ%3D%3D](url)
[https://www.mouser.com/ProductDetail/Xicon/291-47K-RC?qs=518VSoIpsciz9LPeL13IBA%3D%3D](url)
[https://www.mouser.com/ProductDetail/Xicon/291-10K-RC?qs=RF4ygd%252Bc9XonU7%252BrioLr7Q%3D%3D](url)
[https://www.mouser.com/ProductDetail/Xicon/291-5.6K-RC?qs=wTzul1STCXDJToBqV9nH5g%3D%3D](url)
[https://www.mouser.com/ProductDetail/Xicon/291-4.7K-RC?qs=7B2XhTZr119rO1NcwN3EPA%3D%3D](url)
[https://www.mouser.com/ProductDetail/Xicon/291-2.2K-RC?qs=Ki%252BLk3Z8T%2Fsxb3PDRfjWOA%3D%3D](url)
[https://www.mouser.com/ProductDetail/Xicon/291-2.7K-RC?qs=7B2XhTZr11%2FKd5%252BEduZOeQ%3D%3D](url)
[https://www.mouser.com/ProductDetail/Xicon/291-2.2K-RC?qs=Ki%252BLk3Z8T%2Fsxb3PDRfjWOA%3D%3D](url)
[https://www.mouser.com/ProductDetail/Xicon/291-1K-RC?qs=SesEBVR27EZb4uEcjpQCWw%3D%3D](url)
[https://www.mouser.com/ProductDetail/Xicon/291-470-RC?qs=7iayVx7sPLPWIj8oDCARaQ%3D%3D](url)
[https://www.mouser.com/ProductDetail/Xicon/291-100-RC?qs=Ciw1tEe6bjABFyA%252BrWySIg%3D%3D](url)
[https://www.mouser.com/ProductDetail/Xicon/291-75-RC?qs=YChipG9TzFQWUllMkNltvQ%3D%3D](url)
[https://www.mouser.com/ProductDetail/Xicon/291-180-RC?qs=6CJqeO%2FhICYdaaSvnIN2Bg%3D%3D](url)
[https://www.mouser.com/ProductDetail/TDK/FG28X5R1E106MRT00?qs=LtAzLad%252BoeWtMLDWB79u3g%3D%3D](url)
[https://www.mouser.com/ProductDetail/Littelfuse/RUSBF075?qs=hv6pn79dJPT%2FmlM3%252Ba3oSw%3D%3D](url)

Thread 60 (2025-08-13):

Update PCBway shared projects to 1.5

Fuzzweed, 2025-08-13:
Hi, checking the silkscreen on PCBway shared projects the mainboard is revision 1.4. Can this update to 1.5 so I can order the PCB.

Fuzzweed, 2025-08-13:
Ah OK. Sorry to presume it was you!
I'm having some trouble getting the github gerbers to pcbway as there is some file corruption or incompatability. I tried importing them into kicad 8, but it didn't like that either.
Is it possible to have a zip file created just with latest kicad files for main board and keyboard and then I can create a new set of gerbers. I know the individual files are on github, but I'm not exactly sure what is a 'full set' because of different revision dates etc....

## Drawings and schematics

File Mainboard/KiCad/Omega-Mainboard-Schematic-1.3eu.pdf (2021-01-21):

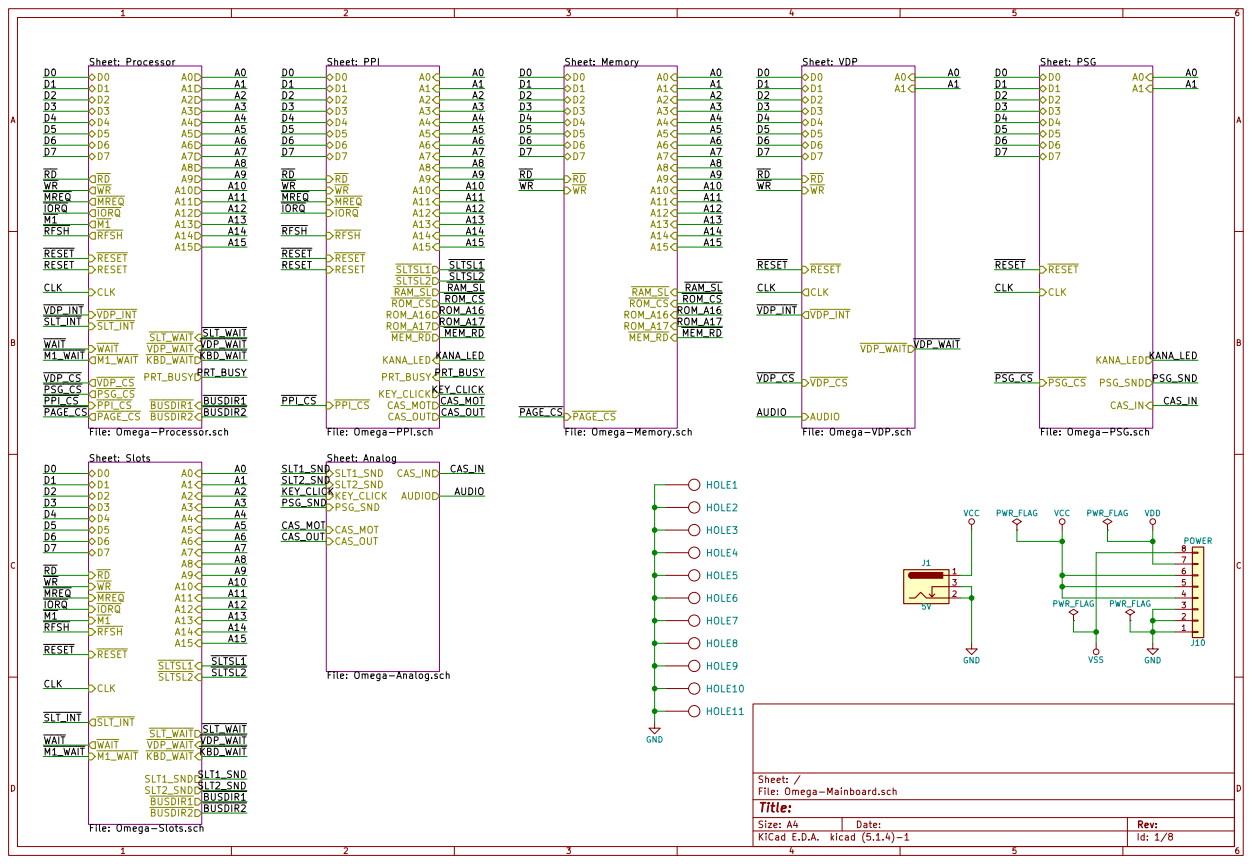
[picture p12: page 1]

File: Omega-Processor.sch A0A1A2A3A4A5A6A7A8A9 A10 A11 A12 A13 A14 A15 D0 D1 D2 D3 D4 D5 D6 D7 RDWR MREQ

SLT_WAIT
File: Omega-Slots.schA0A1A2A3A4A5A6A7A8A9 A10 A11 A12 A13 A14 A15 D0 D1 D2 D3 D4 D5 D6 D7 RDWR MREQ

File: Omega-PSG.sch

File: Omega-Analog.sch

File: Omega-Mainboard.sch Sheet: /
Id: 1/8 Title:

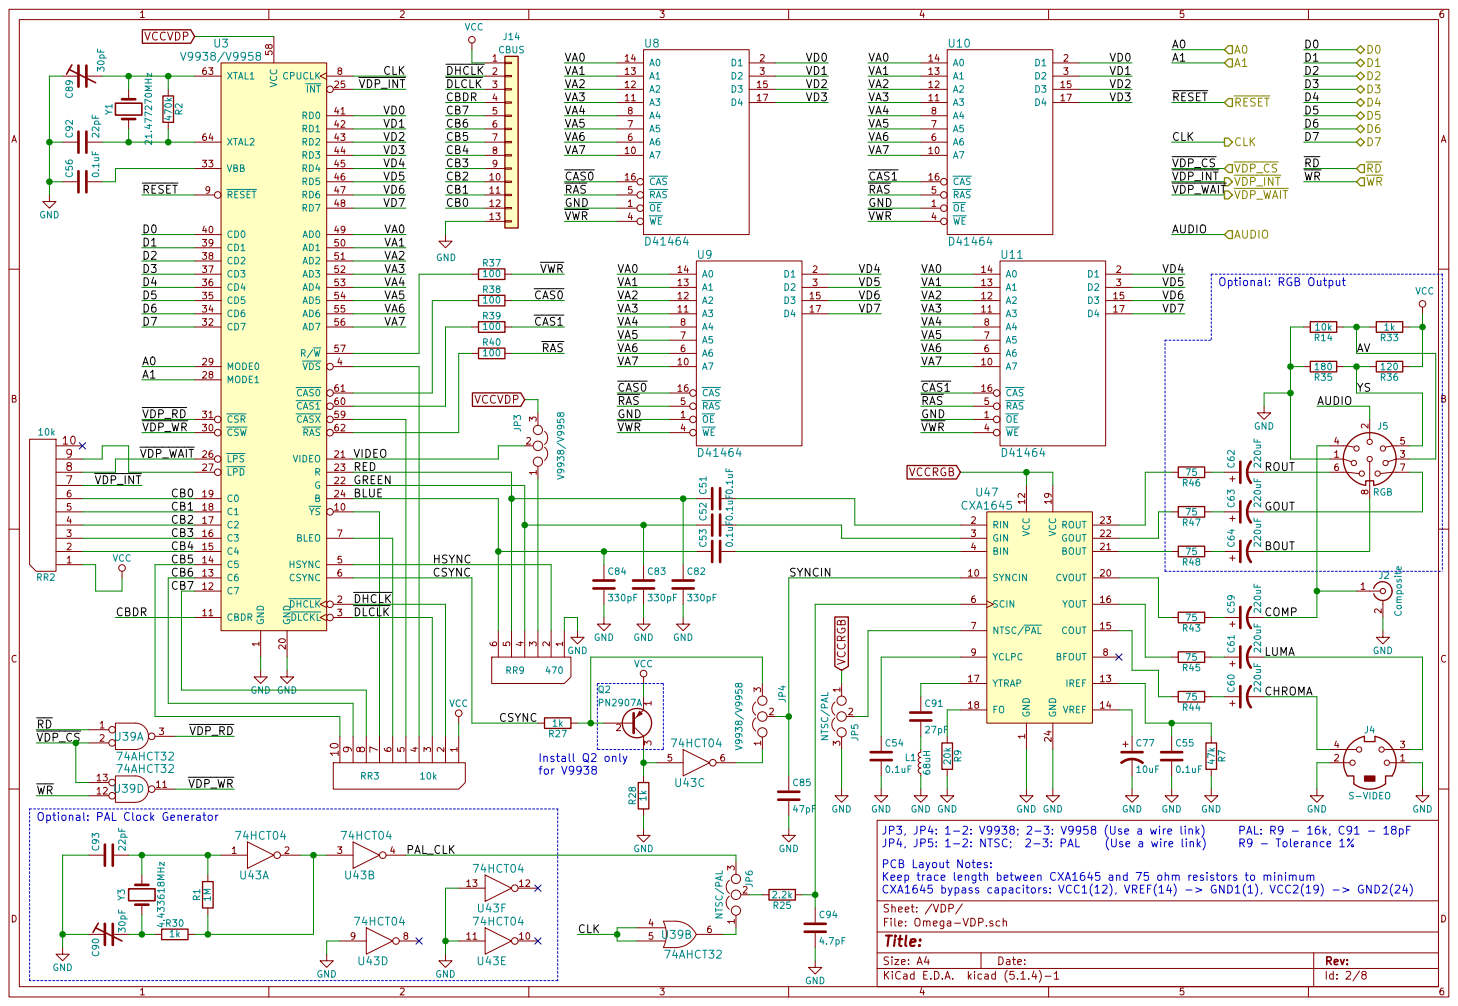
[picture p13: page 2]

1 YS 10 CBDR 11 C7 12 C6 13 C5 14 C4 15 C3 16 C2 17 C1 18 C0 19 DHCLK 2 GND 20 VIDEO 21 G

2 J2 Composite GND GND GND

PCB Layout Notes: CXA1645 bypass capacitors: VCC1(12), VREF(14) -> GND1(1), VCC2(19) -> GND2(24)

Keep trace length between CXA1645 and 75 ohm resistors to minimum

File: Omega-VDP.sch Sheet: /VDP/ 1

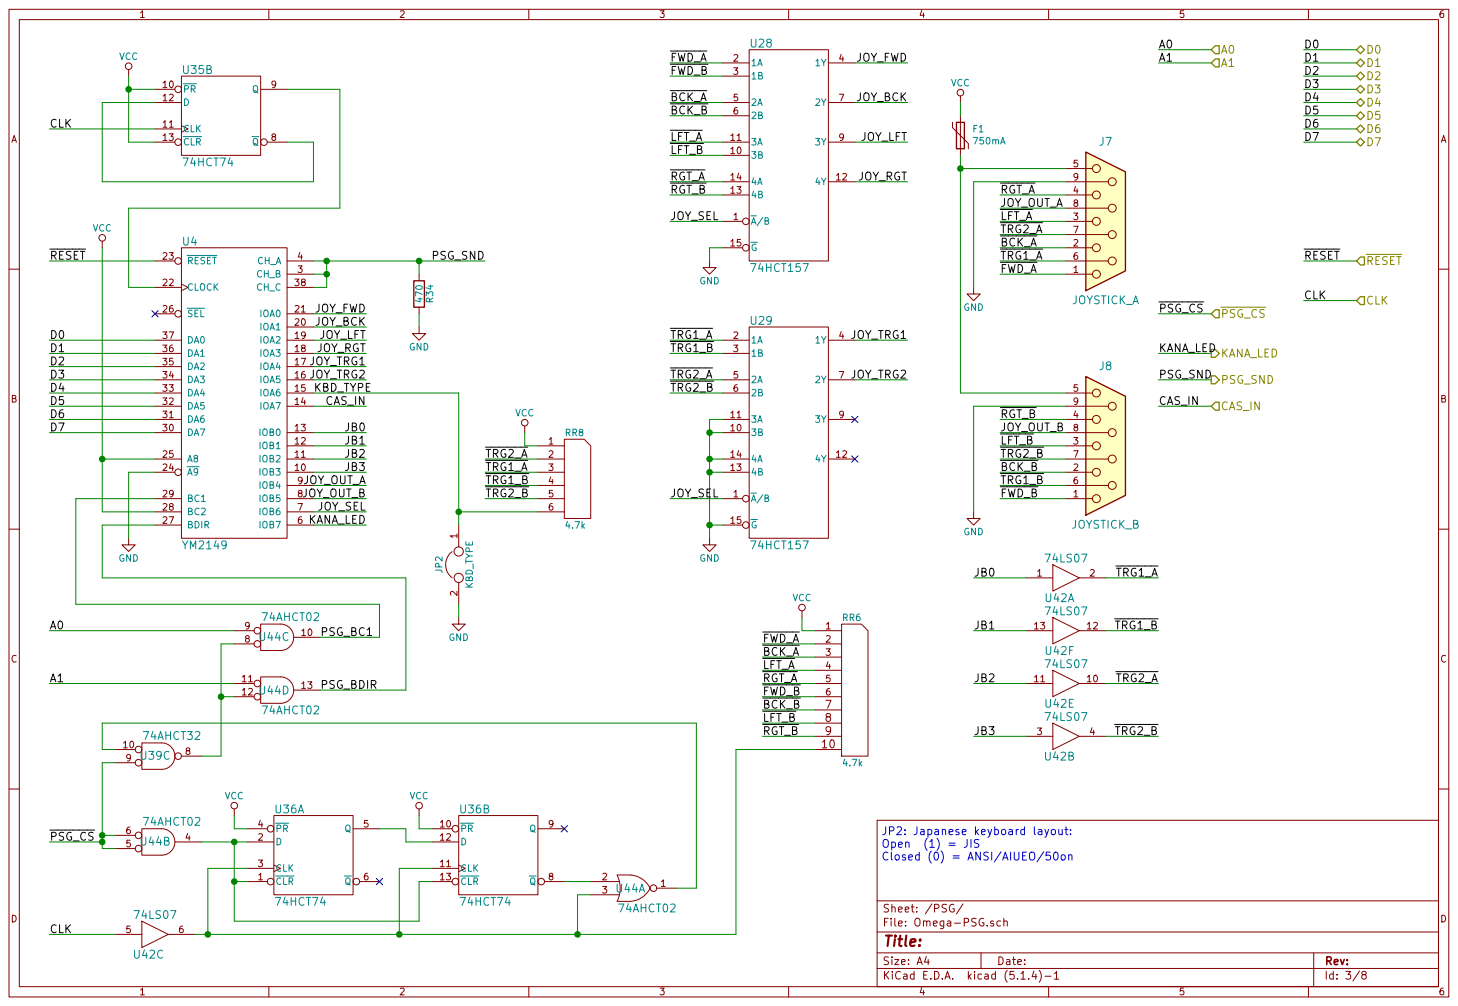
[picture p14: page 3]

74HCT157 GND
File: Omega-PSG.sch Sheet: /PSG/ 470 R34

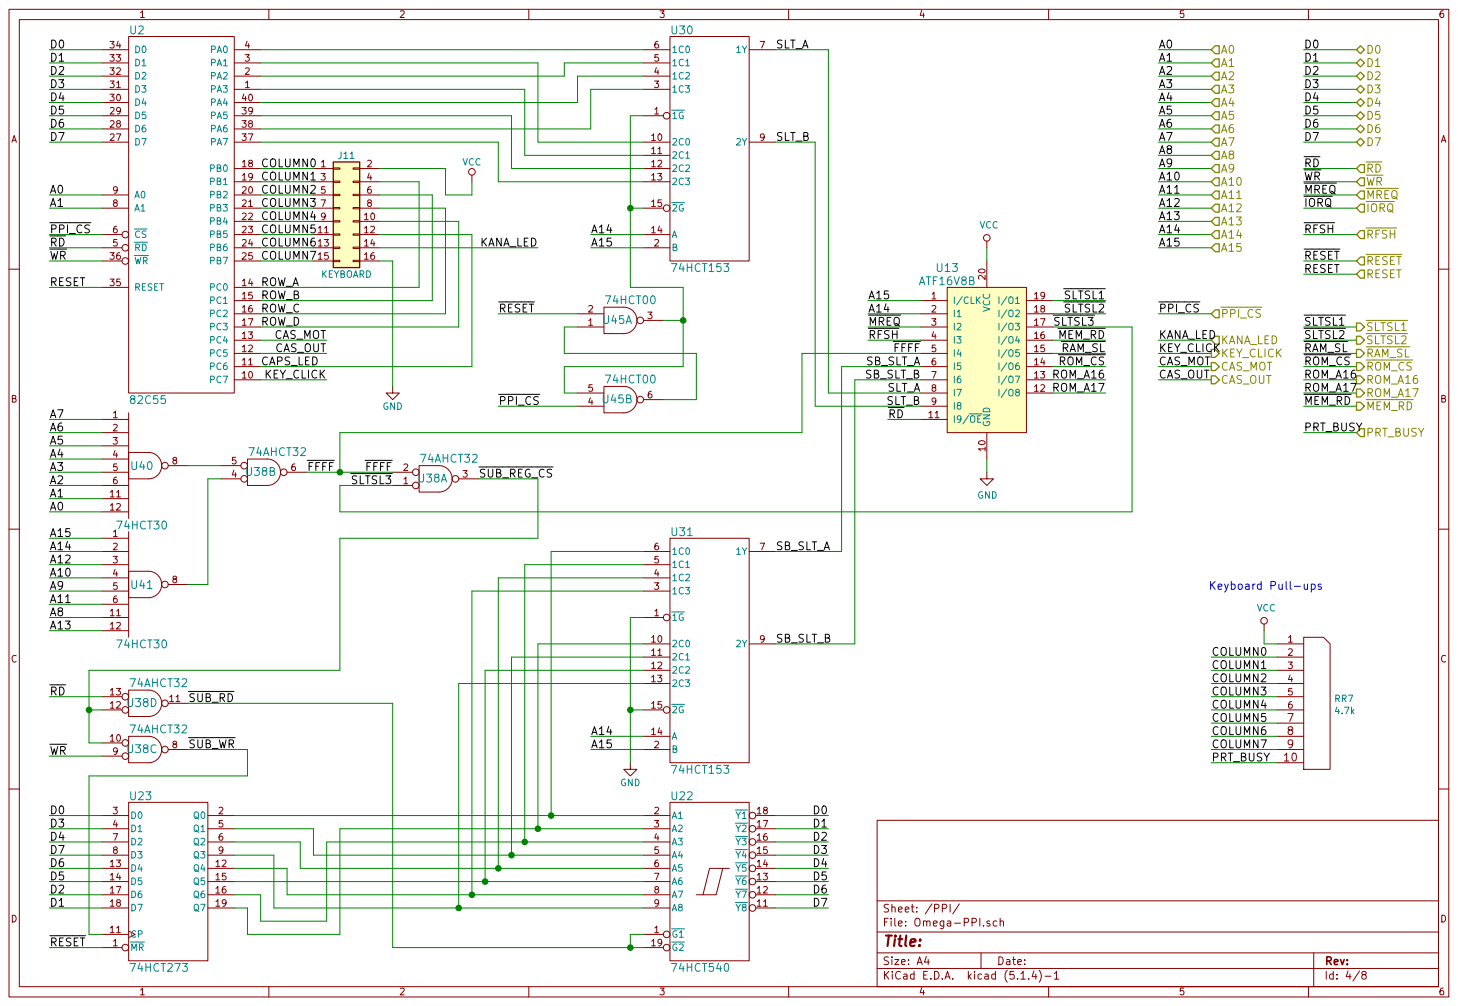
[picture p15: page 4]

COLUMN3 | 7 | 8

COLUMN5 | 11 | 12

1C1 5 | SB_SLT_B
1C2 4
1C3 3

2C1 11
2C2 12

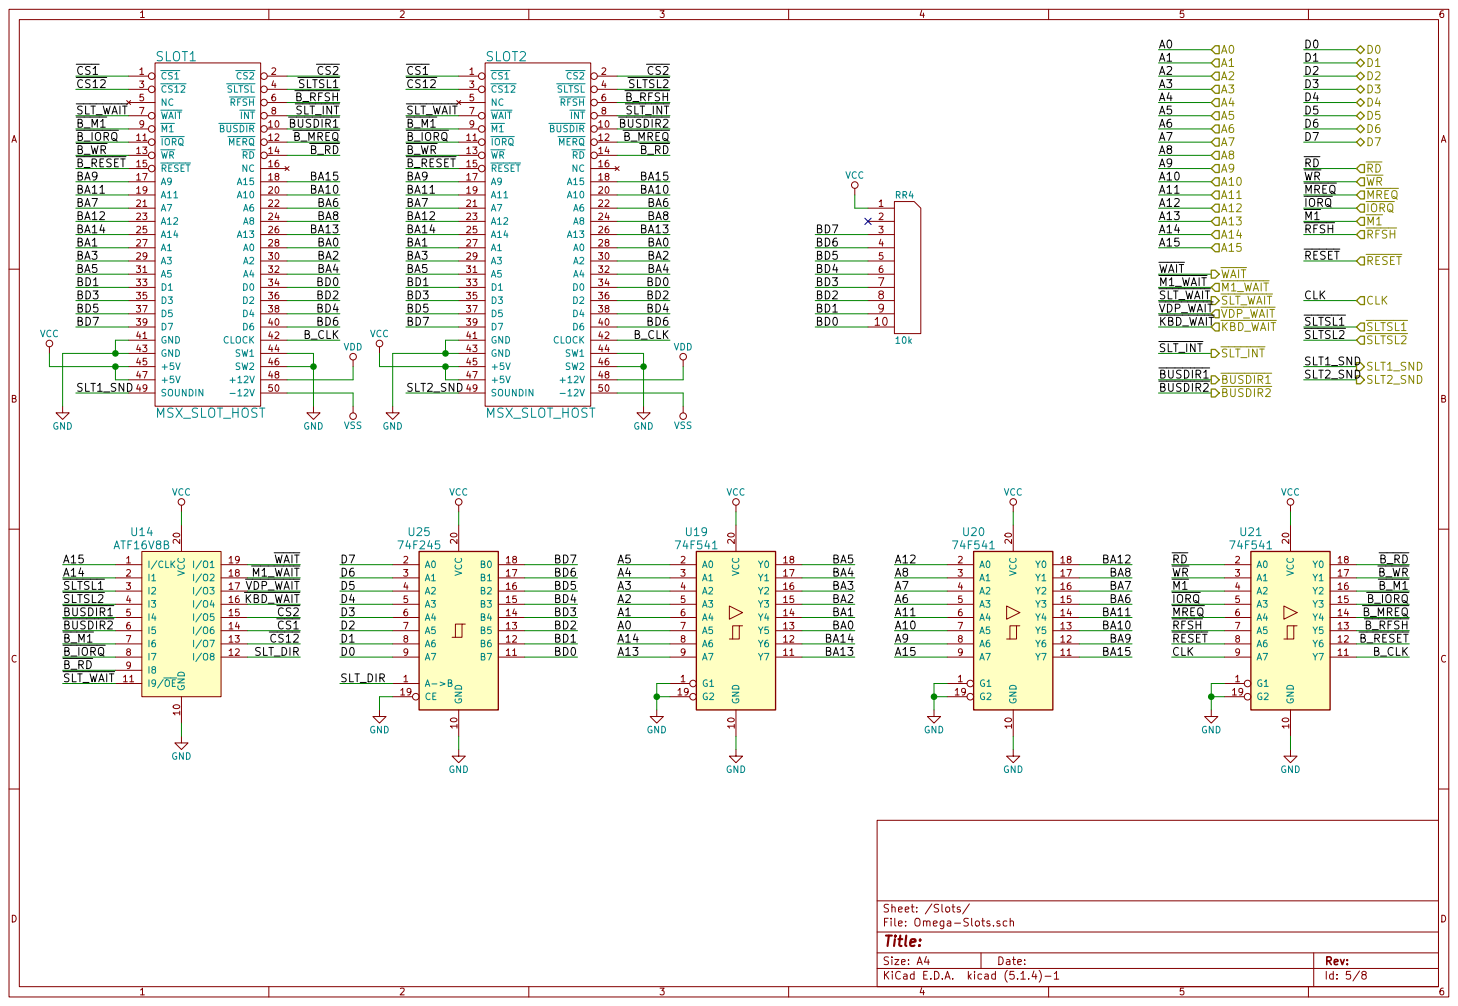
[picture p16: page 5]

File: Omega-Slots.sch Sheet: /Slots/
Id: 5/8 Title:

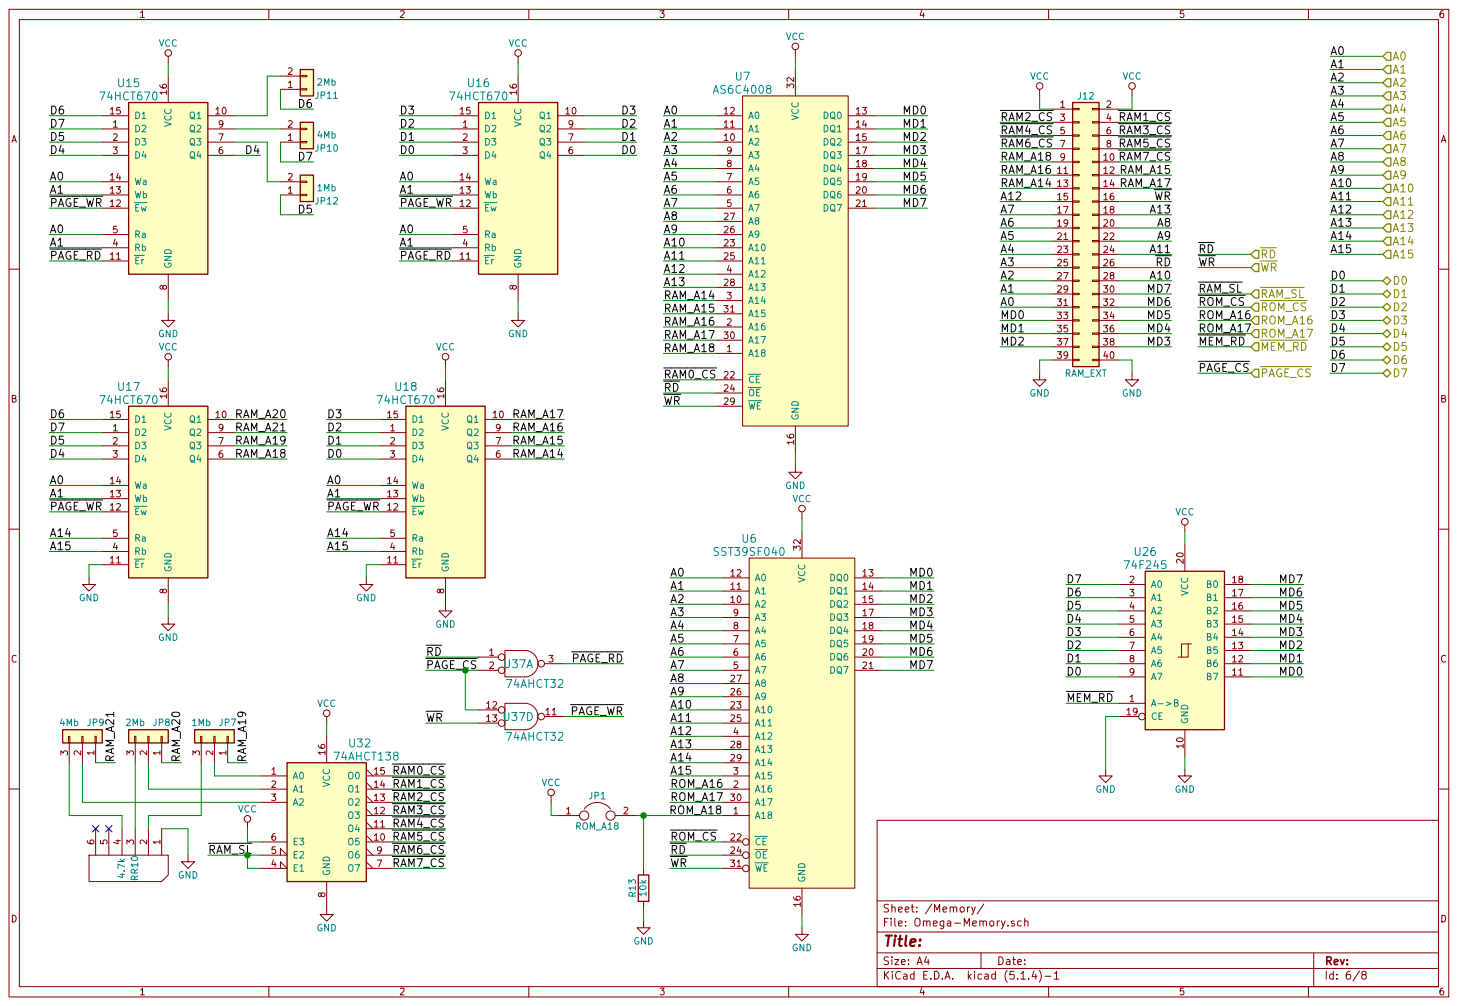
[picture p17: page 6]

File: Omega-Memory.sch
Id: 6/8 Title:

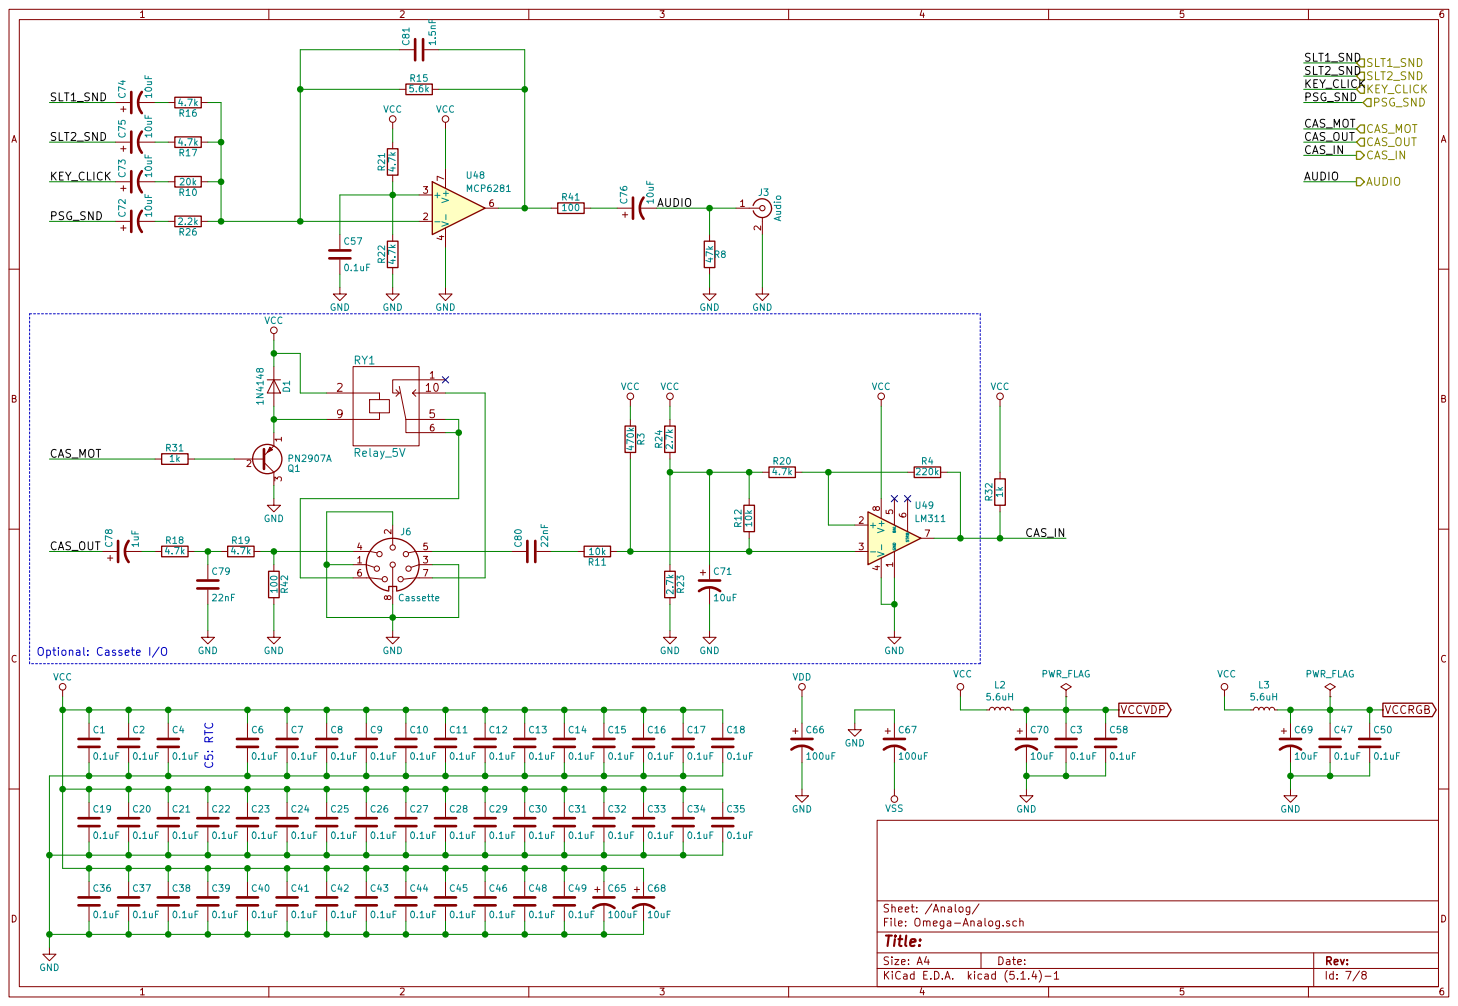
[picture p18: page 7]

File: Omega-Analog.sch
Id: 7/8 Title:

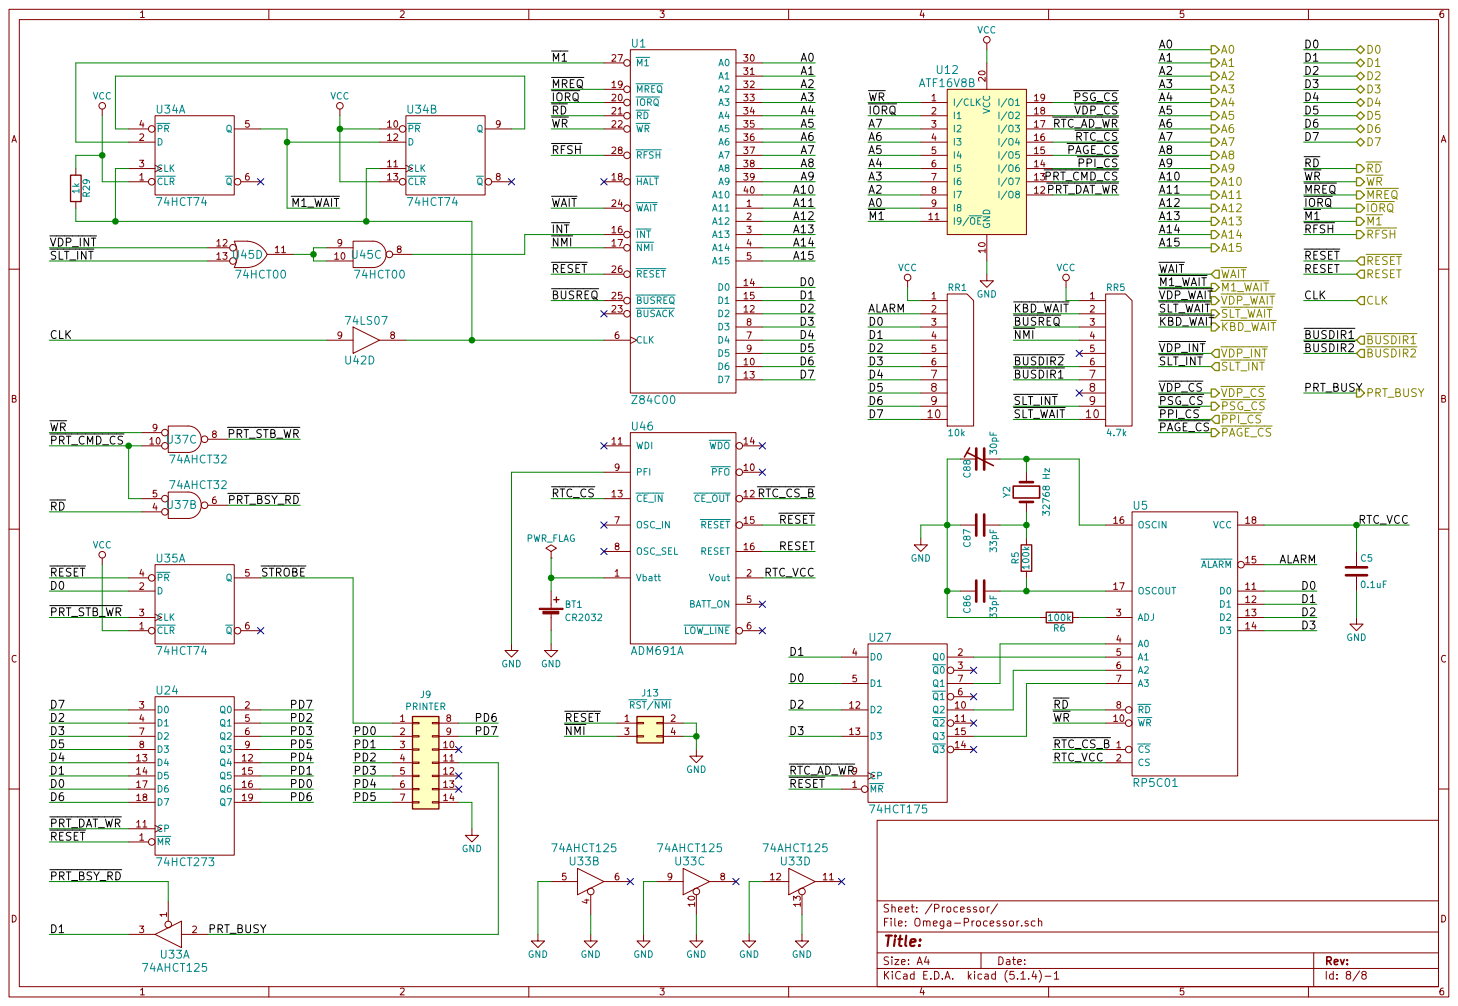
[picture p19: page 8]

File: Omega-Processor.sch Sheet: /Processor/ GND

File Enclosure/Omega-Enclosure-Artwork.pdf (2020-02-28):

### PRINTER

### RESET TAPE

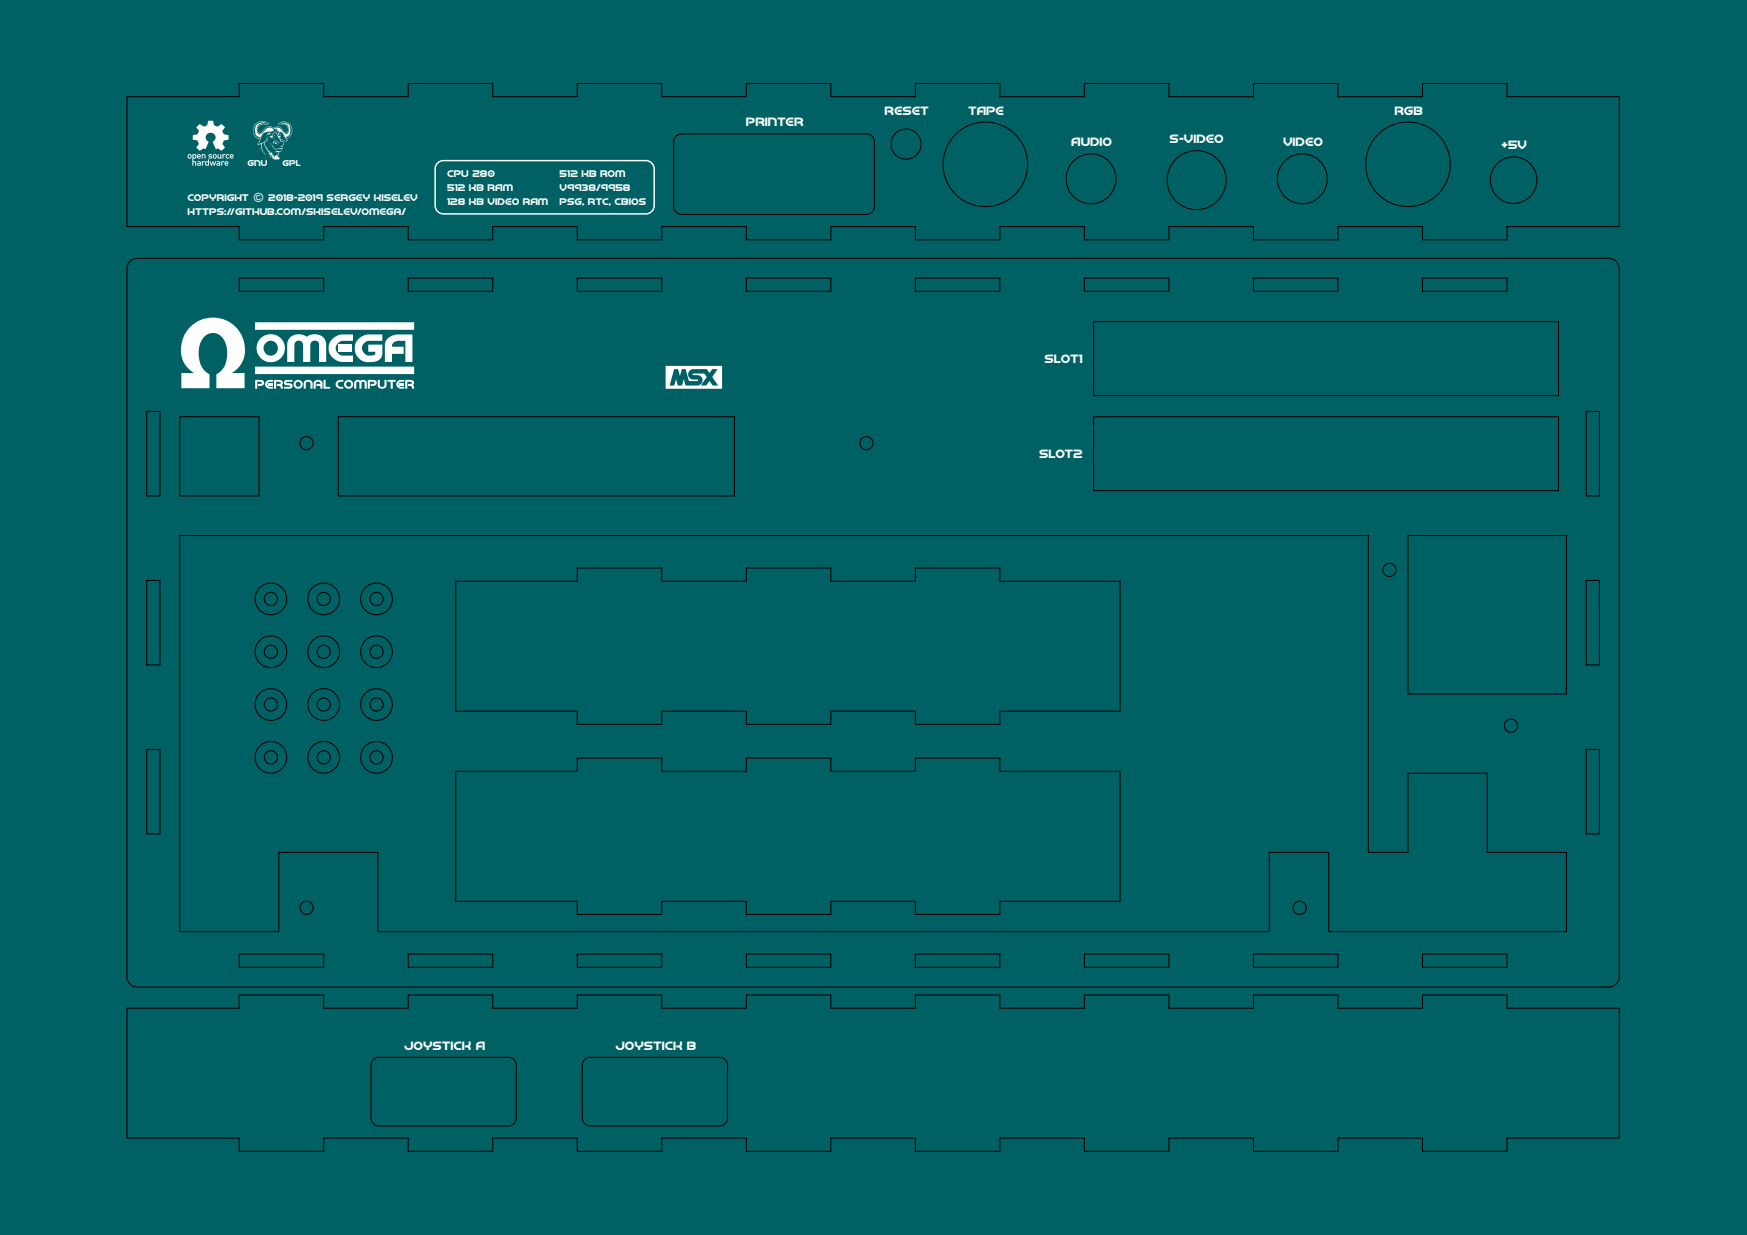
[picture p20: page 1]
2018-2019 Sergey Kiselev; AUDIO; S-Video; VIDEO; RGB; Joystick A; Joystick B; SLOT1; SLOT2; GNU; GPL

CPU Z80
512 kB RAM
128 kB video RAM

512 kB ROM
PSG, RTC, CBIOS

Copyright ©
https://github.com/skiselev/omega/

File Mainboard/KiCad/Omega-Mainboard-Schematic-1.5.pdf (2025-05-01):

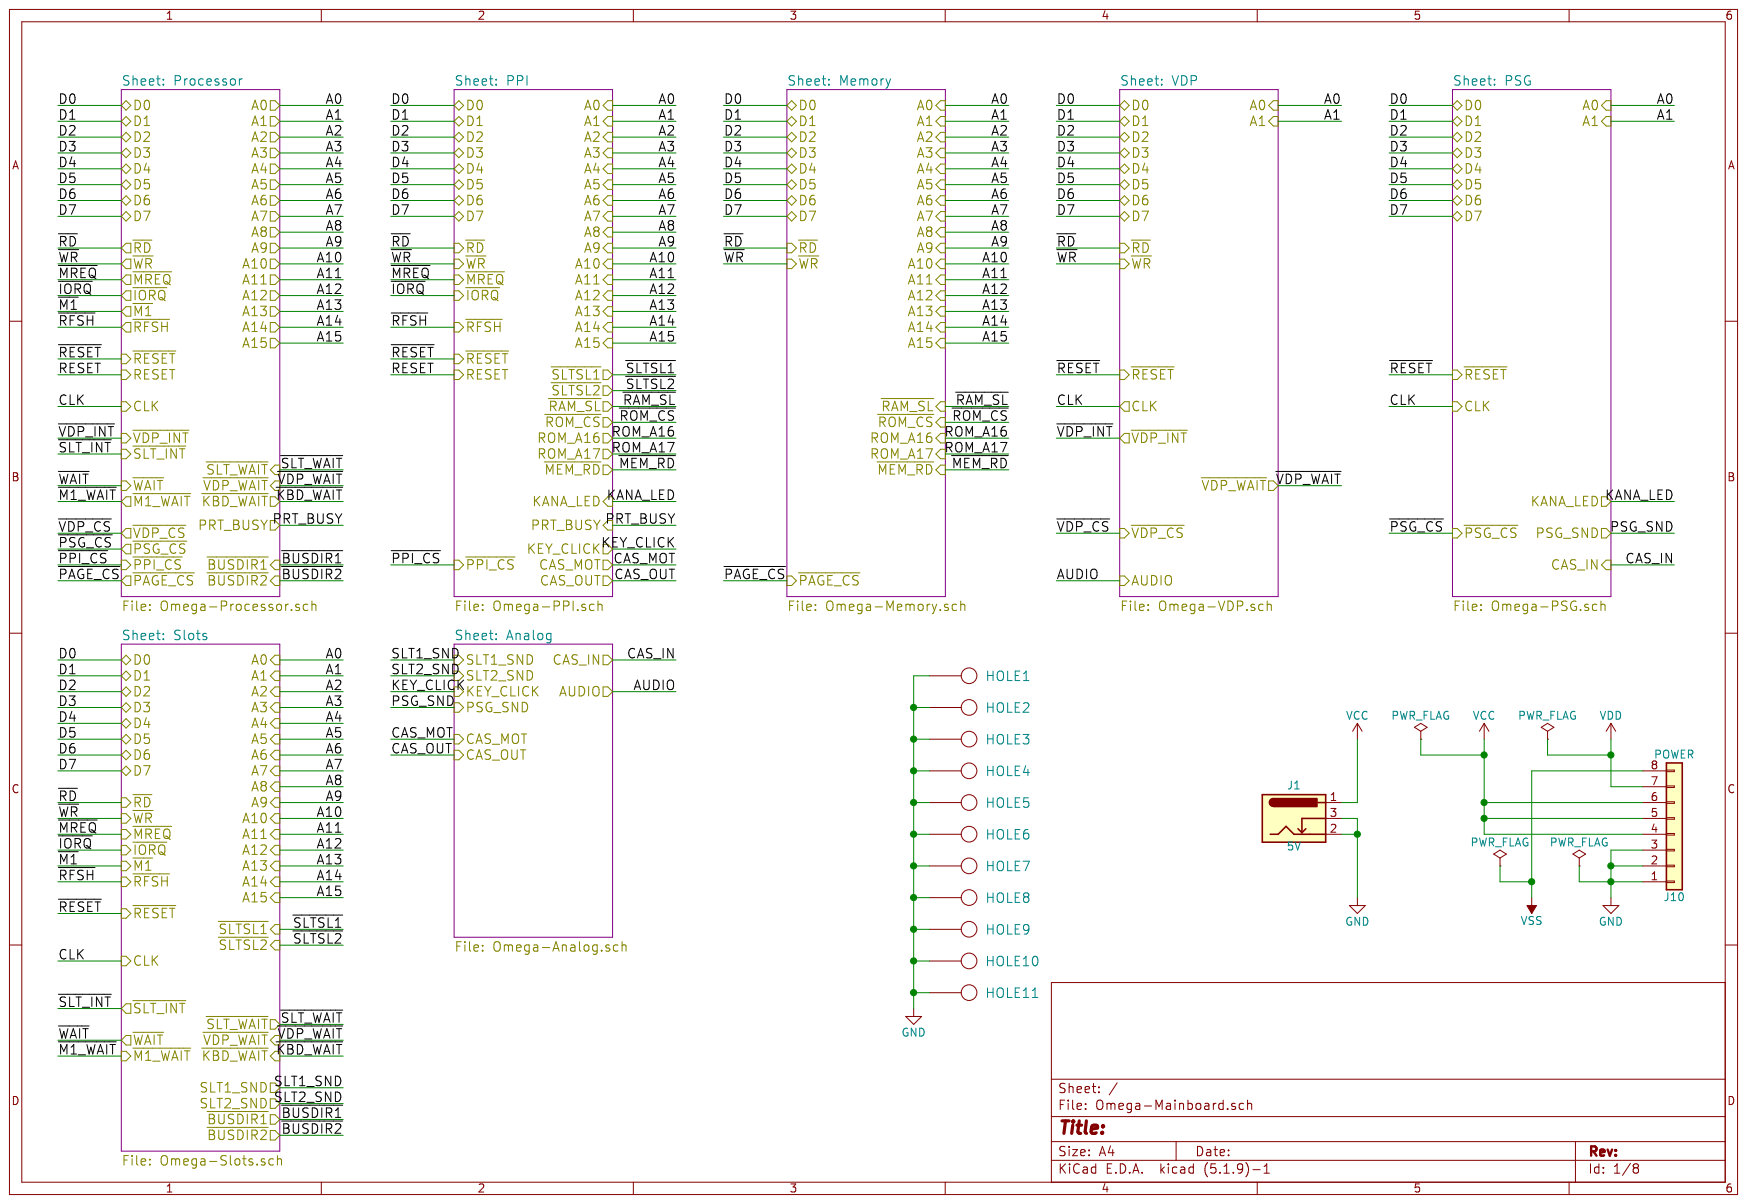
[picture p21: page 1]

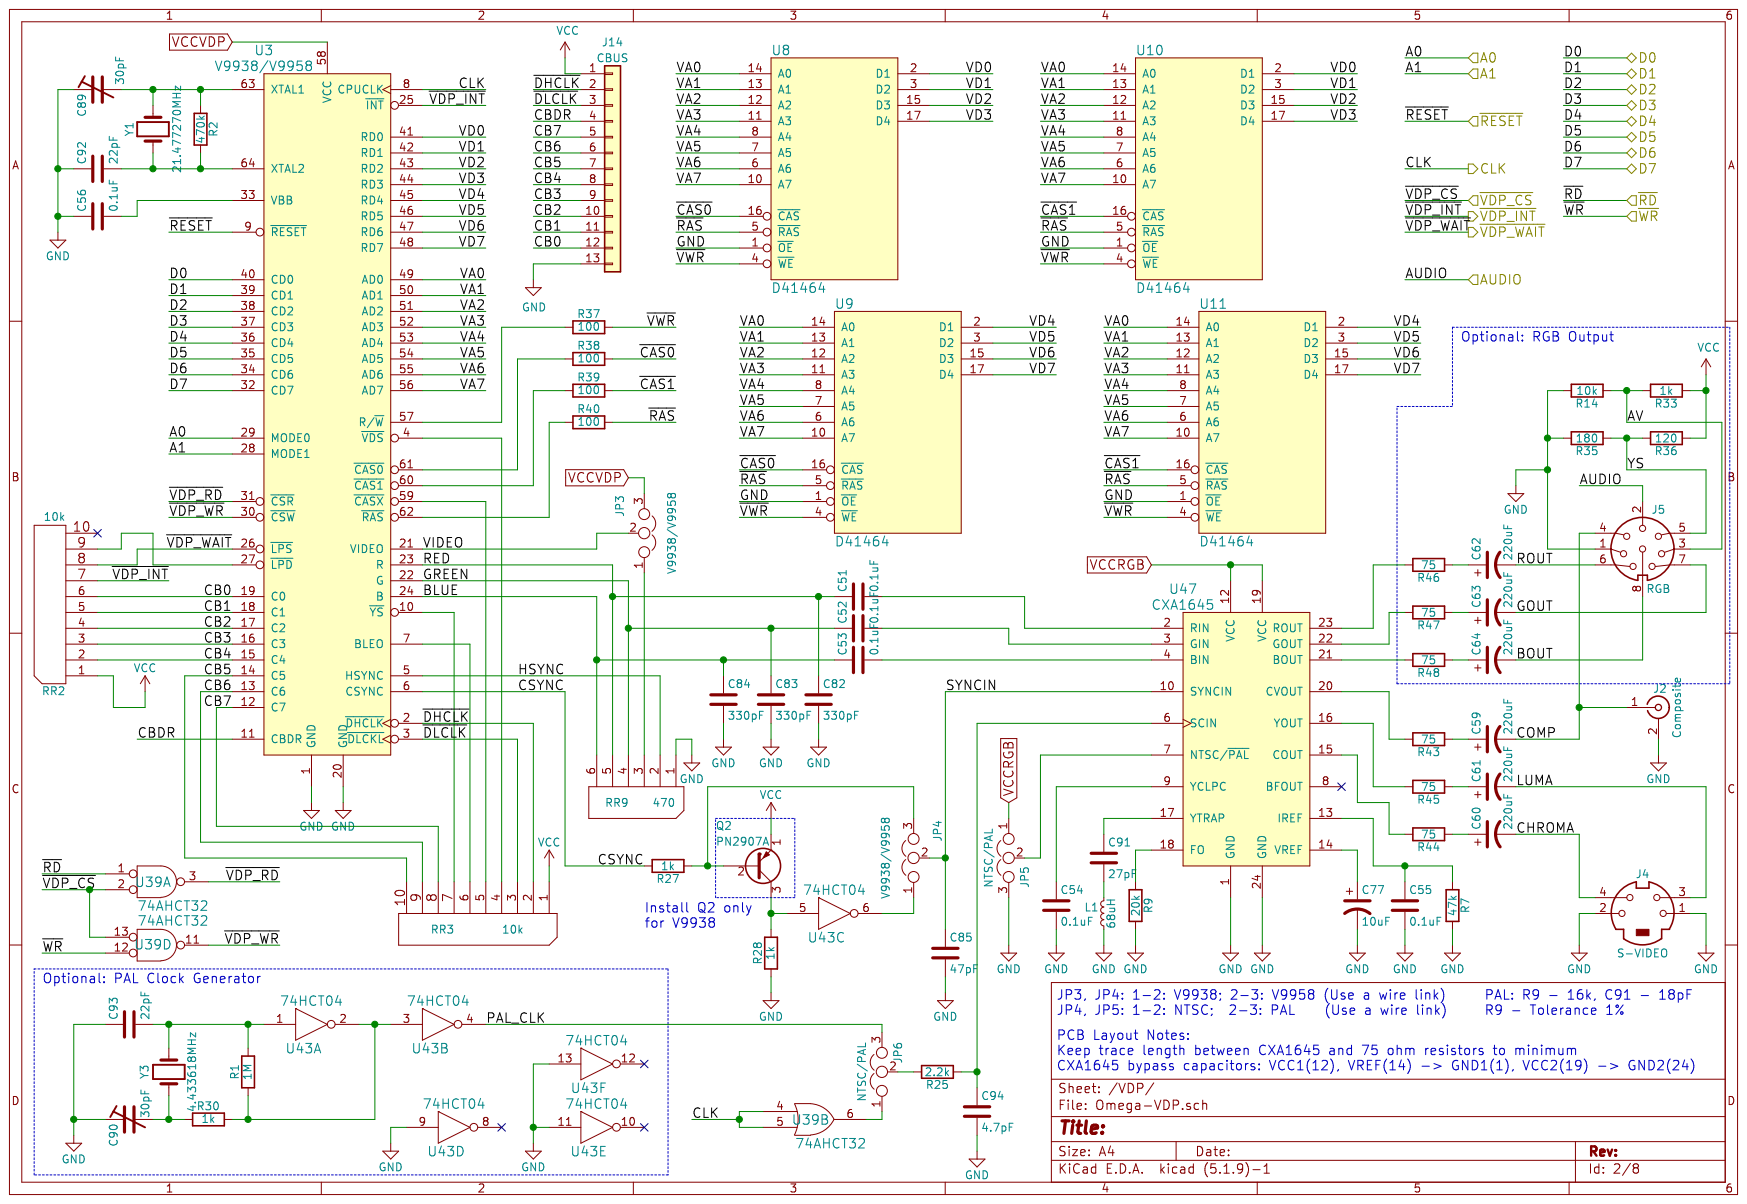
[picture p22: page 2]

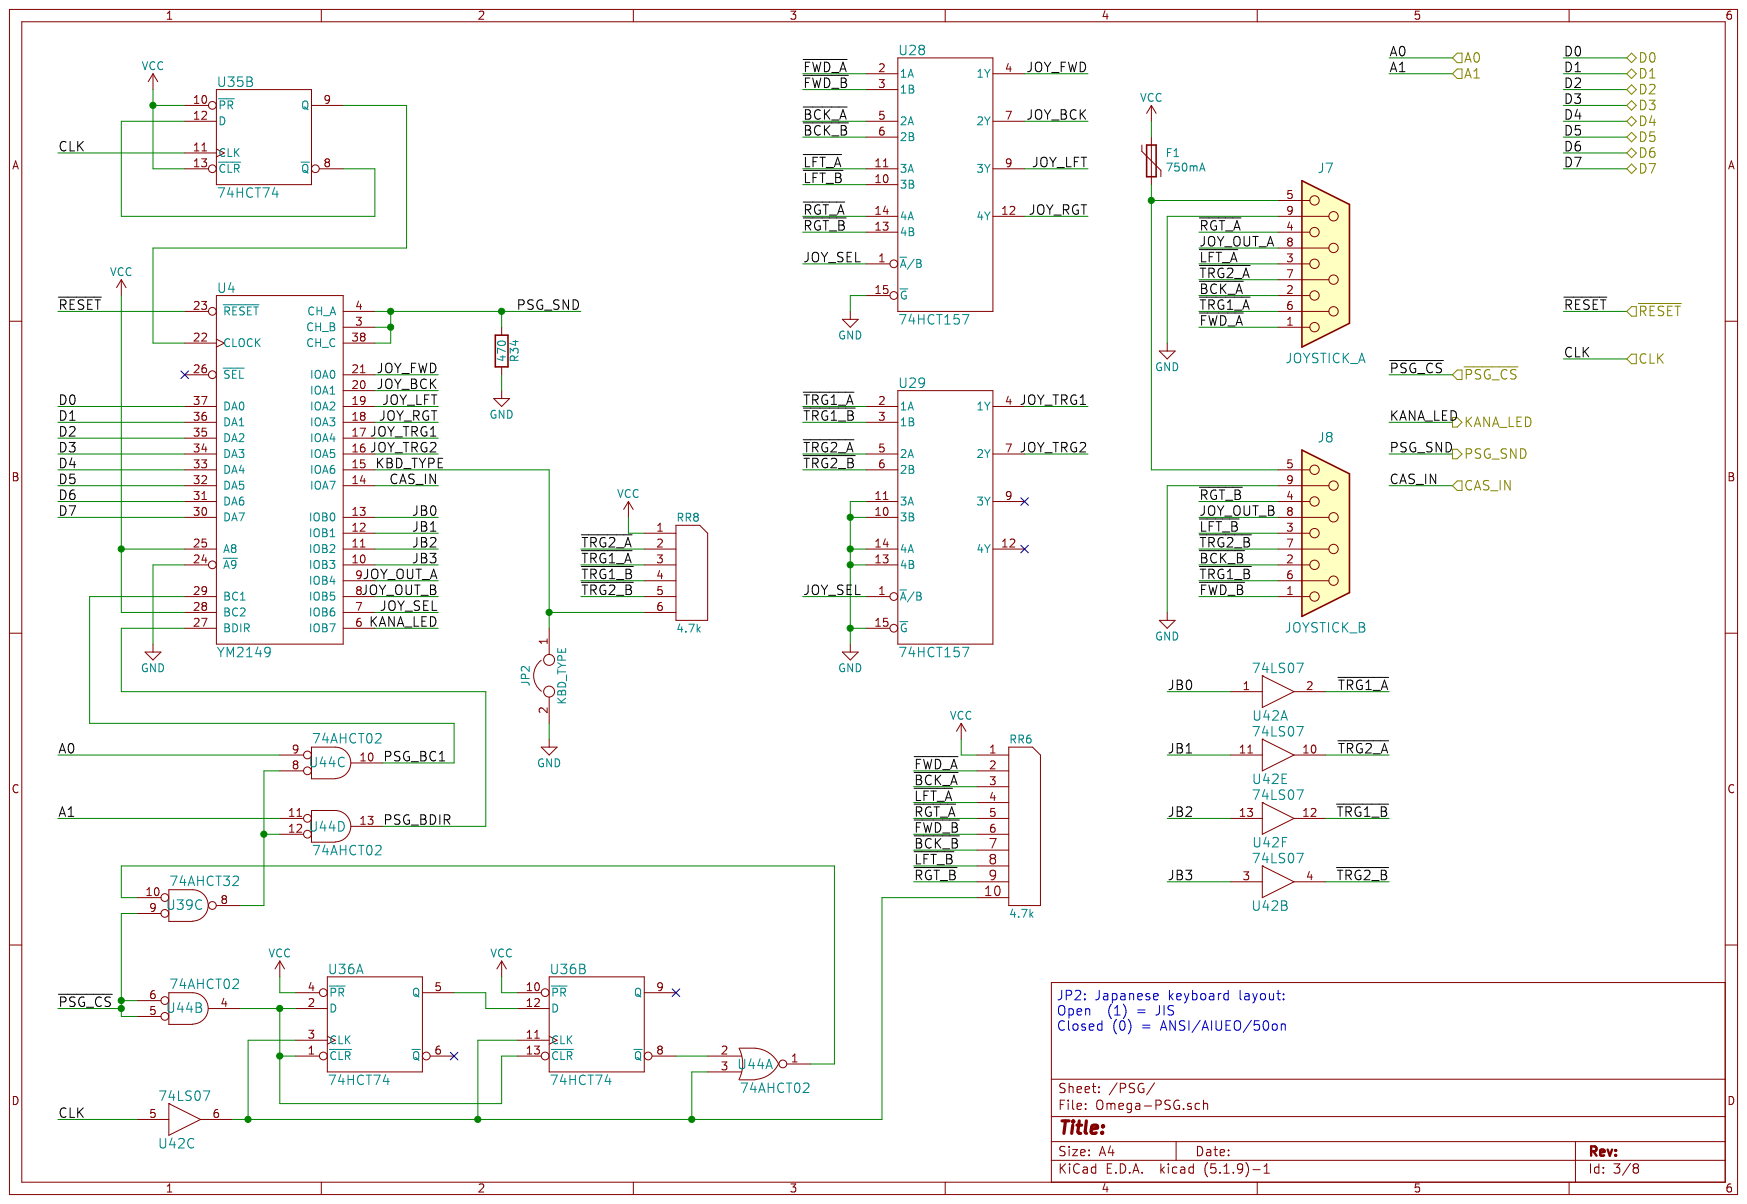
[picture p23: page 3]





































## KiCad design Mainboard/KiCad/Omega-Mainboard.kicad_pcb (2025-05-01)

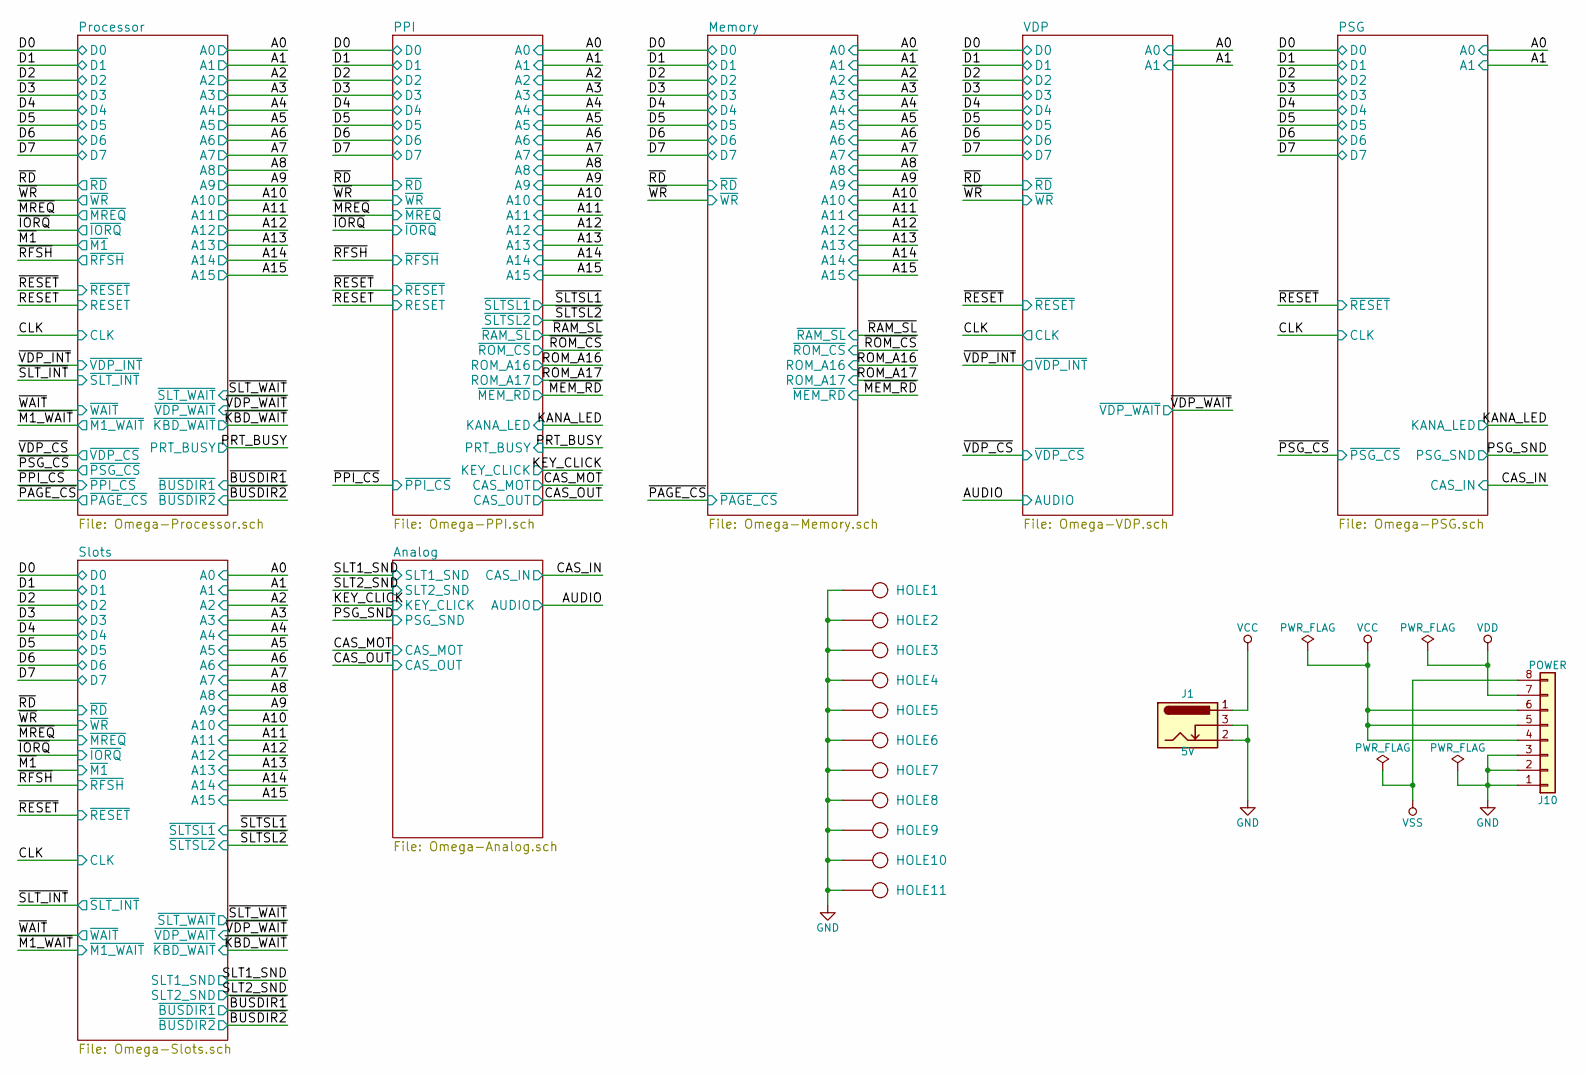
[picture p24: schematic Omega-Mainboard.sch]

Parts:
HOLE1, HOLE2, HOLE3, HOLE4, HOLE5, HOLE6, HOLE7, HOLE8, HOLE9, HOLE10, HOLE11: HOLE; Hole_3mm
J1: 5V; Conn_Power_Jack_Circular_Pads
J10: POWER; Conn_Friction_Lock_8P_2.54mm

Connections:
GND: HOLE1.1, HOLE2.1, HOLE3.1, HOLE4.1, HOLE5.1, HOLE6.1, HOLE7.1, HOLE8.1, HOLE9.1, HOLE10.1, HOLE11.1, J1.2, J1.3, J10.1, J10.2, J10.3; also elsewhere on the board
VCC: J1.1, J10.4, J10.5, J10.6; also elsewhere on the board
VDD: J10.7; also elsewhere on the board
VSS: J10.8; also elsewhere on the board

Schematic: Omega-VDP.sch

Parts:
C51, C52, C53, C54, C55, C56: 0.1uF; Cap_Cer_508
C59, C60, C61, C62, C63, C64: 220uF; Cap_Elec_Radial_10mm
C77: 10uF; Cap_Elec_Radial_5mm
C82, C83, C84: 330pF; Cap_Cer_508
C85: 47pF; Cap_Cer_508
C89, C90: 30pF; C_Trim_Murata
C91: 27pF; Cap_Cer_508
C92, C93: 22pF; Cap_Cer_508
C94: 4.7pF; Cap_Cer_508
J2: Composite; Conn_RCA_Right
J4: S-VIDEO; Conn_Mini_DIN_4pin
J5: RGB; Conn_DIN_8pin
J14: CBUS; Conn_Pin_Header_13x1_2.54mm
JP3, JP4: V9938/V9958; Conn_Pin_Header_3x1_2.54mm
JP5, JP6: NTSC/PAL; Conn_Pin_Header_3x1_2.54mm
L1: 68uH; Res_762
Q2: PN2907A; Transistor_TO92_EBC_254
R1: 1M; Res_762
R2: 470k; Res_762
R7: 47k; Res_762
R9: 20k; Res_762
R14: 10k; Res_762
R25: 2.2k; Res_762
R27, R28, R30, R33: 1k; Res_762
R35: 180; Res_762
R36: 120; Res_762
R37, R38, R39, R40: 100; Res_762
R43, R44, R45, R46, R47, R48: 75; Res_762
RR2, RR3: 10k; Conn_SIL10
RR9: 470; Conn_SIL6
U3: V9938/V9958; IC_SDIP64_600
U8, U9, U10, U11: D41464; IC_DIP18_300
U39: 74AHCT32; IC_DIP14_300
U43: 74HCT04; IC_DIP14_300
U47: CXA1645; IC_DIP24_400
Y1: 21.477270MHz; Crystal_HC-49U_Vert
Y3: 4.433618MHz; Crystal_HC-49U_Vert

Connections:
/A0: U3.29 (MODE0); also elsewhere on the board
/A1: U3.28 (MODE1); also elsewhere on the board
/AUDIO: J5.2; also elsewhere on the board
/CLK: U3.8 (CPUCLK), U39.4, U39.5; also elsewhere on the board
/D0: U3.40 (CD0); also elsewhere on the board
/D1: U3.39 (CD1); also elsewhere on the board
/D2: U3.38 (CD2); also elsewhere on the board
/D3: U3.37 (CD3); also elsewhere on the board
/D4: U3.36 (CD4); also elsewhere on the board
/D5: U3.35 (CD5); also elsewhere on the board
/D6: U3.34 (CD6); also elsewhere on the board
/D7: U3.32 (CD7); also elsewhere on the board
/VDP/AV: J5.3, R14.2, R33.1
/VDP/BLUE: C53.1, C84.1, RR9.6, U3.24 (B)
/VDP/BOUT: C64.2, J5.8
/VDP/CB0: J14.12, RR2.6, U3.19 (C0)
/VDP/CB1: J14.11, RR2.5, U3.18 (C1)
/VDP/CB2: J14.10, RR2.4, U3.17 (C2)
/VDP/CB3: J14.9, RR2.3, U3.16 (C3)
/VDP/CB4: J14.8, RR2.2, U3.15 (C4)
/VDP/CB5: J14.7, RR3.10, U3.14 (C5)
/VDP/CB6: J14.6, RR3.9, U3.13 (C6)
/VDP/CB7: J14.5, RR3.8, U3.12 (C7)
/VDP/CBDR: J14.4, U3.11 (CBDR)
/VDP/CHROMA: C60.2, J4.4
/VDP/COMP: C59.2, J2.1 (In), J5.4
/VDP/CSYNC: R27.2, U3.6 (CSYNC)
/VDP/GOUT: C63.2, J5.7
/VDP/GREEN: C52.1, C83.1, RR9.4, U3.22 (G)
/VDP/HSYNC: RR9.2, U3.5 (HSYNC)
/VDP/LUMA: C61.2, J4.3
/VDP/PAL_CLK: JP6.3, U43.4
/VDP/RED: C51.1, C82.1, RR9.5, U3.23 (R)
/VDP/ROUT: C62.2, J5.6
/VDP/SYNCIN: C85.1, JP4.2, U47.10 (SYNCIN)
/VDP/VA0: U3.49 (AD0), U8.14, U9.14, U10.14, U11.14
/VDP/VA1: U3.50 (AD1), U8.13, U9.13, U10.13, U11.13
/VDP/VA2: U3.51 (AD2), U8.12, U9.12, U10.12, U11.12
/VDP/VA3: U3.52 (AD3), U8.11, U9.11, U10.11, U11.11
/VDP/VA4: U3.53 (AD4), U8.8, U9.8, U10.8, U11.8
/VDP/VA5: U3.54 (AD5), U8.7, U9.7, U10.7, U11.7
/VDP/VA6: U3.55 (AD6), U8.6, U9.6, U10.6, U11.6
/VDP/VA7: U3.56 (AD7), U8.10, U9.10, U10.10, U11.10
/VDP/VD0: U3.41 (RD0), U8.2, U10.2
/VDP/VD1: U3.42 (RD1), U8.3, U10.3
/VDP/VD2: U3.43 (RD2), U8.15, U10.15
/VDP/VD3: U3.44 (RD3), U8.17, U10.17
/VDP/VD4: U3.45 (RD4), U9.2, U11.2
/VDP/VD5: U3.46 (RD5), U9.3, U11.3
/VDP/VD6: U3.47 (RD6), U9.15, U11.15
/VDP/VD7: U3.48 (RD7), U9.17, U11.17
/VDP/VIDEO: JP3.2, U3.21 (VIDEO)
/VDP/YS: J5.5, R35.2, R36.1
/VDP/~CAS0: R38.1, U8.16, U9.16
/VDP/~CAS1: R39.1, U10.16, U11.16
/VDP/~DHCLK: J14.2, RR3.2, U3.2 (~DHCLK)
/VDP/~DLCLK: J14.3, RR3.3, U3.3 (~DLCKL)
/VDP/~RAS: R40.1, U8.5, U9.5, U10.5, U11.5
/VDP/~VDP_RD: U3.31 (~CSR), U39.3
/VDP/~VDP_WR: U3.30 (~CSW), U39.11
/VDP/~VWR: R37.1, U8.4, U9.4, U10.4, U11.4
/~RD: U39.1; also elsewhere on the board
/~RESET: U3.9 (~RESET); also elsewhere on the board
/~VDP_CS: U39.2, U39.13; also elsewhere on the board
/~VDP_INT: RR2.7, U3.25 (~INT); also elsewhere on the board
/~VDP_WAIT: RR2.8, U3.26 (~LPS); also elsewhere on the board
/~WR: U39.12; also elsewhere on the board
GND: C54.2, C55.2, C56.1, C77.2, C82.2, C83.2, C84.2, C85.2, C89.1, C90.1, C92.1, C93.1, C94.2, J2.2 (Ext), J4.1, J4.2, J4.~, J5.1, J5.~, J14.13, JP5.3, L1.2, R7.2, R9.2, R14.1, R28.1, R35.1, RR9.1 (COM), U3.1 (GND), U3.20 (GND), U8.1, U8.18, U9.1, U9.18, U10.1, U10.18, U11.1, U11.18, U39.7 (GND), U43.7 (GND), U43.9, U43.11, U43.13, U47.1 (GND), U47.24 (GND); also elsewhere on the board
unnamed: C51.2, U47.2 (RIN)
unnamed: C52.2, U47.3 (GIN)
unnamed: C53.2, U47.4 (BIN)
unnamed: C54.1, U47.9 (YCLPC)
unnamed: C55.1, R7.1, U47.13 (IREF)
unnamed: C56.2, U3.33 (VBB)
unnamed: C59.1, R43.1
unnamed: C60.1, R44.1
unnamed: C61.1, R45.1
unnamed: C62.1, R46.1
unnamed: C63.1, R47.1
unnamed: C64.1, R48.1
unnamed: C77.1, U47.14 (VREF)
unnamed: C89.2, R2.2, U3.63 (XTAL1), Y1.2
unnamed: C90.2, R30.1, Y3.2
unnamed: C91.1, U47.17 (YTRAP)
unnamed: C91.2, L1.1
unnamed: C92.2, R2.1, U3.64 (XTAL2), Y1.1
unnamed: C93.2, R1.2, U43.1, Y3.1
unnamed: C94.1, R25.1, U47.6 (SCIN)
unnamed: JP3.1, RR9.3
unnamed: JP4.1, U43.6
unnamed: JP4.3, Q2.2 (B), R27.1
unnamed: JP5.2, U47.7 (NTSC/~PAL)
unnamed: JP6.1, U39.6
unnamed: JP6.2, R25.2
unnamed: Q2.3 (C), R28.2, U43.5
unnamed: R1.1, R30.2, U43.2, U43.3
unnamed: R9.1, U47.18 (FO)
unnamed: R37.2, U3.57 (R/~W)
unnamed: R38.2, U3.61 (~CAS0)
unnamed: R39.2, U3.60 (~CAS1)
unnamed: R40.2, U3.62 (~RAS)
unnamed: R43.2, U47.20 (CVOUT)
unnamed: R44.2, U47.15 (COUT)
unnamed: R45.2, U47.16 (YOUT)
unnamed: R46.2, U47.23 (ROUT)
unnamed: R47.2, U47.22 (GOUT)
unnamed: R48.2, U47.21 (BOUT)
unnamed: RR2.9, U3.27 (~LPD)
unnamed: RR3.4, U3.4 (~VDS)
unnamed: RR3.5, U3.59 (~CASX)
unnamed: RR3.6, U3.7 (BLEO)
unnamed: RR3.7, U3.10 (~YS)
VCC: J14.1, Q2.1 (E), R33.2, R36.2, RR2.1 (COM), RR3.1 (COM), U8.9, U9.9, U10.9, U11.9, U39.14 (VCC), U43.14 (VCC); also elsewhere on the board
VCCRGB: JP5.1, U47.12 (VCC), U47.19 (VCC); also elsewhere on the board
VCCVDP: JP3.3, U3.58 (VCC); also elsewhere on the board

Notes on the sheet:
JP3, JP4: 1-2: V9938; 2-3: V9958 (Use a wire link) JP4, JP5: 1-2: NTSC; 2-3: PAL (Use a wire link)
PAL: R9 - 16k, C91 - 18pF R9 - Tolerance 1%
PCB Layout Notes: Keep trace length between CXA1645 and 75 ohm resistors to minimum CXA1645 bypass capacitors: VCC1(12), VREF(14) -> GND1(1), VCC2(19) -> GND2(24)
Optional: PAL Clock Generator
Optional: RGB Output
Install Q2 only for V9938

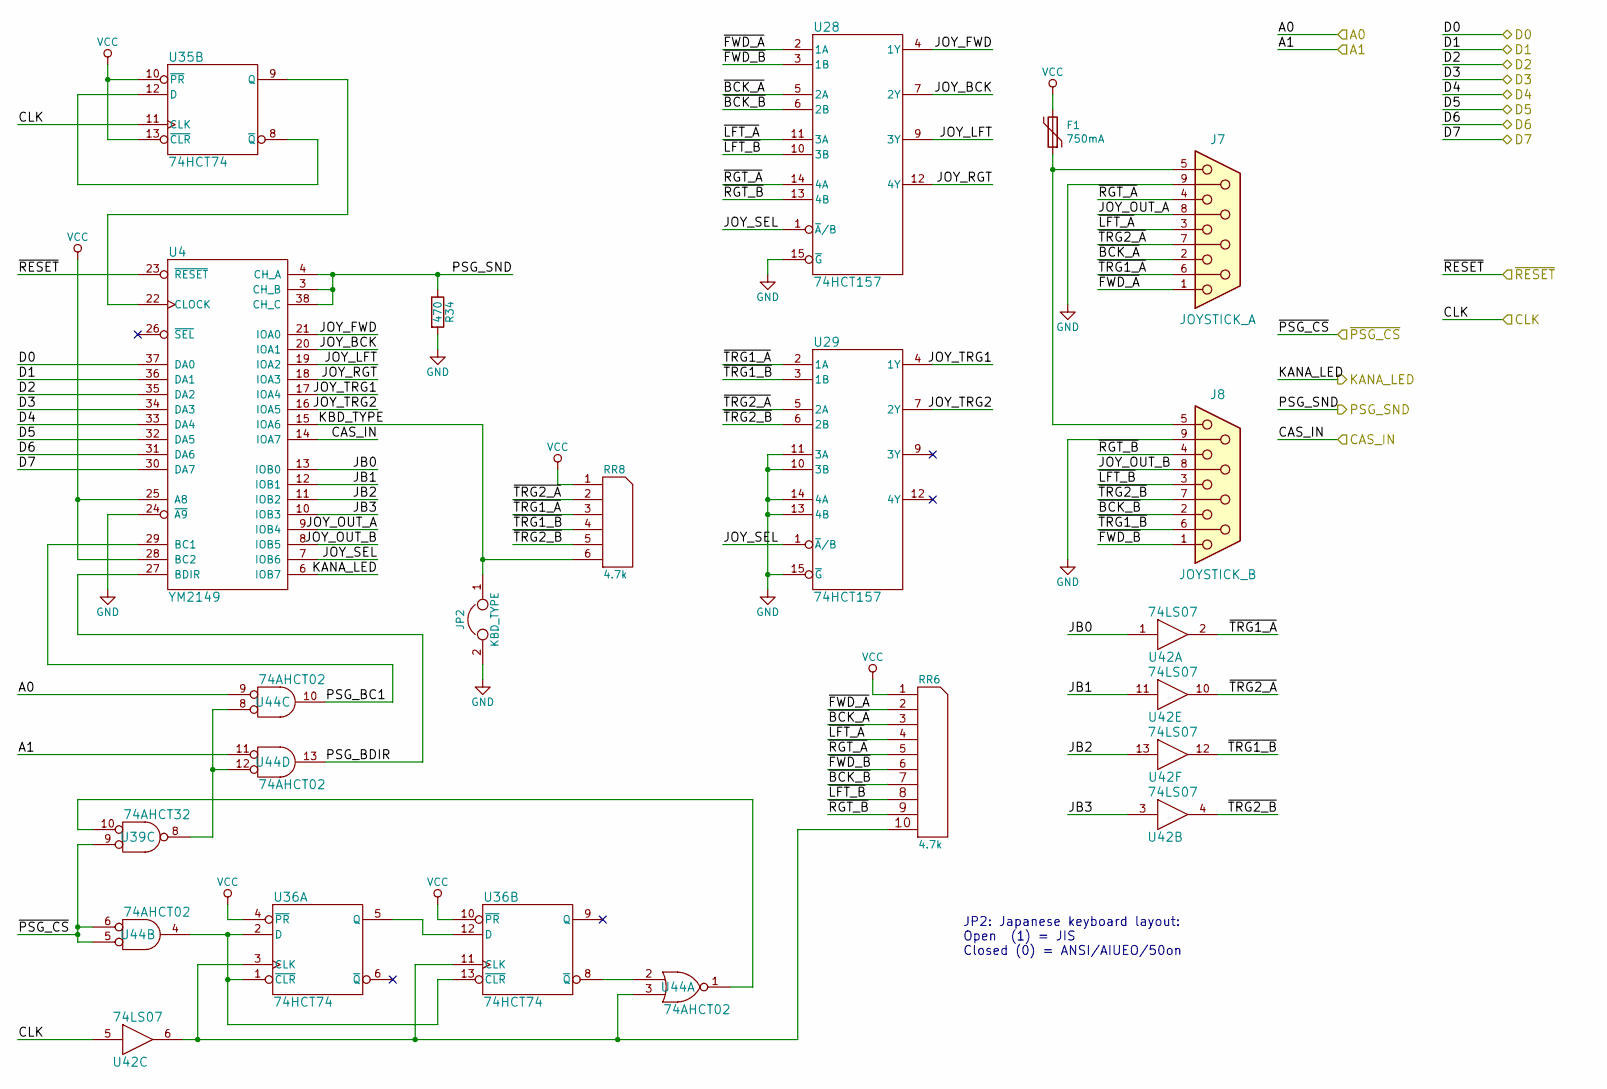
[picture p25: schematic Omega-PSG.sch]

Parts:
F1: 750mA; Cap_Cer_508
J7: JOYSTICK_A; Conn_Dsub_DE9M
J8: JOYSTICK_B; Conn_Dsub_DE9M
JP2: KBD_TYPE; Conn_Pin_Header_2x1_2.54mm
R34: 470; Res_762
RR6: 4.7k; Conn_SIL10
RR8: 4.7k; Conn_SIL6
U4: YM2149; IC_DIP40_600
U28, U29: 74HCT157; IC_DIP16_300
U35, U36: 74HCT74; IC_DIP14_300
U39: 74AHCT32; IC_DIP14_300
U42: 74LS07; IC_DIP14_300
U44: 74AHCT02; IC_DIP14_300

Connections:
/A0: U44.9; also elsewhere on the board
/A1: U44.11; also elsewhere on the board
/CAS_IN: U4.14 (IOA7); also elsewhere on the board
/CLK: U35.11 (CLK), U42.5; also elsewhere on the board
/D0: U4.37 (DA0); also elsewhere on the board
/D1: U4.36 (DA1); also elsewhere on the board
/D2: U4.35 (DA2); also elsewhere on the board
/D3: U4.34 (DA3); also elsewhere on the board
/D4: U4.33 (DA4); also elsewhere on the board
/D5: U4.32 (DA5); also elsewhere on the board
/D6: U4.31 (DA6); also elsewhere on the board
/D7: U4.30 (DA7); also elsewhere on the board
/KANA_LED: U4.6 (IOB7); also elsewhere on the board
/PSG/JB0: U4.13 (IOB0), U42.1
/PSG/JB1: U4.12 (IOB1), U42.11
/PSG/JB2: U4.11 (IOB2), U42.13
/PSG/JB3: U4.10 (IOB3), U42.3
/PSG/JOY_BCK: U4.20 (IOA1), U28.7 (2Y)
/PSG/JOY_FWD: U4.21 (IOA0), U28.4 (1Y)
/PSG/JOY_LFT: U4.19 (IOA2), U28.9 (3Y)
/PSG/JOY_OUT_A: J7.8, U4.9 (IOB4)
/PSG/JOY_OUT_B: J8.8, U4.8 (IOB5)
/PSG/JOY_RGT: U4.18 (IOA3), U28.12 (4Y)
/PSG/JOY_SEL: U4.7 (IOB6), U28.1 (~A~/B), U29.1 (~A~/B)
/PSG/JOY_TRG1: U4.17 (IOA4), U29.4 (1Y)
/PSG/JOY_TRG2: U4.16 (IOA5), U29.7 (2Y)
/PSG/KBD_TYPE: JP2.1, RR8.6, U4.15 (IOA6)
/PSG/PSG_BC1: U4.29 (BC1), U44.10
/PSG/PSG_BDIR: U4.27 (BDIR), U44.13
/PSG/~BCK_A: J7.2, RR6.3, U28.5 (2A)
/PSG/~BCK_B: J8.2, RR6.7, U28.6 (2B)
/PSG/~FWD_A: J7.1, RR6.2, U28.2 (1A)
/PSG/~FWD_B: J8.1, RR6.6, U28.3 (1B)
/PSG/~LFT_A: J7.3, RR6.4, U28.11 (3A)
/PSG/~LFT_B: J8.3, RR6.8, U28.10 (3B)
/PSG/~RGT_A: J7.4, RR6.5, U28.14 (4A)
/PSG/~RGT_B: J8.4, RR6.9, U28.13 (4B)
/PSG/~TRG1_A: J7.6, RR8.3, U29.2 (1A), U42.2
/PSG/~TRG1_B: J8.6, RR8.4, U29.3 (1B), U42.12
/PSG/~TRG2_A: J7.7, RR8.2, U29.5 (2A), U42.10
/PSG/~TRG2_B: J8.7, RR8.5, U29.6 (2B), U42.4
/PSG_SND: R34.1, U4.3 (CH_B), U4.4 (CH_A), U4.38 (CH_C); also elsewhere on the board
/~PSG_CS: U39.9, U44.5, U44.6; also elsewhere on the board
/~RESET: U4.23 (~RESET); also elsewhere on the board
GND: J7.9, J7.GND, J8.9, J8.GND, JP2.2, R34.2, U4.1 (GND), U4.24 (~A9), U28.8 (GND), U28.15 (~G), U29.8 (GND), U29.10 (3B), U29.11 (3A), U29.13 (4B), U29.14 (4A), U29.15 (~G), U35.7 (GND), U36.7 (GND), U39.7 (GND), U42.7 (GND), U44.7 (GND); also elsewhere on the board
unnamed: F1.1, J7.5, J8.5
unnamed: RR6.10, U36.3 (CLK), U36.11 (CLK), U42.6, U44.3
unnamed: U4.22 (CLOCK), U35.9 (Q)
unnamed: U35.8 (~Q), U35.12 (D)
unnamed: U36.1 (~CLR), U36.2 (D), U36.13 (~CLR), U44.4
unnamed: U36.8 (~Q), U44.2
unnamed: U36.5 (Q), U36.12 (D)
unnamed: U39.8, U44.8, U44.12
unnamed: U39.10, U44.1
VCC: F1.2, RR6.1 (COM), RR8.1 (COM), U4.25 (A8), U4.28 (BC2), U4.40 (VCC), U28.16 (VCC), U29.16 (VCC), U35.10 (~PR), U35.13 (~CLR), U35.14 (VCC), U36.4 (~PR), U36.10 (~PR), U36.14 (VCC), U39.14 (VCC), U42.14 (VCC), U44.14 (VCC); also elsewhere on the board

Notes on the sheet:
JP2: Japanese keyboard layout: Open (1) = JIS Closed (0) = ANSI/AIUEO/50on

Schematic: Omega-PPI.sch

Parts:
J11: KEYBOARD; Conn_Pin_Header_8x2_2.54mm
RR7: 4.7k; Conn_SIL10
U2: 82C55; IC_DIP40_600
U13: ATF16V8B; IC_DIP20_300
U22: 74HCT540; IC_DIP20_300
U23: 74HCT273; IC_DIP20_300
U30, U31: 74HCT153; IC_DIP16_300
U38: 74AHCT32; IC_DIP14_300
U40, U41: 74HCT30; IC_DIP14_300
U45: 74HCT00; IC_DIP14_300

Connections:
/A0: U2.9, U40.12; also elsewhere on the board
/A1: U2.8, U40.11; also elsewhere on the board
/A2: U40.6; also elsewhere on the board
/A3: U40.5; also elsewhere on the board
/A4: U40.4; also elsewhere on the board
/A5: U40.3; also elsewhere on the board
/A6: U40.2; also elsewhere on the board
/A7: U40.1; also elsewhere on the board
/A8: U41.11; also elsewhere on the board
/A9: U41.5; also elsewhere on the board
/A10: U41.4; also elsewhere on the board
/A11: U41.6; also elsewhere on the board
/A12: U41.3; also elsewhere on the board
/A13: U41.12; also elsewhere on the board
/A14: U13.2 (I1), U30.14 (A), U31.14 (A), U41.2; also elsewhere on the board
/A15: U13.1 (I/CLK), U30.2 (B), U31.2 (B), U41.1; also elsewhere on the board
/CAS_MOT: U2.13; also elsewhere on the board
/CAS_OUT: U2.12; also elsewhere on the board
/D0: U2.34, U22.18 (~Y1), U23.3 (D0); also elsewhere on the board
/D1: U2.33, U22.17 (~Y2), U23.18 (D7); also elsewhere on the board
/D2: U2.32, U22.16 (~Y3), U23.17 (D6); also elsewhere on the board
/D3: U2.31, U22.15 (~Y4), U23.4 (D1); also elsewhere on the board
/D4: U2.30, U22.14 (~Y5), U23.7 (D2); also elsewhere on the board
/D5: U2.29, U22.13 (~Y6), U23.14 (D5); also elsewhere on the board
/D6: U2.28, U22.12 (~Y7), U23.13 (D4); also elsewhere on the board
/D7: U2.27, U22.11 (~Y8), U23.8 (D3); also elsewhere on the board
/KANA_LED: J11.14; also elsewhere on the board
/KEY_CLICK: U2.10; also elsewhere on the board
/PPI/CAPS_LED: J11.12, U2.11
/PPI/COLUMN0: J11.1, RR7.2, U2.18
/PPI/COLUMN1: J11.3, RR7.3, U2.19
/PPI/COLUMN2: J11.5, RR7.4, U2.20
/PPI/COLUMN3: J11.7, RR7.5, U2.21
/PPI/COLUMN4: J11.9, RR7.6, U2.22
/PPI/COLUMN5: J11.11, RR7.7, U2.23
/PPI/COLUMN6: J11.13, RR7.8, U2.24
/PPI/COLUMN7: J11.15, RR7.9, U2.25
/PPI/ROW_A: J11.4, U2.14
/PPI/ROW_B: J11.6, U2.15
/PPI/ROW_C: J11.8, U2.16
/PPI/ROW_D: J11.10, U2.17
/PPI/SB_SLT_A: U13.6 (I5), U31.7 (1Y)
/PPI/SB_SLT_B: U13.7 (I6), U31.9 (2Y)
/PPI/SLT_A: U13.8 (I7), U30.7 (1Y)
/PPI/SLT_B: U13.9 (I8), U30.9 (2Y)
/PPI/~FFFF: U13.5 (I4), U38.2, U38.6
/PPI/~SLTSL3: U13.17 (I/O3), U38.1
/PPI/~SUB_RD: U22.1 (~G1), U22.19 (~G2), U38.11
/PPI/~SUB_REG_CS: U38.3, U38.10, U38.12
/PPI/~SUB_WR: U23.11 (CP), U38.8
/PRT_BUSY: RR7.10; also elsewhere on the board
/RESET: U2.35; also elsewhere on the board
/ROM_A16: U13.13 (I/O7); also elsewhere on the board
/ROM_A17: U13.12 (I/O8); also elsewhere on the board
/~MEM_RD: U13.16 (I/O4); also elsewhere on the board
/~MREQ: U13.3 (I2); also elsewhere on the board
/~PPI_CS: U2.6, U45.4; also elsewhere on the board
/~RAM_SL: U13.15 (I/O5); also elsewhere on the board
/~RD: U2.5, U13.11 (I9/~OE), U38.13; also elsewhere on the board
/~RESET: U23.1 (~MR), U45.2; also elsewhere on the board
/~RFSH: U13.4 (I3); also elsewhere on the board
/~ROM_CS: U13.14 (I/O6); also elsewhere on the board
/~SLTSL1: U13.19 (I/O1); also elsewhere on the board
/~SLTSL2: U13.18 (I/O2); also elsewhere on the board
/~WR: U2.36, U38.9; also elsewhere on the board
GND: J11.16, U2.7, U13.10 (GND), U22.10 (GND), U23.10 (GND), U30.8 (GND), U31.1 (~1G), U31.8 (GND), U31.15 (~2G), U38.7 (GND), U40.7 (GND), U41.7 (GND), U45.7 (GND); also elsewhere on the board
unnamed: U2.1, U30.11 (2C1)
unnamed: U2.2, U30.5 (1C1)
unnamed: U2.3, U30.10 (2C0)
unnamed: U2.4, U30.6 (1C0)
unnamed: U2.37, U30.13 (2C3)
unnamed: U2.38, U30.3 (1C3)
unnamed: U2.39, U30.12 (2C2)
unnamed: U2.40, U30.4 (1C2)
unnamed: U22.2 (A1), U23.2 (Q0), U31.6 (1C0)
unnamed: U22.3 (A2), U23.19 (Q7), U31.10 (2C0)
unnamed: U22.4 (A3), U23.16 (Q6), U31.5 (1C1)
unnamed: U22.5 (A4), U23.5 (Q1), U31.11 (2C1)
unnamed: U22.6 (A5), U23.6 (Q2), U31.4 (1C2)
unnamed: U22.7 (A6), U23.15 (Q5), U31.12 (2C2)
unnamed: U22.8 (A7), U23.12 (Q4), U31.3 (1C3)
unnamed: U22.9 (A8), U23.9 (Q3), U31.13 (2C3)
unnamed: U30.1 (~1G), U30.15 (~2G), U45.3, U45.5
unnamed: U38.4, U41.8
unnamed: U38.5, U40.8
unnamed: U45.1, U45.6
VCC: J11.2, RR7.1 (COM), U2.26, U13.20 (VCC), U22.20 (VCC), U23.20 (VCC), U30.16 (VCC), U31.16 (VCC), U38.14 (VCC), U40.14 (VCC), U41.14 (VCC), U45.14 (VCC); also elsewhere on the board

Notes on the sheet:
Keyboard Pull-ups

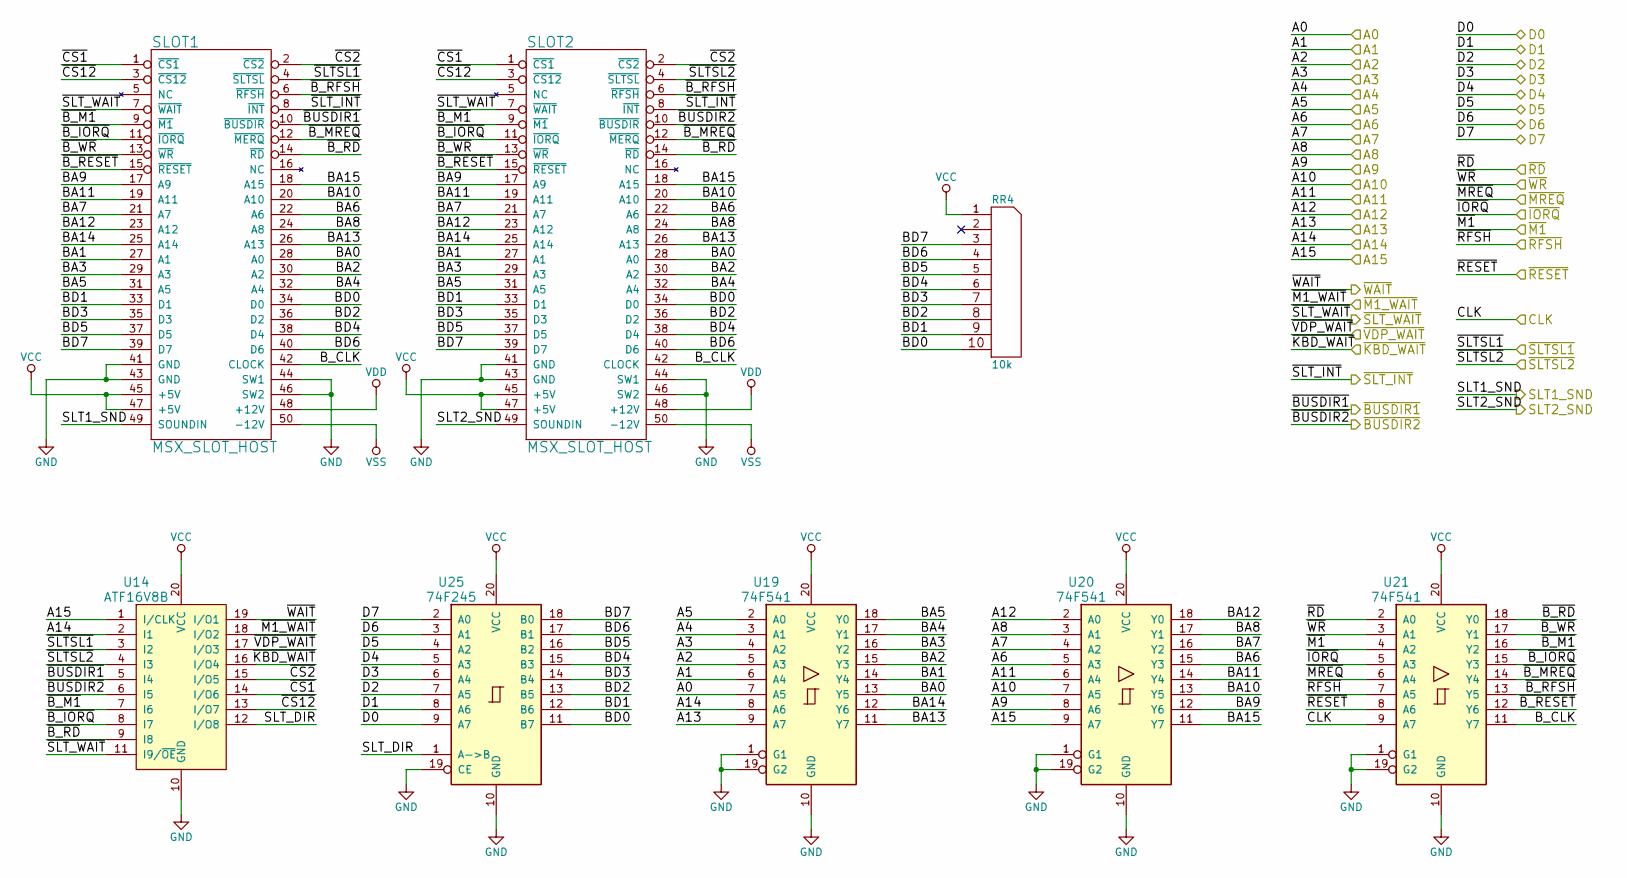
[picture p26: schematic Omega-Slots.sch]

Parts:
RR4: 10k; Conn_SIL10
SLOT1, SLOT2: MSX_SLOT_HOST; Conn_Edge_50P
U14: ATF16V8B; IC_DIP20_300
U19, U20, U21: 74F541; IC_DIP20_300
U25: 74F245; IC_DIP20_300

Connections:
/A0: U19.7 (A5); also elsewhere on the board
/A1: U19.6 (A4); also elsewhere on the board
/A2: U19.5 (A3); also elsewhere on the board
/A3: U19.4 (A2); also elsewhere on the board
/A4: U19.3 (A1); also elsewhere on the board
/A5: U19.2 (A0); also elsewhere on the board
/A6: U20.5 (A3); also elsewhere on the board
/A7: U20.4 (A2); also elsewhere on the board
/A8: U20.3 (A1); also elsewhere on the board
/A9: U20.8 (A6); also elsewhere on the board
/A10: U20.7 (A5); also elsewhere on the board
/A11: U20.6 (A4); also elsewhere on the board
/A12: U20.2 (A0); also elsewhere on the board
/A13: U19.9 (A7); also elsewhere on the board
/A14: U14.2 (I1), U19.8 (A6); also elsewhere on the board
/A15: U14.1 (I/CLK), U20.9 (A7); also elsewhere on the board
/CLK: U21.9 (A7); also elsewhere on the board
/D0: U25.9 (A7); also elsewhere on the board
/D1: U25.8 (A6); also elsewhere on the board
/D2: U25.7 (A5); also elsewhere on the board
/D3: U25.6 (A4); also elsewhere on the board
/D4: U25.5 (A3); also elsewhere on the board
/D5: U25.4 (A2); also elsewhere on the board
/D6: U25.3 (A1); also elsewhere on the board
/D7: U25.2 (A0); also elsewhere on the board
/SLT1_SND: SLOT1.49 (SOUNDIN); also elsewhere on the board
/SLT2_SND: SLOT2.49 (SOUNDIN); also elsewhere on the board
/Slots/BA0: SLOT1.28 (A0), SLOT2.28 (A0), U19.13 (Y5)
/Slots/BA1: SLOT1.27 (A1), SLOT2.27 (A1), U19.14 (Y4)
/Slots/BA2: SLOT1.30 (A2), SLOT2.30 (A2), U19.15 (Y3)
/Slots/BA3: SLOT1.29 (A3), SLOT2.29 (A3), U19.16 (Y2)
/Slots/BA4: SLOT1.32 (A4), SLOT2.32 (A4), U19.17 (Y1)
/Slots/BA5: SLOT1.31 (A5), SLOT2.31 (A5), U19.18 (Y0)
/Slots/BA6: SLOT1.22 (A6), SLOT2.22 (A6), U20.15 (Y3)
/Slots/BA7: SLOT1.21 (A7), SLOT2.21 (A7), U20.16 (Y2)
/Slots/BA8: SLOT1.24 (A8), SLOT2.24 (A8), U20.17 (Y1)
/Slots/BA9: SLOT1.17 (A9), SLOT2.17 (A9), U20.12 (Y6)
/Slots/BA10: SLOT1.20 (A10), SLOT2.20 (A10), U20.13 (Y5)
/Slots/BA11: SLOT1.19 (A11), SLOT2.19 (A11), U20.14 (Y4)
/Slots/BA12: SLOT1.23 (A12), SLOT2.23 (A12), U20.18 (Y0)
/Slots/BA13: SLOT1.26 (A13), SLOT2.26 (A13), U19.11 (Y7)
/Slots/BA14: SLOT1.25 (A14), SLOT2.25 (A14), U19.12 (Y6)
/Slots/BA15: SLOT1.18 (A15), SLOT2.18 (A15), U20.11 (Y7)
/Slots/BD0: RR4.10, SLOT1.34 (D0), SLOT2.34 (D0), U25.11 (B7)
/Slots/BD1: RR4.9, SLOT1.33 (D1), SLOT2.33 (D1), U25.12 (B6)
/Slots/BD2: RR4.8, SLOT1.36 (D2~), SLOT2.36 (D2~), U25.13 (B5)
/Slots/BD3: RR4.7, SLOT1.35 (D3), SLOT2.35 (D3), U25.14 (B4)
/Slots/BD4: RR4.6, SLOT1.38 (D4), SLOT2.38 (D4), U25.15 (B3)
/Slots/BD5: RR4.5, SLOT1.37 (D5), SLOT2.37 (D5), U25.16 (B2)
/Slots/BD6: RR4.4, SLOT1.40 (D6), SLOT2.40 (D6), U25.17 (B1)
/Slots/BD7: RR4.3, SLOT1.39 (D7), SLOT2.39 (D7), U25.18 (B0)
/Slots/B_CLK: SLOT1.42 (CLOCK), SLOT2.42 (CLOCK), U21.11 (Y7)
/Slots/SLT_DIR: U14.12 (I/O8), U25.1 (A->B)
/Slots/~B_IORQ: SLOT1.11 (~IORQ), SLOT2.11 (~IORQ), U14.8 (I7), U21.15 (Y3)
/Slots/~B_M1: SLOT1.9 (~M1), SLOT2.9 (~M1), U14.7 (I6), U21.16 (Y2)
/Slots/~B_MREQ: SLOT1.12 (~MERQ), SLOT2.12 (~MERQ), U21.14 (Y4)
/Slots/~B_RD: SLOT1.14 (~RD), SLOT2.14 (~RD), U14.9 (I8), U21.18 (Y0)
/Slots/~B_RESET: SLOT1.15 (~RESET), SLOT2.15 (~RESET), U21.12 (Y6)
/Slots/~B_RFSH: SLOT1.6 (~RFSH), SLOT2.6 (~RFSH), U21.13 (Y5)
/Slots/~B_WR: SLOT1.13 (~WR), SLOT2.13 (~WR), U21.17 (Y1)
/Slots/~CS1: SLOT1.1 (~CS1), SLOT2.1 (~CS1), U14.14 (I/O6)
/Slots/~CS2: SLOT1.2 (~CS2), SLOT2.2 (~CS2), U14.15 (I/O5)
/Slots/~CS12: SLOT1.3 (~CS12), SLOT2.3 (~CS12), U14.13 (I/O7)
/~BUSDIR1: SLOT1.10 (~BUSDIR), U14.5 (I4); also elsewhere on the board
/~BUSDIR2: SLOT2.10 (~BUSDIR), U14.6 (I5); also elsewhere on the board
/~IORQ: U21.5 (A3); also elsewhere on the board
/~KBD_WAIT: U14.16 (I/O4); also elsewhere on the board
/~M1: U21.4 (A2); also elsewhere on the board
/~M1_WAIT: U14.18 (I/O2); also elsewhere on the board
/~MREQ: U21.6 (A4); also elsewhere on the board
/~RD: U21.2 (A0); also elsewhere on the board
/~RESET: U21.8 (A6); also elsewhere on the board
/~RFSH: U21.7 (A5); also elsewhere on the board
/~SLTSL1: SLOT1.4 (~SLTSL), U14.3 (I2); also elsewhere on the board
/~SLTSL2: SLOT2.4 (~SLTSL), U14.4 (I3); also elsewhere on the board
/~SLT_INT: SLOT1.8 (~INT), SLOT2.8 (~INT); also elsewhere on the board
/~SLT_WAIT: SLOT1.7 (~WAIT), SLOT2.7 (~WAIT), U14.11 (I9/~OE); also elsewhere on the board
/~VDP_WAIT: U14.17 (I/O3); also elsewhere on the board
/~WAIT: U14.19 (I/O1); also elsewhere on the board
/~WR: U21.3 (A1); also elsewhere on the board
GND: SLOT1.41 (GND), SLOT1.43 (GND), SLOT1.44 (SW1), SLOT1.46 (SW2), SLOT2.41 (GND), SLOT2.43 (GND), SLOT2.44 (SW1), SLOT2.46 (SW2), U14.10 (GND), U19.1 (G1), U19.10 (GND), U19.19 (G2), U20.1 (G1), U20.10 (GND), U20.19 (G2), U21.1 (G1), U21.10 (GND), U21.19 (G2), U25.10 (GND), U25.19 (CE); also elsewhere on the board
VCC: RR4.1 (COM), SLOT1.45 (+5V), SLOT1.47 (+5V), SLOT2.45 (+5V), SLOT2.47 (+5V), U14.20 (VCC), U19.20 (VCC), U20.20 (VCC), U21.20 (VCC), U25.20 (VCC); also elsewhere on the board
VDD: SLOT1.48 (+12V), SLOT2.48 (+12V); also elsewhere on the board
VSS: SLOT1.50 (-12V), SLOT2.50 (-12V); also elsewhere on the board

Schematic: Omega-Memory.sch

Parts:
J12: RAM_EXT; Conn_Pin_Header_20x2_2.54mm
JP1: ROM_A18; Conn_Pin_Header_2x1_2.54mm
JP7, JP8: RAM_SIZE; Conn_Pin_Header_2x3_2.54mm
R13: 10k; Res_762
RR10: 4.7k; Conn_SIL6
U6: SST39SF040; IC_DIP32_600
U7: AS6C4008; IC_DIP32_600
U15, U16, U17, U18: 74HCT670; IC_DIP16_300
U26: 74F245; IC_DIP20_300
U32: 74AHCT138; IC_DIP16_300
U37: 74AHCT32; IC_DIP14_300

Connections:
/A0: J12.31, U6.12 (A0), U7.12 (A0), U15.5 (Ra), U15.14 (Wa), U16.5 (Ra), U16.14 (Wa), U17.14 (Wa), U18.14 (Wa); also elsewhere on the board
/A1: J12.29, U6.11 (A1), U7.11 (A1), U15.4 (Rb), U15.13 (Wb), U16.4 (Rb), U16.13 (Wb), U17.13 (Wb), U18.13 (Wb); also elsewhere on the board
/A2: J12.27, U6.10 (A2), U7.10 (A2); also elsewhere on the board
/A3: J12.25, U6.9 (A3), U7.9 (A3); also elsewhere on the board
/A4: J12.23, U6.8 (A4), U7.8 (A4); also elsewhere on the board
/A5: J12.21, U6.7 (A5), U7.7 (A5); also elsewhere on the board
/A6: J12.19, U6.6 (A6), U7.6 (A6); also elsewhere on the board
/A7: J12.17, U6.5 (A7), U7.5 (A7); also elsewhere on the board
/A8: J12.20, U6.27 (A8), U7.27 (A8); also elsewhere on the board
/A9: J12.22, U6.26 (A9), U7.26 (A9); also elsewhere on the board
/A10: J12.28, U6.23 (A10), U7.23 (A10); also elsewhere on the board
/A11: J12.24, U6.25 (A11), U7.25 (A11); also elsewhere on the board
/A12: J12.15, U6.4 (A12), U7.4 (A12); also elsewhere on the board
/A13: J12.18, U6.28 (A13), U7.28 (A13); also elsewhere on the board
/A14: U6.29 (A14), U17.5 (Ra), U18.5 (Ra); also elsewhere on the board
/A15: U6.3 (A15), U17.4 (Rb), U18.4 (Rb); also elsewhere on the board
/D0: U16.3 (D4), U16.6 (Q4), U18.3 (D4), U26.9 (A7); also elsewhere on the board
/D1: U16.2 (D3), U16.7 (Q3), U18.2 (D3), U26.8 (A6); also elsewhere on the board
/D2: U16.1 (D2), U16.9 (Q2), U18.1 (D2), U26.7 (A5); also elsewhere on the board
/D3: U16.10 (Q1), U16.15 (D1), U18.15 (D1), U26.6 (A4); also elsewhere on the board
/D4: U15.3 (D4), U15.6 (Q4), U17.3 (D4), U26.5 (A3); also elsewhere on the board
/D5: JP8.5, JP8.6, U15.2 (D3), U15.7 (Q3), U17.2 (D3), U26.4 (A2); also elsewhere on the board
/D6: JP8.1, JP8.2, U15.10 (Q1), U15.15 (D1), U17.15 (D1), U26.3 (A1); also elsewhere on the board
/D7: JP8.3, JP8.4, U15.1 (D2), U15.9 (Q2), U17.1 (D2), U26.2 (A0); also elsewhere on the board
/Memory/MD0: J12.33, U6.13 (DQ0), U7.13 (DQ0), U26.11 (B7)
/Memory/MD1: J12.35, U6.14 (DQ1), U7.14 (DQ1), U26.12 (B6)
/Memory/MD2: J12.37, U6.15 (DQ2), U7.15 (DQ2), U26.13 (B5)
/Memory/MD3: J12.38, U6.17 (DQ3), U7.17 (DQ3), U26.14 (B4)
/Memory/MD4: J12.36, U6.18 (DQ4), U7.18 (DQ4), U26.15 (B3)
/Memory/MD5: J12.34, U6.19 (DQ5), U7.19 (DQ5), U26.16 (B2)
/Memory/MD6: J12.32, U6.20 (DQ6), U7.20 (DQ6), U26.17 (B1)
/Memory/MD7: J12.30, U6.21 (DQ7), U7.21 (DQ7), U26.18 (B0)
/Memory/RAM_A14: J12.13, U7.3 (A14), U18.6 (Q4)
/Memory/RAM_A15: J12.12, U7.31 (A15), U18.7 (Q3)
/Memory/RAM_A16: J12.11, U7.2 (A16), U18.9 (Q2)
/Memory/RAM_A17: J12.14, U7.30 (A17), U18.10 (Q1)
/Memory/RAM_A18: J12.9, U7.1 (A18), U17.6 (Q4)
/Memory/RAM_A19: JP7.1, JP7.2, RR10.2, U17.7 (Q3), U32.1 (A0)
/Memory/RAM_A20: JP7.3, JP7.4, RR10.3, U17.10 (Q1), U32.2 (A1)
/Memory/RAM_A21: JP7.5, JP7.6, RR10.4, U17.9 (Q2), U32.3 (A2)
/Memory/ROM_A18: JP1.2, R13.1, U6.1 (A18)
/Memory/~PAGE_RD: U15.11 (~Er), U16.11 (~Er), U37.3
/Memory/~PAGE_WR: U15.12 (~Ew), U16.12 (~Ew), U17.12 (~Ew), U18.12 (~Ew), U37.11
/Memory/~RAM0_CS: U7.22 (~CE), U32.15 (O0)
/Memory/~RAM1_CS: J12.4, U32.14 (O1)
/Memory/~RAM2_CS: J12.3, U32.13 (O2)
/Memory/~RAM3_CS: J12.6, U32.12 (O3)
/Memory/~RAM4_CS: J12.5, U32.11 (O4)
/Memory/~RAM5_CS: J12.8, U32.10 (O5)
/Memory/~RAM6_CS: J12.7, U32.9 (O6)
/Memory/~RAM7_CS: J12.10, U32.7 (O7)
/ROM_A16: U6.2 (A16); also elsewhere on the board
/ROM_A17: U6.30 (A17); also elsewhere on the board
/~MEM_RD: U26.1 (A->B); also elsewhere on the board
/~PAGE_CS: U37.2, U37.12; also elsewhere on the board
/~RAM_SL: U32.4 (E1), U32.5 (E2); also elsewhere on the board
/~RD: J12.26, U6.24 (~OE), U7.24 (~OE), U37.1; also elsewhere on the board
/~ROM_CS: U6.22 (~CE); also elsewhere on the board
/~WR: J12.16, U6.31 (~WE), U7.29 (~WE), U37.13; also elsewhere on the board
GND: J12.39, J12.40, R13.2, RR10.1 (COM), U6.16 (GND), U7.16 (GND), U15.8 (GND), U16.8 (GND), U17.8 (GND), U17.11 (~Er), U18.8 (GND), U18.11 (~Er), U26.10 (GND), U26.19 (CE), U32.8 (GND), U37.7 (GND); also elsewhere on the board
VCC: J12.1, J12.2, JP1.1, U6.32 (VCC), U7.32 (VCC), U15.16 (VCC), U16.16 (VCC), U17.16 (VCC), U18.16 (VCC), U26.20 (VCC), U32.6 (E3), U32.16 (VCC), U37.14 (VCC); also elsewhere on the board

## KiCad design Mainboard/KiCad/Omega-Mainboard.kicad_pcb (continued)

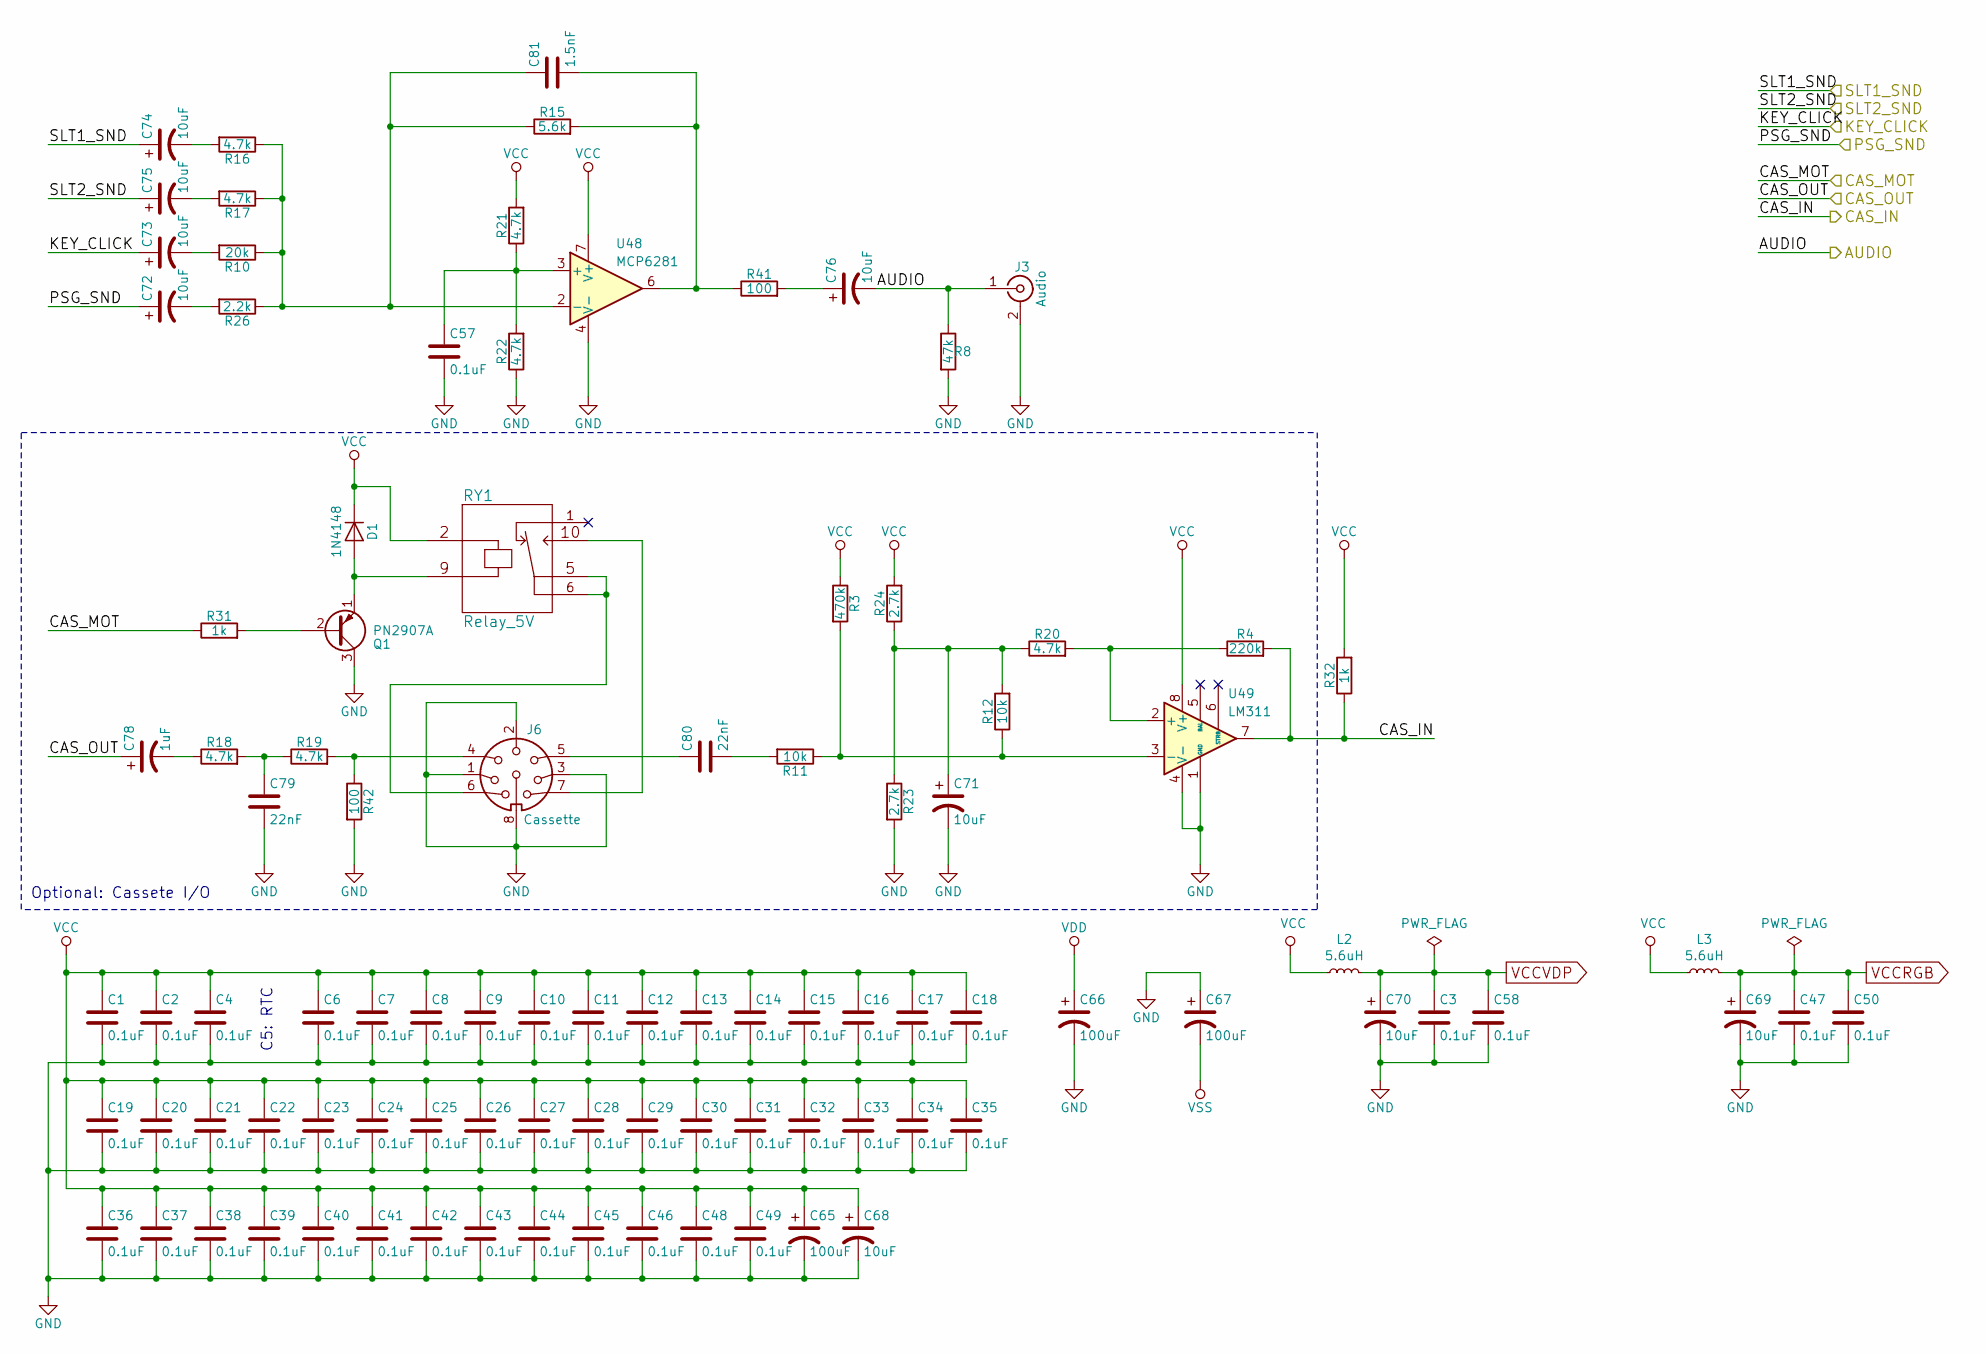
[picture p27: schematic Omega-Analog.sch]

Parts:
C1, C2, C3, C4, C6, C7, C8, C9, C10, C11, C12, C13, C14, C15, C16, C17, C18, C19, C20, C21, C22, C23, C24, C25, C26, C27, C28, C29, C30, C31, C32, C33, C34, C35, C36, C37, C38, C39, C40, C41, C42, C43, C44, C45, C46, C47, C48, C49, C50, C57, C58: 0.1uF; Cap_Cer_508
C65, C66, C67: 100uF; Cap_Elec_Radial_6.3mm
C68, C69, C70: 10uF; Cap_Pol_508_3
C71, C72, C73, C74, C75, C76: 10uF; Cap_Elec_Radial_5mm
C78: 1uF; Cap_Elec_Radial_5mm
C79, C80: 22nF; Cap_Cer_508
C81: 1.5nF; Cap_Cer_508
D1: 1N4148; Diode_762
J3: Audio; Conn_RCA_Right
J6: Cassette; Conn_DIN_8pin
L2, L3: 5.6uH; Res_762
Q1: PN2907A; Transistor_TO92_EBC_254
R3: 470k; Res_762
R4: 220k; Res_762
R8: 47k; Res_762
R10: 20k; Res_762
R11, R12: 10k; Res_762
R15: 5.6k; Res_762
R16, R17, R18, R19, R20, R21, R22: 4.7k; Res_762
R23, R24: 2.7k; Res_762
R26: 2.2k; Res_762
R31, R32: 1k; Res_762
R41, R42: 100; Res_762
RY1: Relay_5V; Relay_SPDT
U48: MCP6281; IC_DIP8_300
U49: LM311; IC_DIP8_300

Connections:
/AUDIO: C76.2, J3.1 (In), R8.1; also elsewhere on the board
/CAS_IN: R4.2, R32.1, U49.7; also elsewhere on the board
/CAS_MOT: R31.1; also elsewhere on the board
/CAS_OUT: C78.1; also elsewhere on the board
/KEY_CLICK: C73.1; also elsewhere on the board
/PSG_SND: C72.1; also elsewhere on the board
/SLT1_SND: C74.1; also elsewhere on the board
/SLT2_SND: C75.1; also elsewhere on the board
GND: C1.2, C2.2, C3.2, C4.2, C6.2, C7.2, C8.2, C9.2, C10.2, C11.2, C12.2, C13.2, C14.2, C15.2, C16.2, C17.2, C18.2, C19.2, C20.2, C21.2, C22.2, C23.2, C24.2, C25.2, C26.2, C27.2, C28.2, C29.2, C30.2, C31.2, C32.2, C33.2, C34.2, C35.2, C36.2, C37.2, C38.2, C39.2, C40.2, C41.2, C42.2, C43.2, C44.2, C45.2, C46.2, C47.2, C48.2, C49.2, C50.2, C57.2, C58.2, C65.2, C66.2, C67.1, C68.2, C69.2, C70.2, C71.2, C79.2, J3.2 (Ext), J6.1, J6.2, J6.3, J6.8, J6.~, Q1.3 (C), R8.2, R22.1, R23.2, R42.2, U48.4 (V-), U49.1 (GND), U49.4 (V-); also elsewhere on the board
unnamed: C57.1, R21.1, R22.2, U48.3 (+)
unnamed: C71.1, R12.2, R20.1, R23.1, R24.1
unnamed: C72.2, R26.2
unnamed: C73.2, R10.2
unnamed: C74.2, R16.2
unnamed: C75.2, R17.2
unnamed: C76.1, R41.2
unnamed: C78.2, R18.1
unnamed: C79.1, R18.2, R19.1
unnamed: C80.1, J6.5
unnamed: C80.2, R11.2
unnamed: C81.1, R10.1, R15.1, R16.1, R17.1, R26.1, U48.2 (-)
unnamed: C81.2, R15.2, R41.1, U48.6
unnamed: D1.2 (A), Q1.1 (E), RY1.9
unnamed: J6.4, R19.2, R42.1
unnamed: J6.6, RY1.5, RY1.6
unnamed: J6.7, RY1.10
unnamed: Q1.2 (B), R31.2
unnamed: R3.2, R11.1, R12.1, U49.3 (-)
unnamed: R4.1, R20.2, U49.2 (+)
VCC: C1.1, C2.1, C4.1, C6.1, C7.1, C8.1, C9.1, C10.1, C11.1, C12.1, C13.1, C14.1, C15.1, C16.1, C17.1, C18.1, C19.1, C20.1, C21.1, C22.1, C23.1, C24.1, C25.1, C26.1, C27.1, C28.1, C29.1, C30.1, C31.1, C32.1, C33.1, C34.1, C35.1, C36.1, C37.1, C38.1, C39.1, C40.1, C41.1, C42.1, C43.1, C44.1, C45.1, C46.1, C48.1, C49.1, C65.1, C68.1, D1.1 (K), L2.1, L3.1, R3.1, R21.2, R24.2, R32.2, RY1.2, U48.7 (V+), U49.8 (V+); also elsewhere on the board
VCCRGB: C47.1, C50.1, C69.1, L3.2; also elsewhere on the board
VCCVDP: C3.1, C58.1, C70.1, L2.2; also elsewhere on the board
VDD: C66.1; also elsewhere on the board
VSS: C67.2; also elsewhere on the board

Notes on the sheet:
C5: RTC
Optional: Cassete I/O

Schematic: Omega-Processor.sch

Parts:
BT1: CR2032; Battery_Holder_CR2032_Universal
C5: 0.1uF; Cap_Cer_508
C86, C87: 33pF; Cap_Cer_508
C88: 30pF; C_Trim_Murata
J9: PRINTER; Conn_Micro_Ribbon_14F
J13: ~RST~/~NMI; Conn_Pin_Header_2x2_2.54mm
R5, R6: 100k; Res_762
R29: 1k; Res_762
RR1: 10k; Conn_SIL10
RR5: 4.7k; Conn_SIL10
U1: Z84C00; IC_DIP40_600
U5: RP5C01; IC_DIP18_300
U12: ATF16V8B; IC_DIP20_300
U24: 74HCT273; IC_DIP20_300
U27: 74HCT175; IC_DIP16_300
U33: 74AHCT125; IC_DIP14_300
U34, U35: 74HCT74; IC_DIP14_300
U37: 74AHCT32; IC_DIP14_300
U42: 74LS07; IC_DIP14_300
U45: 74HCT00; IC_DIP14_300
U46: ADM691A; IC_DIP16_300
Y2: 32768 Hz; Crystal_32K_Horiz

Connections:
/A0: U1.30, U12.9 (I8); also elsewhere on the board
/A1: U1.31; also elsewhere on the board
/A2: U1.32, U12.8 (I7); also elsewhere on the board
/A3: U1.33, U12.7 (I6); also elsewhere on the board
/A4: U1.34, U12.6 (I5); also elsewhere on the board
/A5: U1.35, U12.5 (I4); also elsewhere on the board
/A6: U1.36, U12.4 (I3); also elsewhere on the board
/A7: U1.37, U12.3 (I2); also elsewhere on the board
/A8: U1.38; also elsewhere on the board
/A9: U1.39; also elsewhere on the board
/A10: U1.40; also elsewhere on the board
/A11: U1.1; also elsewhere on the board
/A12: U1.2; also elsewhere on the board
/A13: U1.3; also elsewhere on the board
/A14: U1.4; also elsewhere on the board
/A15: U1.5; also elsewhere on the board
/CLK: U42.9; also elsewhere on the board
/D0: RR1.3, U1.14, U5.11 (D0), U24.17 (D6), U27.5 (D1), U35.2 (D); also elsewhere on the board
/D1: RR1.4, U1.15, U5.12 (D1), U24.14 (D5), U27.4 (D0), U33.3; also elsewhere on the board
/D2: RR1.5, U1.12, U5.13 (D2), U24.4 (D1), U27.12 (D2); also elsewhere on the board
/D3: RR1.6, U1.8, U5.14 (D3), U24.7 (D2), U27.13 (D3); also elsewhere on the board
/D4: RR1.7, U1.7, U24.13 (D4); also elsewhere on the board
/D5: RR1.8, U1.9, U24.8 (D3); also elsewhere on the board
/D6: RR1.9, U1.10, U24.18 (D7); also elsewhere on the board
/D7: RR1.10, U1.13, U24.3 (D0); also elsewhere on the board
/PRT_BUSY: J9.11, U33.2; also elsewhere on the board
/Processor/ALARM: RR1.2, U5.15 (~ALARM)
/Processor/PD0: J9.2, U24.16 (Q6)
/Processor/PD1: J9.3, U24.15 (Q5)
/Processor/PD2: J9.4, U24.5 (Q1)
/Processor/PD3: J9.5, U24.6 (Q2)
/Processor/PD4: J9.6, U24.12 (Q4)
/Processor/PD5: J9.7, U24.9 (Q3)
/Processor/PD6: J9.8, U24.19 (Q7)
/Processor/PD7: J9.9, U24.2 (Q0)
/Processor/RTC_VCC: C5.1, U5.2 (CS), U5.18 (VCC), U46.2
/Processor/~BUSREQ: RR5.3, U1.25
/Processor/~INT: U1.16, U45.8
/Processor/~NMI: J13.3, RR5.4, U1.17
/Processor/~PRT_BSY_RD: U33.1, U37.6
/Processor/~PRT_CMD_CS: U12.13 (I/O7), U37.5, U37.10
/Processor/~PRT_DAT_WR: U12.12 (I/O8), U24.11 (CP)
/Processor/~PRT_STB_WR: U35.3 (CLK), U37.8
/Processor/~RTC_AD_WR: U12.17 (I/O3), U27.9 (CP)
/Processor/~RTC_CS: U12.16 (I/O4), U46.13
/Processor/~RTC_CS_B: U5.1 (~CS), U46.12
/Processor/~STROBE: J9.1, U35.5 (Q)
/RESET: U46.16; also elsewhere on the board
/~BUSDIR1: RR5.7; also elsewhere on the board
/~BUSDIR2: RR5.6; also elsewhere on the board
/~IORQ: U1.20, U12.2 (I1); also elsewhere on the board
/~KBD_WAIT: RR5.2; also elsewhere on the board
/~M1: U1.27, U12.11 (I9/~OE), U34.2 (D); also elsewhere on the board
/~M1_WAIT: U34.5 (Q), U34.12 (D); also elsewhere on the board
/~MREQ: U1.19; also elsewhere on the board
/~PAGE_CS: U12.15 (I/O5); also elsewhere on the board
/~PPI_CS: U12.14 (I/O6); also elsewhere on the board
/~PSG_CS: U12.19 (I/O1); also elsewhere on the board
/~RD: U1.21, U5.8 (~RD), U37.4; also elsewhere on the board
/~RESET: J13.1, U1.26, U24.1 (~MR), U27.1 (~MR), U35.4 (~PR), U46.15; also elsewhere on the board
/~RFSH: U1.28; also elsewhere on the board
/~SLT_INT: RR5.9, U45.13; also elsewhere on the board
/~SLT_WAIT: RR5.10; also elsewhere on the board
/~VDP_CS: U12.18 (I/O2); also elsewhere on the board
/~VDP_INT: U45.12; also elsewhere on the board
/~WAIT: U1.24; also elsewhere on the board
/~WR: U1.22, U5.10 (~WR), U12.1 (I/CLK), U37.9; also elsewhere on the board
GND: BT1.2 (-), C5.2, C86.1, C87.1, C88.1, J9.14, J9.GND, J13.2, J13.4, R6.2, U1.29, U5.9 (GND), U12.10 (GND), U24.10 (GND), U27.8 (GND), U33.4, U33.5, U33.7 (GND), U33.9, U33.10, U33.12, U33.13, U34.7 (GND), U35.7 (GND), U37.7 (GND), U42.7 (GND), U45.7 (GND), U46.4, U46.9, Y2.~; also elsewhere on the board
unnamed: BT1.1 (+), U46.1
unnamed: C86.2, R5.1, U5.17 (OSCOUT)
unnamed: C87.2, R5.2, Y2.2
unnamed: C88.2, U5.16 (OSCIN), Y2.1
unnamed: R6.1, U5.3 (ADJ)
unnamed: R29.2, U1.6, U34.3 (CLK), U34.11 (CLK), U42.8
unnamed: U5.5 (A1), U27.2 (Q0)
unnamed: U5.4 (A0), U27.7 (Q1)
unnamed: U5.6 (A2), U27.10 (Q2)
unnamed: U5.7 (A3), U27.15 (Q3)
unnamed: U34.4 (~PR), U34.9 (Q)
unnamed: U45.9, U45.10, U45.11
VCC: R29.1, RR1.1 (COM), RR5.1 (COM), U1.11, U12.20 (VCC), U24.20 (VCC), U27.16 (VCC), U33.14 (VCC), U34.1 (~CLR), U34.10 (~PR), U34.13 (~CLR), U34.14 (VCC), U35.1 (~CLR), U35.14 (VCC), U37.14 (VCC), U42.14 (VCC), U45.14 (VCC), U46.3; also elsewhere on the board

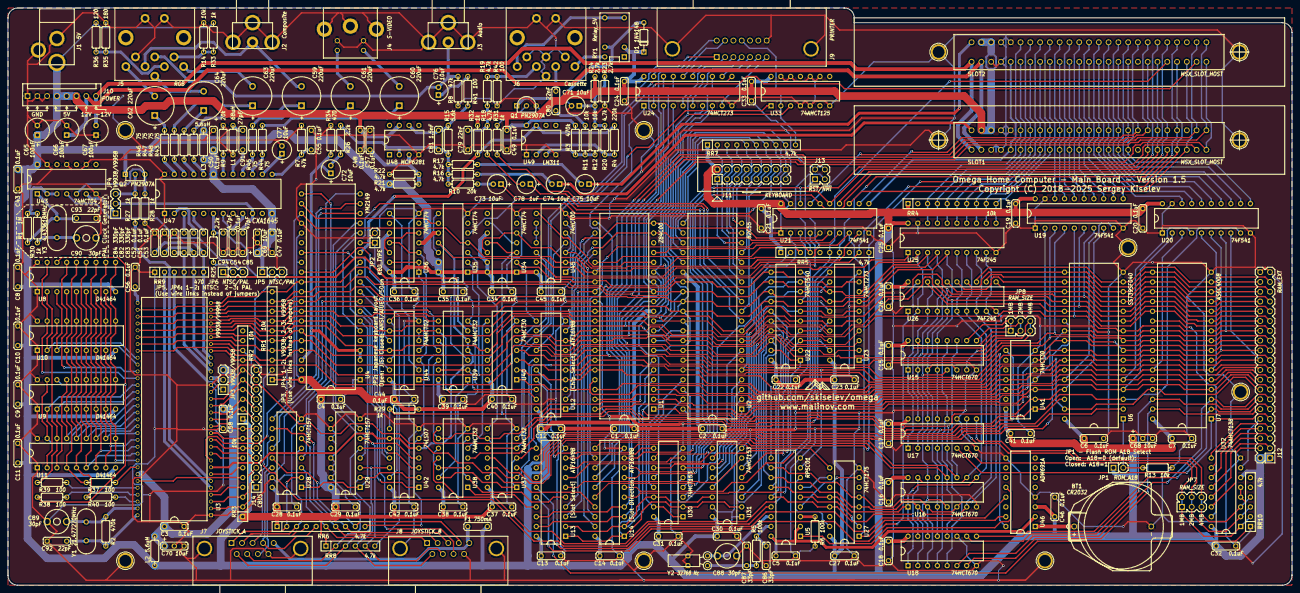
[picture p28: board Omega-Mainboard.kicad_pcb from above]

Board: 2 copper layers, 333.4 x 149.9 mm, 248 parts (0 on the bottom side), 357 nets.

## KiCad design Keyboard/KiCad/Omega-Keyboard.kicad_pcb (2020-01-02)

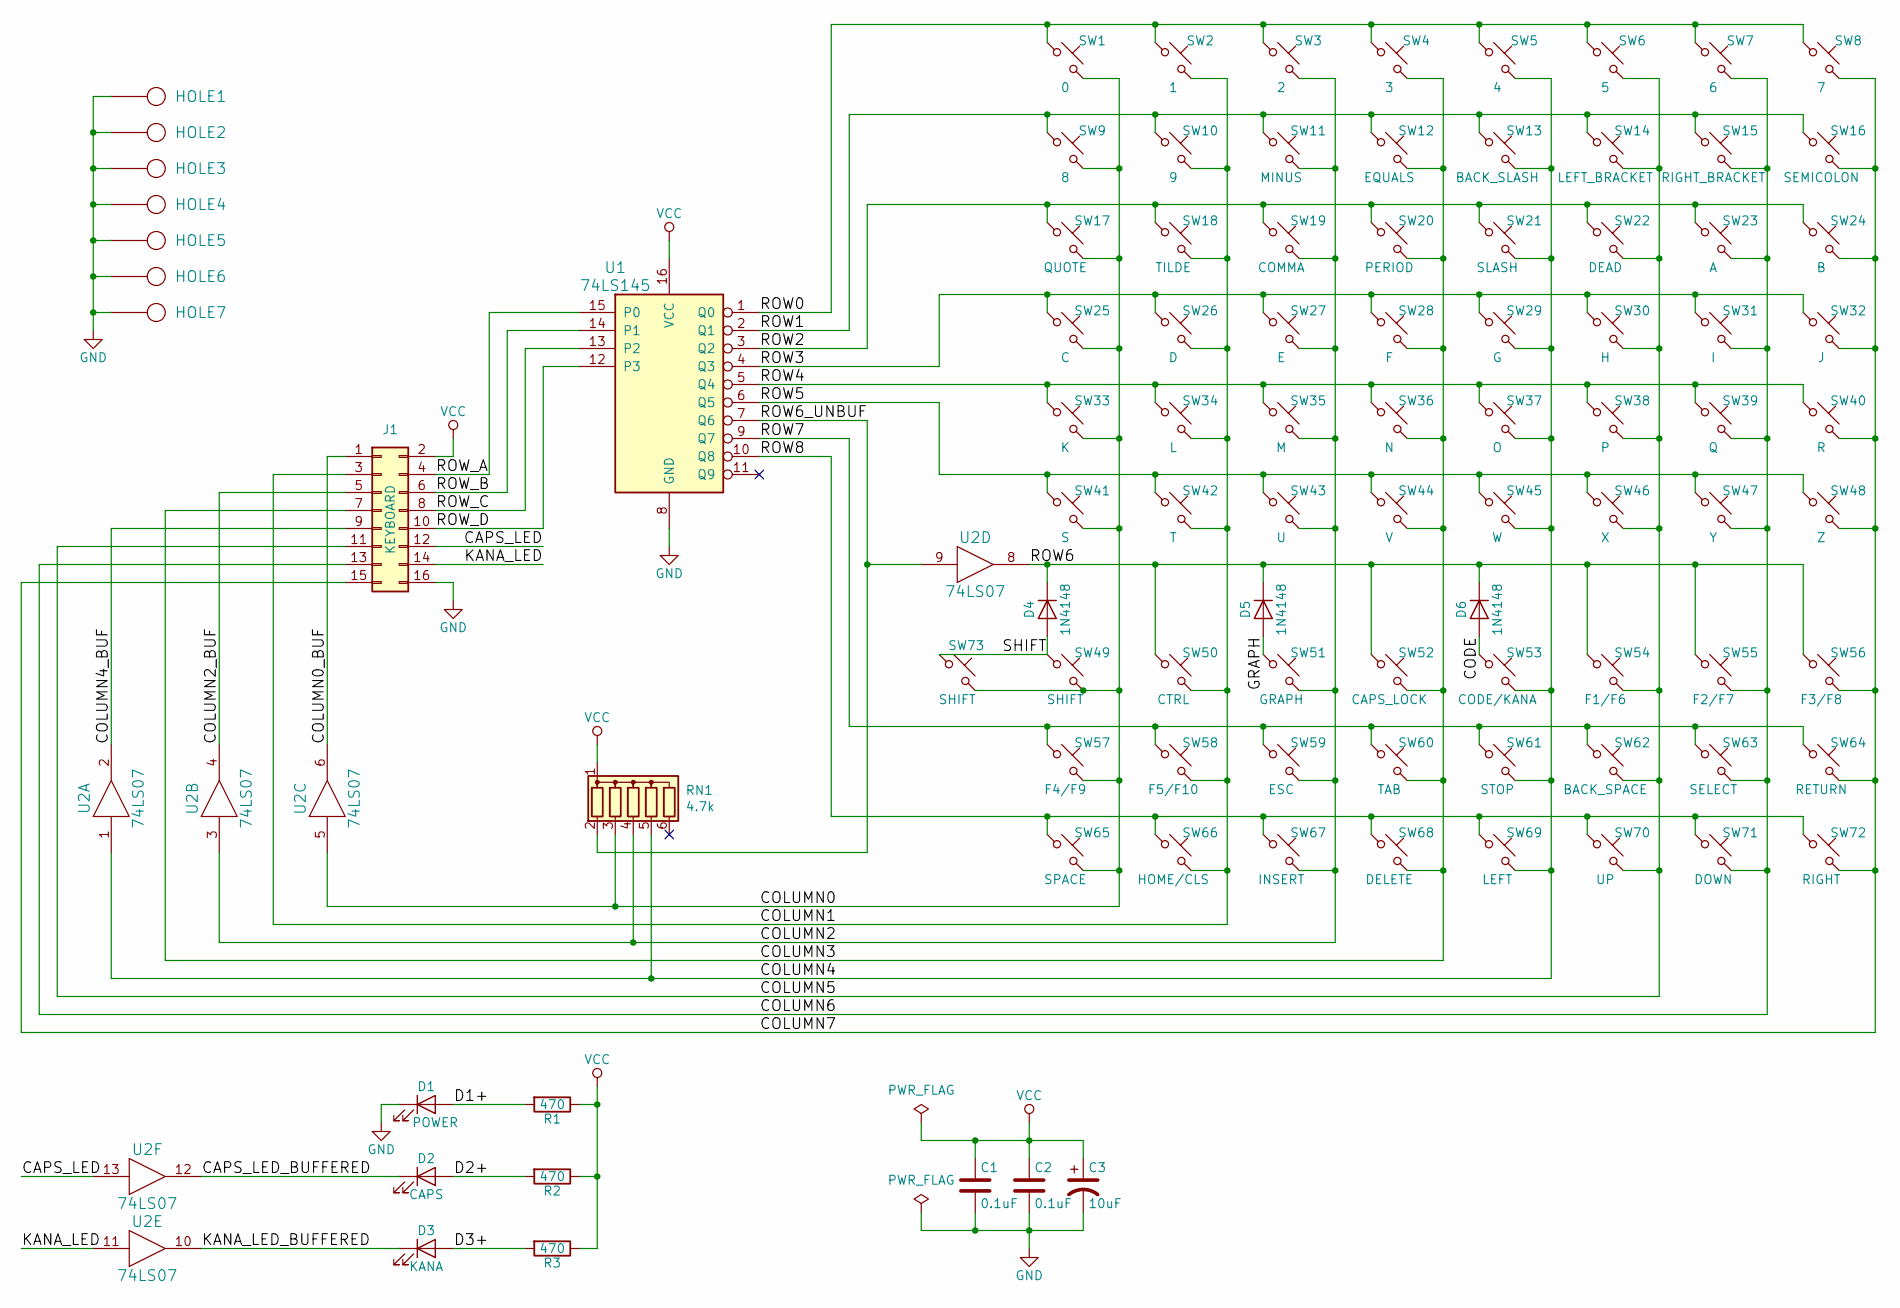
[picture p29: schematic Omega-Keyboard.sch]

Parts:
C1, C2: 0.1uF; Cap_Cer_508
C3: 10uF; Cap_Tant_508
D1: POWER; LED_3mm
D2: CAPS; CHERRY_MX_LED
D3: KANA; CHERRY_MX_LED
D4, D5, D6: 1N4148; Diode_762
HOLE1, HOLE2, HOLE3, HOLE4, HOLE5, HOLE6, HOLE7: HOLE; Hole_3mm
J1: KEYBOARD; Conn_Pin_Header_8x2_2.54mm
R1, R2, R3: 470; Res_762
RN1: 4.7k; Conn_SIL6
SW1: 0; CHERRY_PCB_100H
SW2: 1; CHERRY_PCB_100H
SW3: 2; CHERRY_PCB_100H
SW4: 3; CHERRY_PCB_100H
SW5: 4; CHERRY_PCB_100H
SW6: 5; CHERRY_PCB_100H
SW7: 6; CHERRY_PCB_100H
SW8: 7; CHERRY_PCB_100H
SW9: 8; CHERRY_PCB_100H
SW10: 9; CHERRY_PCB_100H
SW11: MINUS; CHERRY_PCB_100H
SW12: EQUALS; CHERRY_PCB_100H
SW13: BACK_SLASH; CHERRY_PCB_150H
SW14: LEFT_BRACKET; CHERRY_PCB_100H
SW15: RIGHT_BRACKET; CHERRY_PCB_100H
SW16: SEMICOLON; CHERRY_PCB_100H
SW17: QUOTE; CHERRY_PCB_100H
SW18: TILDE; CHERRY_PCB_100H
SW19: COMMA; CHERRY_PCB_100H
SW20: PERIOD; CHERRY_PCB_100H
SW21: SLASH; CHERRY_PCB_100H
SW22: DEAD; CHERRY_PCB_125H
SW23: A; CHERRY_PCB_100H
SW24: B; CHERRY_PCB_100H
SW25: C; CHERRY_PCB_100H
SW26: D; CHERRY_PCB_100H
SW27: E; CHERRY_PCB_100H
SW28: F; CHERRY_PCB_100H
SW29: G; CHERRY_PCB_100H
SW30: H; CHERRY_PCB_100H
SW31: I; CHERRY_PCB_100H
SW32: J; CHERRY_PCB_100H
SW33: K; CHERRY_PCB_100H
SW34: L; CHERRY_PCB_100H
SW35: M; CHERRY_PCB_100H
SW36: N; CHERRY_PCB_100H
SW37: O; CHERRY_PCB_100H
SW38: P; CHERRY_PCB_100H
SW39: Q; CHERRY_PCB_100H
SW40: R; CHERRY_PCB_100H
SW41: S; CHERRY_PCB_100H
SW42: T; CHERRY_PCB_100H
SW43: U; CHERRY_PCB_100H
SW44: V; CHERRY_PCB_100H
SW45: W; CHERRY_PCB_100H
SW46: X; CHERRY_PCB_100H
SW47: Y; CHERRY_PCB_100H
SW48: Z; CHERRY_PCB_100H
SW49: SHIFT; CHERRY_PCB_225H
SW50: CTRL; CHERRY_PCB_125H
SW51: GRAPH; CHERRY_PCB_125H
SW52: CAPS_LOCK; CHERRY_PCB_175H
SW53: CODE/KANA; CHERRY_PCB_125H
SW54: F1/F6; CHERRY_PCB_100H
SW55: F2/F7; CHERRY_PCB_100H
SW56: F3/F8; CHERRY_PCB_100H
SW57: F4/F9; CHERRY_PCB_100H
SW58: F5/F10; CHERRY_PCB_100H
SW59: ESC; CHERRY_PCB_100H
SW60: TAB; CHERRY_PCB_150H
SW61: STOP; CHERRY_PCB_100H
SW62: BACK_SPACE; CHERRY_PCB_200H
SW63: SELECT; CHERRY_PCB_125H
SW64: RETURN; CHERRY_PCB_225H
SW65: SPACE; CHERRY_PCB_625H
SW66: HOME/CLS; CHERRY_PCB_100H
SW67: INSERT; CHERRY_PCB_100H
SW68: DELETE; CHERRY_PCB_100H
SW69: LEFT; CHERRY_PCB_100H
SW70: UP; CHERRY_PCB_100H
SW71: DOWN; CHERRY_PCB_100H
SW72: RIGHT; CHERRY_PCB_100H
SW73: SHIFT; CHERRY_PCB_275H
U1: 74LS145; IC_DIP16_300
U2: 74LS07; IC_DIP14_300

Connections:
/CAPS_LED: J1.12, U2.13
/CAPS_LED_BUFFERED: D2.1 (K), U2.12
/CODE: D6.2 (A), SW53.1
/COLUMN0: RN1.3 (R2), SW1.2, SW9.2, SW17.2, SW25.2, SW33.2, SW41.2, SW49.2, SW57.2, SW65.2, SW73.2, U2.5
/COLUMN0_BUF: J1.1, U2.6
/COLUMN1: J1.3, SW2.2, SW10.2, SW18.2, SW26.2, SW34.2, SW42.2, SW50.2, SW58.2, SW66.2
/COLUMN2: RN1.4 (R3), SW3.2, SW11.2, SW19.2, SW27.2, SW35.2, SW43.2, SW51.2, SW59.2, SW67.2, U2.3
/COLUMN2_BUF: J1.5, U2.4
/COLUMN3: J1.7, SW4.2, SW12.2, SW20.2, SW28.2, SW36.2, SW44.2, SW52.2, SW60.2, SW68.2
/COLUMN4: RN1.5 (R4), SW5.2, SW13.2, SW21.2, SW29.2, SW37.2, SW45.2, SW53.2, SW61.2, SW69.2, U2.1
/COLUMN4_BUF: J1.9, U2.2
/COLUMN5: J1.11, SW6.2, SW14.2, SW22.2, SW30.2, SW38.2, SW46.2, SW54.2, SW62.2, SW70.2
/COLUMN6: J1.13, SW7.2, SW15.2, SW23.2, SW31.2, SW39.2, SW47.2, SW55.2, SW63.2, SW71.2
/COLUMN7: J1.15, SW8.2, SW16.2, SW24.2, SW32.2, SW40.2, SW48.2, SW56.2, SW64.2, SW72.2
/D1+: D1.2 (A), R1.2
/D2+: D2.2 (A), R2.2
/D3+: D3.2 (A), R3.2
/GRAPH: D5.2 (A), SW51.1
/KANA_LED: J1.14, U2.11
/KANA_LED_BUFFERED: D3.1 (K), U2.10
/ROW0: SW1.1, SW2.1, SW3.1, SW4.1, SW5.1, SW6.1, SW7.1, SW8.1, U1.1 (Q0)
/ROW1: SW9.1, SW10.1, SW11.1, SW12.1, SW13.1, SW14.1, SW15.1, SW16.1, U1.2 (Q1)
/ROW2: SW17.1, SW18.1, SW19.1, SW20.1, SW21.1, SW22.1, SW23.1, SW24.1, U1.3 (Q2)
/ROW3: SW25.1, SW26.1, SW27.1, SW28.1, SW29.1, SW30.1, SW31.1, SW32.1, U1.4 (Q3)
/ROW4: SW33.1, SW34.1, SW35.1, SW36.1, SW37.1, SW38.1, SW39.1, SW40.1, U1.5 (Q4)
/ROW5: SW41.1, SW42.1, SW43.1, SW44.1, SW45.1, SW46.1, SW47.1, SW48.1, U1.6 (Q5)
/ROW6: D4.1 (K), D5.1 (K), D6.1 (K), SW50.1, SW52.1, SW54.1, SW55.1, SW56.1, U2.8
/ROW6_UNBUF: RN1.2 (R1), U1.7 (Q6), U2.9
/ROW7: SW57.1, SW58.1, SW59.1, SW60.1, SW61.1, SW62.1, SW63.1, SW64.1, U1.9 (Q7)
/ROW8: SW65.1, SW66.1, SW67.1, SW68.1, SW69.1, SW70.1, SW71.1, SW72.1, U1.10 (Q8)
/ROW_A: J1.4, U1.15 (P0)
/ROW_B: J1.6, U1.14 (P1)
/ROW_C: J1.8, U1.13 (P2)
/ROW_D: J1.10, U1.12 (P3)
/SHIFT: D4.2 (A), SW49.1, SW73.1
GND: C1.2, C2.2, C3.2, D1.1 (K), HOLE1.1, HOLE2.1, HOLE3.1, HOLE4.1, HOLE5.1, HOLE6.1, HOLE7.1, J1.16, U1.8 (GND), U2.7 (GND)
VCC: C1.1, C2.1, C3.1, J1.2, R1.1, R2.1, R3.1, RN1.1 (common), U1.16 (VCC), U2.14 (VCC)

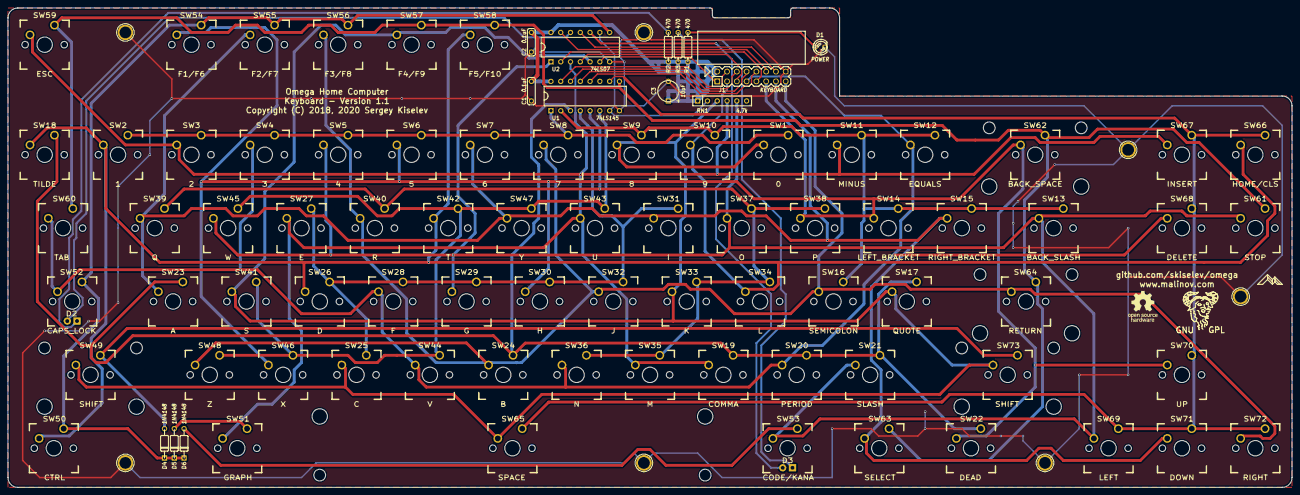
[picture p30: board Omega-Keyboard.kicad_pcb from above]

Board: 2 copper layers, 333.4 x 124.5 mm, 96 parts (0 on the bottom side), 37 nets.

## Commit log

2019-01-18 Add BOM
2019-03-21 Keyboard: Add photo and links to schematic and PCB
2019-03-21 Add keyboard design files
    [Omega-Keyboard.kicad_pcb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]
2019-09-09 Mainboard: Populate KiCad and SPLD files
    [Omega-Analog.sch, Omega-Mainboard.kicad_pcb, Omega-Mainboard.sch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]
2019-09-11 Mainboard: Update to version 1.0
    [Omega-Mainboard.kicad_pcb, Omega-PSG.sch, Omega-Processor.sch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]
2019-09-11 Mainboard: Add Gerber files
    [Omega-Mainboard-B_Cu.gbr, Omega-Mainboard-B_Mask.gbr, Omega-Mainboard-B_SilkS.gbr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]
2019-09-18 README: Update current status
2019-09-18 Keyboard: Add a known issue with missing pull up resistors
2019-09-18 Mainboard: Swap references for R8 and R36 and values for C48 and C82
    [Omega-Mainboard.kicad_pcb]
2019-09-18 Mainboard: Expand PAL Clock Gen dotted line to include U43 and C43
    [Omega-Mainboard.kicad_pcb]
2019-09-18 Motherboard: Initial BOM
2019-09-18 Mainboard: BoM: Add Mouser part numbers for ICs
2019-09-19 Mainboard: BoM: Add Mouser part numbers for resistors, capacitors, and discrete semiconductors
2019-09-19 Mainboard: BoM: Add Mouser part numbers for most components
2019-09-26 Mainboard: Add slot map
2019-09-27 Mainboard: Update slot map
2019-09-30 Mainboard: Add issues discovered during v1.0 board debug
2019-09-30 Mainboard: Fix the issues discovered so far
    [Omega-Mainboard-B_Cu.gbr, Omega-Mainboard-B_Mask.gbr, Omega-Mainboard-B_SilkS.gbr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]
2019-10-02 Mainboard: Add compiled fuse maps for slot select SPLD
2019-10-03 Keyboard: Fix the J1 pin numbers where pull-ups should be connected
2019-10-09 Mainboard: Fixed schematic and PCB for v1.1
    [Omega-Analog.sch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]
2019-10-09 Mainboard: Update slot_dir.pld due to schematic change
2019-10-10 Mainboard: Update BoM for v1.1
2019-10-10 Mainboard: Improve I/O ports and slots sections
2019-10-14 Mainboard: Change audio filter op amp to lower-cost MCP601-I/P
2019-10-14 Mainboard: Update schematic and PCB layout with latest fixes
    [Omega-Analog.sch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]
2019-10-14 Mainboard: Update C92-C95 capacitors
2019-10-16 Mainboard: Renumber capacitors
2019-10-17 Mainboard: Replace RGB and Cassette connectors with DIN8
    [Omega-Analog.sch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]
2019-10-17 Mainboard: Renumber resistors
2019-10-17 Mainboard: Document RGB and Cassette connectors
2019-10-17 Mainboard: Document connectors
2019-10-19 Mainboard: Fix some of the issues described in #1
    [Omega-Analog.sch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]
2019-10-19 Mainboard: Update components to match the latest schematic update
2019-10-19 Mainboard: Swap slots, use trmp cap for RTC, add color bus
    [Omega-Mainboard-B_Cu.gbr, Omega-Mainboard-B_Mask.gbr, Omega-Mainboard-B_SilkS.gbr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]
2019-10-29 Mainboard: Final v1.1 design files
    [Omega-Analog.sch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]
2019-10-30 Mainboard: Update BoM for the final v1.1 release; Update Changes
2019-10-30 Mainboard: BOM: Correct C68 - C70 part number
2019-10-30 Mainboard: Add description for connectors and jumpers
2019-11-27 Mainboard: It should be 7 x 1k resistors
2020-01-02 Keyboard: PCB v1.1 updates
    [Omega-Keyboard-B.Cu.gbr, Omega-Keyboard-B_Cu.gbr, Omega-Keyboard-B_Mask.gbr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]
2020-01-02 Mainboard: Update to version 1.2
    [Omega-Analog.sch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]
2020-02-19 Mainboard: Update socket type for U47.
2020-02-19 Mainboard: Default to 600 mil socket for U47
2020-02-28 Enclosure: Add design files
    [Omega-Eco1_User.dxf, Omega-Eco2_User.dxf, Omega-Slots_Guide.scad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]
2020-02-29 README: Add link to Enclosure
2020-03-22 Mainboard: Map entire 0x10000-0x1FFFF range of Flash ROM to slot 3-0
2020-03-27 Enclosure: Add link to Spanish version
2020-03-27 Enclosure: Add link to English version
2020-03-28 Enclosure: Use button socket cap screws
2020-03-28 Master spanish (#10)
    * Update Enclosure_es.md
    * Update Enclosure.md
2020-03-29 Enclosure: Add slots for hex nuts in the slot guide
    [Omega-Slots_Guide.scad, Omega-Slots_Guide.stl]
2020-07-01 Updated 120 ohm axial label to be "291-120-RC" to match the link and … (#11)
    * Updated 120 ohm axial label to be "291-120-RC" to match the link and value
    * add alternate pin strips for U3 socket
2020-07-09 Update omega-slot_dir.pld (#13)
    Hi,
    There is a problem in the /CS2 formula that unable 32K cartridges from running. The correct formula would be /CS2 = /A14 + A15 instead of /CS2 = /A14 + A14
2020-07-09 Add Checking for ROM Presence (#12)
    * add tests to make sure required ROMs are present
    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
2020-07-10 SPLDs: Update fuse maps for slot dir
2021-01-21 Add files for version 1.3eu from Jordi Solis
    [Omega-Analog.sch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]
2021-01-21 Version 1.4: Add cut-out for the right angle slot connector. Add optional jumpers to limit memory mapper address range
    [Omega-Analog.sch, Omega-Mainboard.kicad_pcb, Omega-Mainboard.sch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]
2021-02-23 Add gerber files for motherboard v1.4
    [Omega-Mainboard-B_Cu.gbr, Omega-Mainboard-B_Mask.gbr, Omega-Mainboard-B_SilkS.gbr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]
2021-07-28 Add G5V-1-DC5 as an alternate relay type
2021-07-28 Update resistors and resistor arrays parts to these available in single quantities from Mouser
2021-07-28 Update 75 ohm part name
2022-01-04 Use the same D1 part as the English BOM
2023-06-28 Add note about replacing C93 with a wire link when using V9938 in NTSC mode
2023-10-12 Add DigiKey alternates for the DIP sockets, fix Markdown link. (#51)
    Also, add link to DigiKey trim capacitor.
2025-05-01 Fix issue #56, where joystick A trigger 2 was swapped with joystick B trigger 1
    [Omega-Mainboard.kicad_pcb, Omega-Memory.sch, Omega-PPI.sch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]
2025-05-01 Describe changes in v1.5, update links to schematic and PCB printouts
2025-05-01 Update links to schematic and PCB printouts
2025-05-01 Update gerber files for version 1.5
    [Omega-Mainboard-B_Cu.gbr, Omega-Mainboard-B_Mask.gbr, Omega-Mainboard-B_SilkS.gbr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]
2026-02-05 Mainboard.md: BoM: Update a couple of discontinued components
2026-02-05 Mainboard_es.md: BoM: Update a couple of discontinued components
2026-02-05 Create Omega-Eco2_User_5mm_Higher.dxf (#55)
    Create sides 5mm higher to give added clearance to the internals for various needs.
    [Omega-Eco2_User_5mm_Higher.dxf]

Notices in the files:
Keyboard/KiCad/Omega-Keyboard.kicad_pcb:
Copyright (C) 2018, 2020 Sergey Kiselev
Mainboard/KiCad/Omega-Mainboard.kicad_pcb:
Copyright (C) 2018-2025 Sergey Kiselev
